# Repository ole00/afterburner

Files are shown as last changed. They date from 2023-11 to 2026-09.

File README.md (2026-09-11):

# afterburner
GAL chip programmer for Arduino
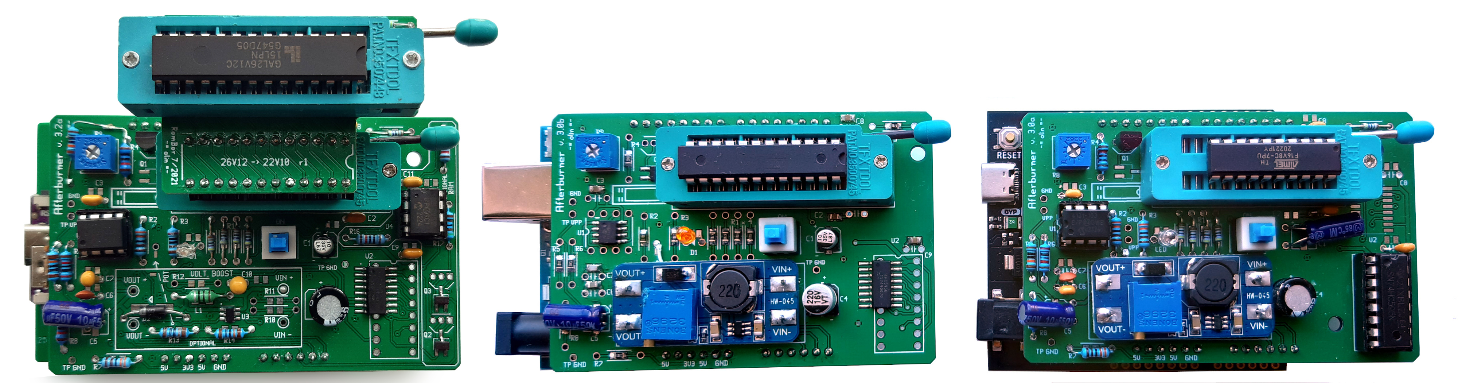
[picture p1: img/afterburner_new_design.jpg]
Board image afterburner


This is a GAL IC programmer software that allows to program GAL IC chips
from various manufcaturers. It is based on work of several other people:

 Bruce Abbott: 
     https://web.archive.org/web/20220121030038/http://www.bhabbott.net.nz/atfblast.html

 Manfred Winterhoff: 
     http://www.armory.com/%7Erstevew/Public/Pgmrs/GAL/_ClikMe1st.htm
 
 Yorck Thiele:
     https://www.ythiee.com/2021/06/06/galmate-hardware/

 Michael Dreher:
     https://github.com/nospam2000/afterburner.git
 
 Marcelo Roberto Jimenez: (JTAG player)
     https://github.com/mrjimenez/JTAG

 whitequark · it: (ATF150X jed to svf tool)
     https://github.com/whitequark/prjbureau

 OpenOCD: (svf to xsvf tool)
     https://github.com/arduino/OpenOCD/blob/master/contrib/xsvf_tools/svf2xsvf.py

who did the most of the hard work of deciphering and publishing the programming
protocol of these chips. Some of their early programs were Windows based and relied on
presence of parallel port (LPT). Afterburner was written for Linux OS 
(also works on Win32/64, Mac OSX64), and requires serial connection to
Arduino UNO, which does the programming of the GAL chip.

**Update: ver.0.6.2 added experimental support for PEEL18CV8. An dapter is required to
program PEEL devices because of their non-trivial programming voltages. The adapter
is located in the gerbers and design directories. Do not attempt to program the
PEEL device on Afterburner without the adapter! PEEL devices do not seem to have
a way to identify them, therefore the 'i' command is not supported.**

**Excerciser adapter was added to the collection of Afterburner adapters. The adapter
helps to develop and debug the PLD desgins on GAL/PEEL ICs. See Discussions for
more information.**

**Update: ver.0.6.0 added experimental support for ATF1502AS and ATF1504AS. Only
identify, erase and write commands are supported. Read function is unsupported.
Verification is usually done automatically - it is a part of the .xsvf JTAG file
which is used when writing the design. See Discussions for more information**

**Update: ver.0.5.8 improved calibration alogrithm and resolution for mcp4151 digi pot.
Please re-calibrate your Afterburner as the previsouly stored calibration data are invalid.**

Supported GAL and PEEL chips:
---------------------

| | Atmel | Lattice | Others ||
| --- | --- | --- | --- | --- |
| 16V8 | ATF16V8B, ATF16V8BQL, ATF16V8C | GAL16V8A, GAL16V8B, GAL16V8D | National GAL16V8, ST&nbsp;GAL16V8 |
| 18CV8 | - | - | ICT PEEL 18CV8P[2][4] |
| 18V10 | - | GAL18V10, GAL18V10B[1] | - |
| 20V8 | ATF20V8B | GAL20V8B | National GAL20V8 |
| 20RA10 | - | GAL20RA10, GAL20RA10B | - |
| 20XV10 | - | GAL20XV10B | - |
| 22V10 | ATF22V10B, ATF22V10C, ATF22V10CQZ | GAL22V10B, GAL22V10D | - |
| 6001 | - | GAL6001B | - |
| 6002 | - | GAL6002B | - |
| 26CV12 | - | GAL26CV12B[2] | - |
| 26V12 | - | GAL26V12C[2] | - |
| 750 | ATF750C, ATF750LVC | - | - |
| 150X | ATF1502AS, ATF1502ASL, ATF1504AS, ATF1504ASL[2][3] | - | - |

[1]: requires PCB v.3.1 or modified PCB v.3.0 - see Troubleshooting and 'afterburner_pcb_upgrades.pdf' document located in 
     design/afterburner directory <br/>
[2]: requires adapter - see gerbers, pcb and img directory. PLCC-28 package is supported by a specific adapter - do not use a common PLCC-28 to
     DIP-24 adapter as it does not work for GAL26CV12B with Afterburner.  
[3]: also supports 3.3V ATF1502ASV and ATF1504ASV when Arduino IOREF is 3.3V (ARM or ESP32 based Arduinos or Arduinos with IOREF 3.3V switch) <br/>
[4]: requires PCB v.3.2 or modified PCB v.3.1 or modified PCB v.3.0. See 'afterburner_pcb_upgrades.pdf' document located in 
     design/afterburner directory <br/>
[-]: - represents either this combination does not exist or hasn't been tested yet. Testers are welcome to report their findings.

**This is a new Afterburner design with variable programming voltage control and with single ZIF socket for 20 and 24 pin GAL chips.**
The PC software is backward compatible with the older Afterburner desgin/boards.
You can still access the older/simpler design here Afterburner legacy

The new design features:

* variable programming voltage control via digital potentiometer
* single 24 pin ZIF socket for 16V8, 20V8 and 22V10 GALs. The adapter for GAL20V8 is no longer needed.
* simpler connection to MT3608 module (no need to modify the module)
* both Through Hole and SMT footprints present on a single PCB. This allows
  to mix & match SMT and TH parts based on your skills and components availability.

Drawbacks compared to the old Afterburner design:

* more parts required, most notably the digital pot MCP4131 and a shift register 74hc595
* a few more steps during initial VPP calibration. But once the calibration is done it does not need to be changed for different GAL chips.
* the PCB design for etched  board is no longer provided because of the higher complexity. Please use a PCB fabrication service or use the older Afterburner design (see above).

Setup:
---------------------

* Upload the afterburner.ino sketch to your Arduino UNO. Use Arduino IDE to upload the sketch, both IDE version 1.8.X and 2.X should work.

* Build the Afterburner hardware. Buy the PCB from the an online PCB production service (use provided gerber archive in 'gerbers' directory). Then solder the components on the PCB - check the schematic.pdf and BOM.txt for parts list.

* Compile the afteburner.c to get afterburner executable. Run
  ./compile.sh to do that. Alternatively use the precompiled binaries in the 'releases' directory.

* Calibrate the variable voltage. This needs to be done only once, before you start using Afterburner for programming GAL chips.
  Calibration procedure differs a little bit when using MT3608 module or when using on board voltage booster.

  **When using MT3608 module**

  * **Calibration step 1)** Turn the small potentiometer (R9) on the Afterburner to the middle position. This pot acts as compensation resistor for the digital pot.

  * **Calibration step 2)** Set the programming voltage (VPP) to 16.5V: Check the programming voltage (VPP) without the GAL chip being inserted / connected to Afterburner. Test the voltage on MT3608 module VOUT- and VOUT+ pins while running the following command:
  <pre>
  ./afterburner s
  </pre>
  While the command is running turn the pot on the MT3608 module (not the Afterburner's pot) counter clockwise (5 to 20 full turns). The VPP voltage should be displayed on the console, but for the very first setup use a multimeter to verify the VPP voltage as well.
  Re-run the command (if needed) to give you more time to set the 16.5V VPP.

  * **Calibration step 3)** This step scans the available voltages and records the pot taps. Run the following command:
  <pre>
  ./afterburner b
  </pre>
  You will see several messages on the console. Check the one with '*Index for VPP 900 is'. This is the lowest supported VPP of 9V and the index should ideally be between 30 and 70, but if it a bit less or a bit higher (let's say from 20 to 90) the calibration should still be valid. 
  If you see a significantly different index value (lower or higher) move the Afterburner's compensation pot (R9) either a bit lower or higher (depending on the VPP 900 index value) and go back to Calibration step 2). Repeat the Calibration steps 2) and 3) until you find the good value on VPP 900 index. If everything goes OK the last VPP index (VPP 1650) should be 255. If it is not exactly 255, but at least above 250 then it is fine. 

  * **Calibration step 4)** Measure the actual VPP to verify the value read by Arduino is correct. Run the following command while measuring the VPP on your multimeter:
  <pre>
  ./afterburner m
  </pre>
  Afterburner will set the VPP to several values (5V, 9V, 12V, 14V, 16V) and print the voltage readings as read by Arduinos's ADC. These values should match with readings from your multimeter (except for the 5V which is OK if it is a value from 4.2V - 5.0 V). Important are the values of the higher voltages. If they are off by more than +/-0.05V then you can set the calibration offset by running Calibration step 3) with an extra parameter '-co X':
  <pre>
  ./afterburner b -co X
  </pre>
  Where X is a number from -32 (representing -0.32V offset) to value 32 (representing +0.32V offset). If your multimeter reads 12.1V and the reading on the text console shows 12.00V you need to set positive offset of +0.1V ('-co 10'). If your multimeter reads 11.85V and the reading on the text console shows 12.05V you need to set negative offset of -0.2V ('-co -20'). After setting the calibration offset, the readings on your multimeter should ideally read the same values as the text on the console (+/- 0.05V). The calibration is then done. If (when specifying negative offset value) the calibration fails, turn the MT3608 Pot about 10-15 degrees counter-clockwise (to rise the VPP a tiny bit) and re-do the Calibration step 3.

  * Note that if you use your calibrated Afterburner board with a different Arduino (made by a different company or slightly different design), you may need to re-do the calibration.

**When using on-board voltage booster:**

Calibration steps are the same as for MT3608 module with these differences

* **Calibration Step 2)** We can't turn the extra pot on the MT3608 module, but we can
adjust the voltage by turning the R9 pot on the Afterburner PCB. It's OK to have
the voltage a bit higher like 16.6V or so in this calibration step.

* **Calibration Step 3)** Because of the feedback resistance difference compared to MT3608
module the calibration index for 9V will be around value 150.

**GAL chip operations:**
* With the GAL chip inserted and power button pressed (or in ON position) check the chip identification by running the following command:
  <pre>
  ./afterburner i -t [GAL_type]
  </pre>

  If you get some meaningful GAL chip identification like:
  <pre>
  PES info: Atmel ATF16V8B  VPP=10.0 Timing: prog=10 erase=25
  </pre>
  then all should be well and you can try to  erase the chip and then program it to contain your .jed file.

  If you get an unknown chip identification like:
  <pre>
  PES info: 3.3V Unknown GAL,  try VPP=10..14 in 1V steps
  </pre>
  then look at the troubleshooting section

* Read the content fo your GAL chip. This only works if the contents
  of the chip is not protected. Use the following command:
  <pre>
  ./afterburner r -t [GAL_type]
  </pre>
  or to save the printed .jed fuse map  to a file use:
  <pre>
  ./afterburner r -t [GAL_type] > my_gal.jed
  </pre>
  
* Erase the GAL chip. Before writing / programming the chip it must
  be erased - even if it is a brand new chip that has not been used 
  before. Use the following command:
  <pre>
  ./afterburner e -t [GAL type]
  </pre>

* Program and verify the GAL chip via the following command:
  <pre>
  ./afterburner wv -t [GAL type] -f my_new_gal.jed
  </pre>

* If you are not sure which GAL type strings are accepted by Afterburner, simply set a wrong type and it will print the list of supported types: 
  <pre>
  ./afterburner wv -t WHICH
  </pre>

How aferburner works:
---------------------
- PC code reads and parses .jed files, then uploads the data to Arduino via serial port. By default /dev/ttyUSB0 is used, but that can be changed to any other serial port device by passing the following option to afterburner:
  <pre>
  -d /my/serial/device
  </pre>

- PC code of afterburner communicates with Arduino UNO's afterburner
  sketch by a trivial text based protocol to run certain commands (like erase, read, write, upload data etc.). If you are curious, you can also connect directly to Arduino UNO via serial terminal and issue some basic commands manually.

- Arduino UNO's afterburner sketch does 2 things: 
  * parses commands and data sent from the PC afterburner app
  * toggles the GPIO pins and drives programming of the GAL contents

- more information about GAL chips and their programming can be found here:

  http://www.bhabbott.net.nz/atfblast.html
  
  http://www.armory.com/%7Erstevew/Public/Pgmrs/GAL/_ClikMe1st.htm 

PCB:
---------------
The new design no longer has an etched PCB design available. The most convenient way to get the PCB is to order it online on jlcpcb.com, pcbway.com, allpcb.com or other online services. Use the zip archive stored in the gerbers directory and upload it to the manufacturer's site of your choice.
  Upload the afterburner_fab_3_0.zip and set the following parameters (if required). 
  
  * Dimensions are 85x54 mm
  * 2 layer board
  * PCB Thickness: 1.6, or 1.2
  * Copper Weight: 1
  * The rest of the options can stay default or choose whatever you fancy (colors, finish etc.)
  
Soldering steps:
----------------
  * check which type of components you have, you can mix and match SMT and through hole components as most of the footprints are doubled to accommodate different parts.
  * **Important:** C5, C6 and C7 are VPP decoupling capacitors and must be rated to **at least 25V!** You can use 50V rated caps, but do not use 16V or lower ratings.
  * Even though C5 (10uF, 25V) offers a SMT footprint, I used a through hole part because it reduces the VPP swings better than my SMT cap.
  * start with the smallest parts, solder the resistors and small capacitors.
  * solder the two ICS: U1 (digital pot) and U2 (shift register)
  * solder the LED, the switch and the big capacitors

  **When using MT3608 module**
  * do **not** solder any components in voltage booster area
  * **special step** solder a thin wire between the MT3608 module and the PCB hole marked as POT. See the image bellow.
  * **Important** after you solder the wire measure the resistance between the wire's connection on Afterburner PCB and ground (use TP GND hole) - see red dots
     on the picture beelow.  It must be around 12.5 kilo Ohm. If it is very low value then you made a short while soldering the wire. Fix/remove the short
     or else the MT3608 will be damaged when it is turned on on.
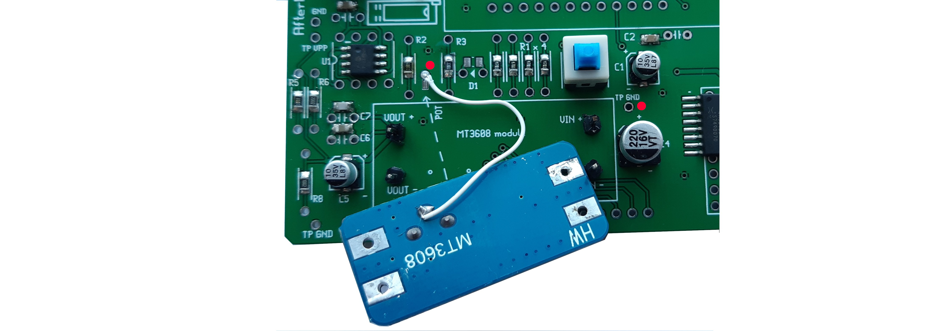
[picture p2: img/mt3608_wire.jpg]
POT wire image. POT wire
       
  * solder the MT3608 module - the POT connection wire must be already soldered!

  **When using on-board voltage booster**
  * solder the parts in the voltage booster area. Start with the U3 IC - the SOT-23-6 package - so that you have plenty
    of room for soldering the small IC. Use a flux to ensure the solder melts nicely on the pads.
  * solder the inductor L1 and diode D2. Ensure D2 polarity is correct - the stripe is on the left side (see photos if unsure).
  * solder the C10 cap and the resistors. There is no need to solder R10, R11, R12 if you are using the alternative booster IC
    with SOT-23-5 package (without OVP)
  * no extra wire is required (the wire is only required when using MT3608 module)

  **After soldering the voltage booster** 
  * calibrate the board. See calibration steps in the Setup section.
  * solder the ZIF socket

MT3608 modules:
---------------
  * On PCB version 3.2 (or higher) the MT3608 can be replaced by discrete parts soldered on the board. Therefore, if you want to avoid possible issues with
    MT3608 modules, solder the discreate parts instead of the module. If you are not comfortable soldering SOT-23-6 SMT IC package, then use the MT3608 module.
  * There is a report some of the MT3608 modules / clones are not compatible with Afterburner. Thanks @meup for the information.
  * The incompatible MT3608 'clone' causes calibration issue and basically breaks the variable voltage functionality. This can be fixed by replacing the 2k2 resistor located on the module by a 15k resistor.
  * Bellow is the image of the old (compatible without a mod) and new (require the resistor mod) MT3608 modules. If you happen to have the incompatible module here are the steps to replace the resistor:
      - heat up a soldering iron to ~350 deg C and put a medium sized solder blob on its tip
      - touch the tip of the iron in the middle of the resistor for a second
      - gently press on the resistor and slide it off the PCB.
      - the resistor footprint allows to solder new SMT or through hole resistor
  
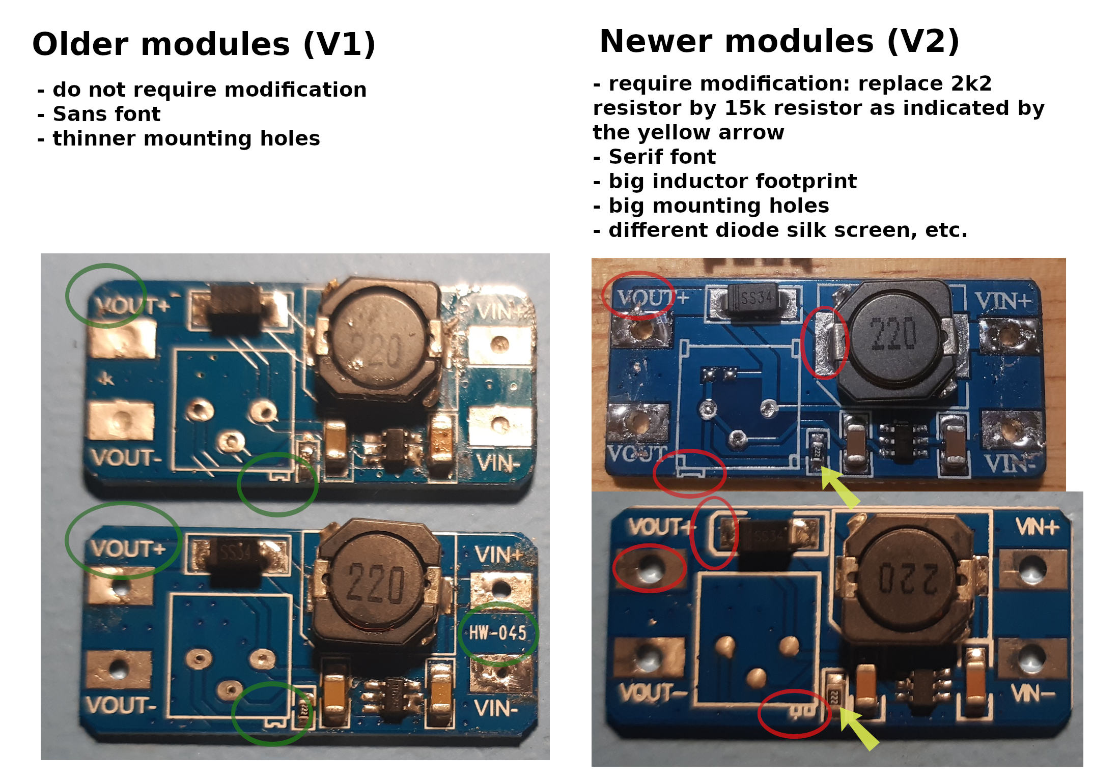
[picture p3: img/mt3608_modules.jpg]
mt3608_modules
  

3D printed case:
----------------
There is a model of a case/enclosure designed for 3D printers in the 'case' directory. The following three printed parts/pieces are required for a complete enclosure: top, bottom and switch button parts. 
There are 2 sets of STL files provided: One for Arduino UNO R3 with USB-B connector, and the other for Arduino UNO R4 with USB-C connector. The STL file names of these sets are clearly distinguished.
The enclosure design has more options available - like an option to have VPP measurement holes, option to disable Afterburner text and others. These can be enabled in design file (atf3x.scad) presets
when it's opened in OpenScad editor. 

To export STL files from OpenScad:

* ensure you have the right part (and only the right part) enabled in the options (top, bottom or button switch).
* press F6 and wait for the model to be calculated.
* press F7 to export the STL file of the part.

When slicing the models, ensure the model supports are enabled, especially for the top part requires that.

The top and bottom parts are joined together with M3 screws and M3 threaded heat inserts.

Bellow are 2 variants of the enclosure, the one on the left has VPP measurement holes. Ususally the VPP calibration/measurement holes
are not required as the VPP calibration can be done before the PCB is put into the case.

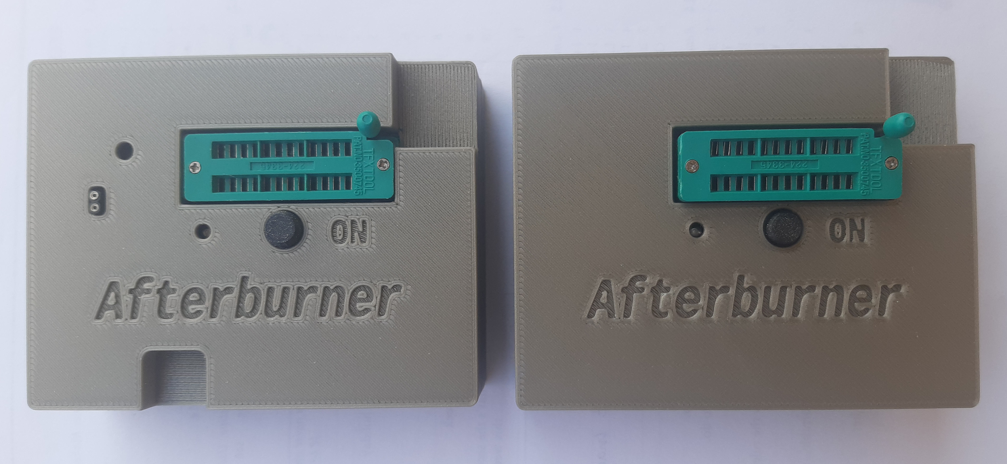
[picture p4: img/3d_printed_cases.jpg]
mt3608_modules 3D printed cases
  

If the top and bottom printed parts can't be easily joined and something seems to be blocking please check:
- the LED is precisely positioned to fit
- the through hole ceramic capacitors around the ZIF socket are not too close to the ZIF socket. Bend them a bit if they are too close.
- the through hole Mosfet is not too close to the ZIF socket
- check that other components, especailly through hole are not sticking high above the Afterburner's PCB. The case was designed
  and tested with through hole components, but if the compoenent leads are too long the component might block the case.
- ensure the button's cut/flat part is facing the ZIF socket, the round bit is facing away from the ZIF socket.

Exerciser adapter:
------------------

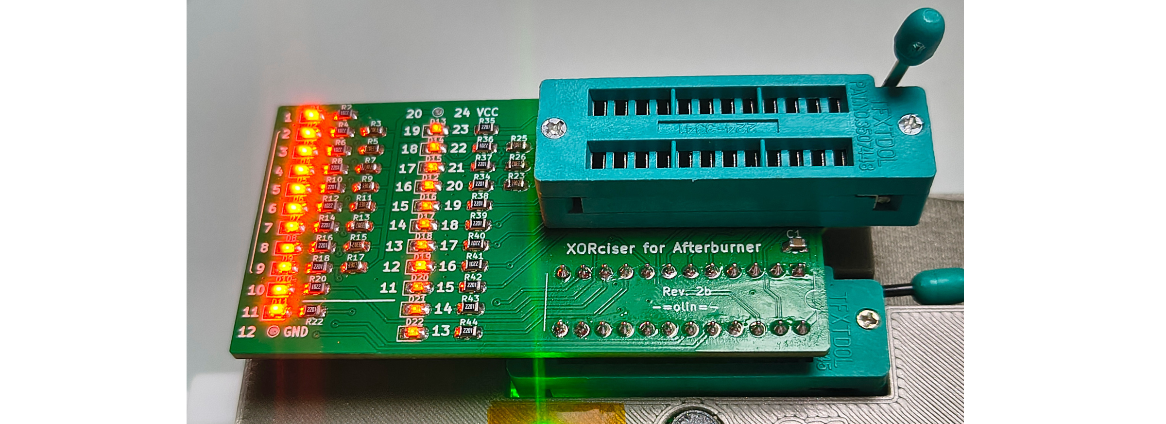
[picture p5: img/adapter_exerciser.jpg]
mt3608_modules exerciser adapter
 

The adapter helps to develop and debug PLD designs on 20 and 24 pin GAL and PEEL devices.
It helps to visualise inputs and outputs from the PLD IC via LEDs. The developer
plgugs the PLD IC into the adapter and runs a text script that describes a series
of test steps. Each test step defines the High/Low state of input pins and defines
the output pins as high impedance (Z  state). During the test, each test step is 
applied on the IC and the IC produces its outputs on the output pins - their state
is displayed on the LEDs, so that the output values can be validated.
The afterburner PC app supports running the exercising scripts by using 'x' command
as follows:
<pre>
./afterburner -f test_script.xor x
</pre>

An example of the test script is in the Discussions.
If you do not have the exerciser adapter, you can use a breadboard with LEDs and use
jumper wires to connect to Afterburner's ZIF socket. Using the adapter is more robust
solution that should last longer than a wired breadboard.

Troubleshooting:
----------------
- it does not work!

  * double check the solder joints on the PCB, ensure they are soldered. Especially SMT soldering when done manually can accidentally miss some of the pads. 
  
  * ensure the GAL chip is inserted to the IC socket the right way (check 
  the pin 1 location). Note that the 16V8 GALs have to be inserted close to the ZIF lever - see the title image above.
  
  * ensure the VPP is set correctly on the MT3608 module. Ensure you've gone through all the calibration steps (commands: 's' then 'b' and 'm') and calibration is correct. See the Setup section.

- what is the Push switch used for? When do I use it?
  * Normally, the button should be in the Off position (LED is not lit). Also when inserting
    the GAL chip or when removing the GAL chip from the ZIF socket the switch should be Off.
  * When using Afterburner's PC app with commands to Identify (i), Read or Verify (r, v) or 
    Write (w) the switch has to be On (LED is lit).
  * So in general: insert the GAL when the switch is Off, then turn the switch On, run the 
    PC app command. When finished turn the switch Off, remove the GAL chip from the socket.

- afterburner reports it can not connect to /dev/ttyUSB0, permission denied

  * ensure your user is member of the of the dialup group or alternatively run
  afterburner  as superuser (use: sudo ./afterburner ...)

  * ensure no other program on your PC uses that serial port. Close putty, minicom or other
  terminals you may be running.

- afterburner fails to connect to /dev/ttyUSB0

  * ensure your PC is actually connected to Arduino UNO, check a serial device
  exists:
  <pre>
  ls -alF /dev/ttyUSB*
  </pre>

- I can't program GAL18V10
  * You'll need PCB version 3.1. If you have PCB version 3.0 you can mod it.
    See the 'afterburner_pcb_upgrades.pdf' document in design/afterburner directory that lists the modding steps.
    Also, see here for more information about the mod.
  * Some GAL18V10B from Aliexpress do not work with Afterburner (fakes? damaged?).
    My GAL18V10B-15LP from Aliexpress do not work. However, GAL18V10B-**20LP** do work OK (also from Aliexpress).

- I can't program PEEL18CV8P
  * You'll need an adapter and Afterburner PCB version 3.2. If you have  PCB version 3.0 or 3.1 you can mod your PCB to
    support the new IC (with the adapter). See the 'afterburner_pcb_upgrades.pdf' document in design/afterburner
    directory that lists the modding steps.

 - I built PEEL18CV8 adapter, how do I check it works OK?
   * First, ensure you have Afterburner PCB version 3.2 or more recent. If you have older versions, then you need to mod
     your Afterburner's PCB. See above.
   * Second, ensure you have the latest Afterburner's sketch uploaded and you are using the latest PC app.
   * Run the following command to verify your build of PEEL18CV8 adapter:
     <pre>
     ./afterburner -t PEEL18CV8 m
     </pre>
     Ensure the commnd runs with no IC plugged in the ZIF socket and with the Power button turned on (LED is lit).
     The commands sets the voltages on the test points TP2 to TP5 which you need to measure with multimeter.
     Repeat the command to measure all test points and check that the voltages on those test points
     match the values displayed on the console. If the voltages are within tolerance of +/- 0.3V then the adapter
     should be OK. If not, ask in the discussion section. Common issues when building the adapter
     are reversed pinouts of MOSFETs or MOSFET damage due to excess temperature during soldering. Also, check
     the resistors on the adapter have the right values as per the schematic located in the adapter's design
     directory.

- I want to program ATF16V8C, but it is not listed as supported by the PC app.
  * use parameter '-t ATF16V8B'. Afterburner finds out it is a C version.

- I forgot to solder the POT wire to the MT3608 module. The MT3608 is already soldered and I can't reach underneath the module to solder the wire.

  * you can either desolder the module by using soldering wick (to remove all solder on the connection pins on the MT3608 module). Then use a low temperature melting solder (like Quick Chip or similar) on the connection joints to loosen up the module. Clean the residues of the low melting solder with soldering wick. Then solder the POT wire and solder the chip back on the PCB. The drawback of this method is that if you use excessive heat during desoldering you can damage the MT3608 module (I've done that). If the module is damaged, it will produce a magic smoke next time the board is turned on. If that happens, desolder the module, use a new module (don't forget to solder the POT wire) and solder it on the board.

  * Another option is to connect the POT wire directly to the MT3608 IC's Feedback (FB) pin 3. This is quite delicate as the IC pins are quite small. Before connecting the power, **ensure the pin 2 and pin 3 are not bridged!**

  <pre>
  |  Blue Potentiometer     |
  |_________________________|
  |   ______________
  |  |              |
  |  | SMT Capacit. |
  |  |______________|
  |
  |   3  2  1
  |-> |  |  |         MT3608 MODULE
  |  +-------+
  |  |       |
  |  |4  5   |
  |  +-------+
  |   |  |  |
  |
  |<-- left long edge of the module
  </pre> 

  * The small arrow (->) in the above diagram marks the pin where the wire has to be soldered.

- my MT3608 module does not seem to work - turning the pot does nothing

  * The pot needs to be turned at least 10 revolutions counter-clockwise
  to do anything useful. Keep turning.

- where to get the MT3608 module ?

  * usual places: ebay, aliexpress
  * **IMPORTANT - check the module compatibility - there are some incompatible modules (see above)**

- how to run afterburner on Win32, Win64 or MacOSX ?
  * the same way as on Linux: compile the source code
  * OR use pre-compiled afterburner binaries located in 'releases' directory
  * then run afterburner in terminal (use 'cmd' on WinXX) as described above
  * ensure your serial device name is passed via '-d' option. For example -d COM5 on WinXX

- I have the older Afterburner PCB design, can I use the new PC software and Arduino sketch?
  * Yes, both programs are compatible with the old Afterburner boards (1.X and 2.X).
 
- Which Arduino is compatible with Afterburner?
  * Arduino UNO and many Arduino UNO clones that operate on 5V are compatible. If you already have have
    a 3.3V based UNO, you can try it but it may not work with certain GAL chips. See discussion for more info.
  * Original Arduino Leonardo is supposed to work without modifications. Tested on DFRobot Leonardo board which works fine.
  * Arduino MEGA2560 and clones should work without modifications.
  * Arduino NANO works, but requires a UNO break-out board adapter. See bruno-nano adapter (https://github.com/ole00/bruno-nano).

- how do I program ATF150X ICs? They do not fit into the ZIF Socket.
  There are 2 options. Either use PLCC44 IC package along with the ZIF socket adapter (see the gerber and
  pcb directory). Or you can program the ATF150X on your target board when using JTAG interface.
  See this schematics for information about JTAPG pins on ATF150X ICs:
  http://matthieu.benoit.free.fr/all03/adp/HiLo_ADP-ATF1504.PDF
  The OGI pin in the schematic is VPP (or EDIT) pin on afterburner. See afterburner schematics
  how to connect JTAG pins from the ZIF socket into the JTAG pins on your board.

- what are the .jed files and how to produce them
  
  * Use WinCUPL software from Atmel. Works under Wine as well.
  
  https://www.microchip.com/design-centers/fpgas-and-plds/splds-cplds/pld-design-resources
  
  * WinCUPL User's manual: http://ww1.microchip.com/downloads/en/DeviceDoc/doc0737.pdf
  
  * Try GAL Asm to produce .jed files - see link bellow.

  * Try Yosys4gal to produce .jed files from Verilog HDL files: https://github.com/annoyatron255/yosys4gal

- can I use .jed files with ATF150X IC?
  * Not directly. You have to convert the .jed file into .xsvf format. Use the python tools located in the utils/jtag
    subdirectory to do that. See readme.txt in that directory for more info. Once you convert the .jed to .xsvf
    you can use it with afterburner like that:
    <pre>
    ./afterburner -t ATF1502AS -f mydesign.xsvf ew
    </pre>
    which will erase the chip and then write your design into the IC.
    See discussion #64 (ATF1502AS(L) and ATF1504AS(L) support) for more inofrmation.

Other GAL related links:
------------------------
- GAL chip info: https://k1.spdns.de/Develop/Projects/GalAsm/info/galer/gal16_20v8.html

- GAL chip programming protocol info: https://k1.spdns.de/Develop/Projects/GalAsm/info/galer/proggal.html

- GALmate: another open source GAL programmer: https://www.ythiee.com/2021/06/06/galmate-hardware/
  
- JDEC file standard 3A: https://k1.spdns.de/Develop/Projects/GalAsm/info/JEDEC%20File%20Standard%203A.txt
  
- GAL Asm : https://github.com/dwery/galasm

- GAL Asm online compiler: https://rhgndf.github.io/galasm-web/

- GAL Verilog compiler: https://github.com/annoyatron255/yosys4gal

- PLD and GAL info: https://github.com/peterzieba/5Vpld

- Fusemap info:
    * https://blog.frankdecaire.com/2017/01/22/generic-array-logic-devices/
    * https://blog.frankdecaire.com/2017/02/25/programming-the-gal22v10/
 
- CUPL Reference: https://web.archive.org/web/20220126145737/https://ee.sharif.edu/~logic_circuits_t/readings/CUPL_Reference.pdf

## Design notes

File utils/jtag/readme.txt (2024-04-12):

JTAG conversion tools
---------------------------------------

fuseconv.py : converts ATF150X .jed file into .svf file

   The origin of the conversion tool is this git repo:
   https://github.com/whitequark/prjbureau

svf2xsvf.py : converts .svf file into .xsvf file 

  The origin of the tool is this git repo:
  https://github.com/arduino/OpenOCD/tree/master/contrib/xsvf_tools

Typically you produce a .jed file for your ATF150X device either by
WinCUPL or by ATF15XX_Yosys (https://github.com/hoglet67/atf15xx_yosys/)
and then run fuseconv.py and svf2xsvf.py to produce .xsvf file that can be
used by Aftereburner's JTAG player.

See example_jed2xsvf.sh for more information how to run these tools.

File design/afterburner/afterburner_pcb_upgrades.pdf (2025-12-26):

Afterburner - PCB upgrades
Document Ver. 1.1
1) Introduction

Afterburner PCBs underwent several changes over time. The very early PCBs (versions 2 and older) did not support variable programming voltage. These are no longer actively supported, however they still work with the current Arduino sketches and PC App version 6.x. This documents focuses on PCB versions 3.0 and 3.1 and provides instructions how to partially upgrade them to allow programming of certain PLD chips.

2) PCB versions

PCB 3.0 Does not support:
- GAL18V10
- PEEL18CV8 (needs an extra adapter)

PCB 3.1 Does not support:
- PEEL18CV8 (needs an extra adapter)

First, check which Afterburner version you have and whether you need to program the above ICs. If you don't need to program the above ICs then there is no point of upgrading your Afterburner PCB, unless you want to have the PCB fully featured.

If you have PCB 3.0 and you want to only add support for GAL18V10 then you need to do PCB 3.0 to PCB 3.1 mod. Otherwise you need the PCB 3.0 to PCB 3.2 mod, or PCB 3.1 to PCB 3.2 mod.

3) PCB 3.0 to PCB 3.1 mod

This mod requires to:
- desolder the right-most resistor of the R1 group (next to the switch)

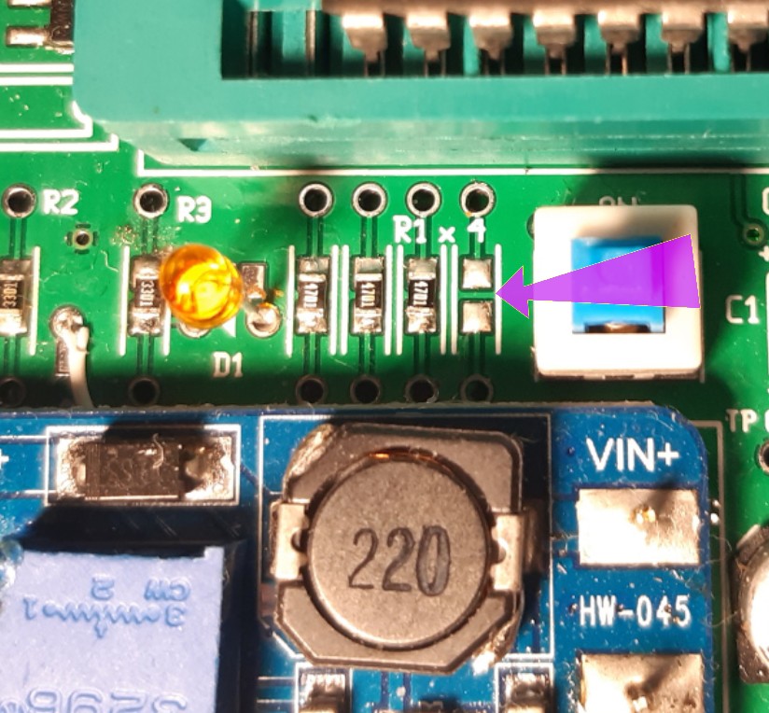
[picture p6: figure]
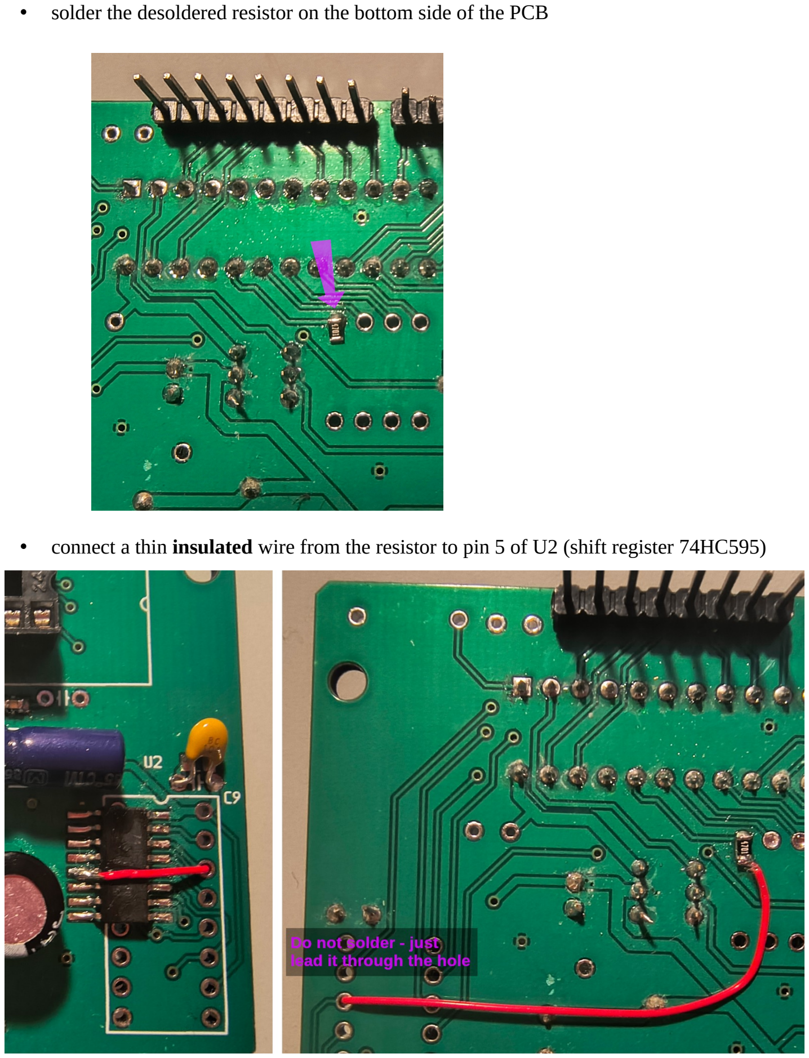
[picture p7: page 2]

- solder the desoldered resistor on the bottom side of the PCB
- connect a thin insulated wire from the resistor to pin 5 of U2 (shift register 74HC595)

4) PCB 3.1 to PCB 3.2 mod

This mod requires to:
- desolder the middle 2 resistors of the R1 group (on PCB 3.1 keep the 1st and the 4th resistor soldered)

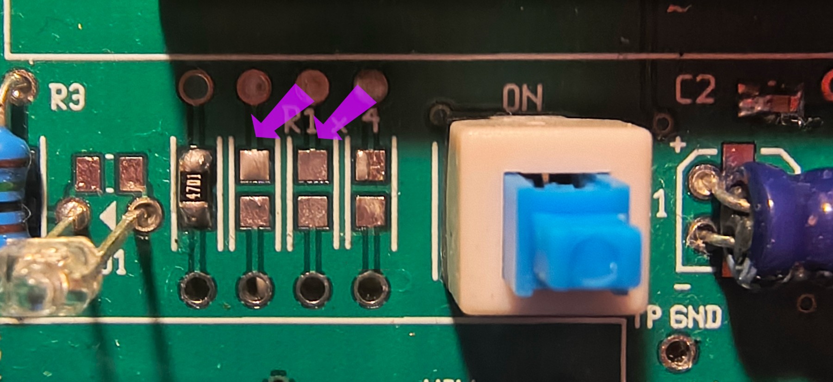
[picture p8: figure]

- solder the desoldered resistors on the bottom side of the PCB
- connect a thin insulated wire from each resistor to its appropriate pin (6 and 7) of U2 (shift register 74HC595).

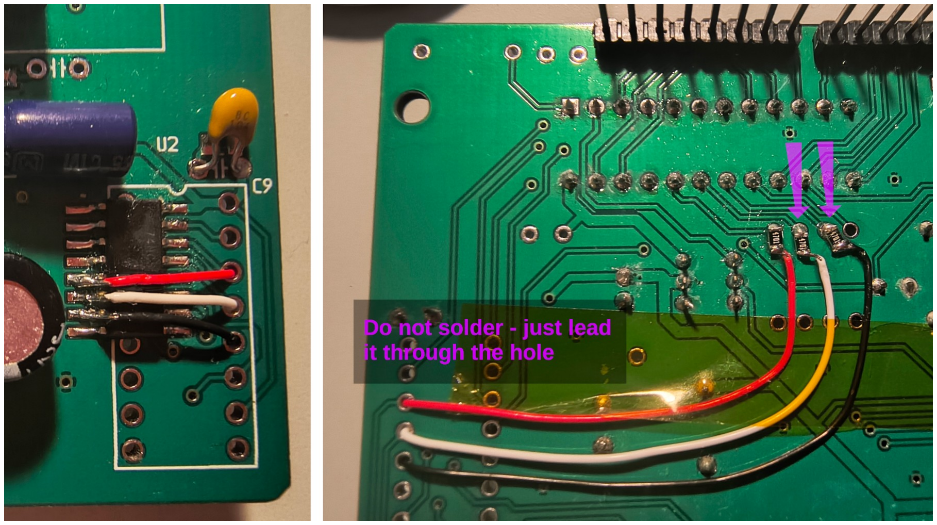
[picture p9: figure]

Before plugging the PCB to Arduino ensure that the soldered wires are not bridged between each other and also they are not shorted to ground. Use multimeter in continuity mode to check that.

Notes:
- on PCB 3.1 there is no need to do the Red wire and its resistor mod - the board already has the mod in the design. Just do the white and black wire mod with its resistors.
- if you want to upgrade from PCB 3.0 to PCB 3.2 then do both of the mods.

- if you use Through Hole resistors then the steps are the same. Ensure the resistor wires do not touch exposed holes or other pads on the bottom of the PCB. Use kapton tape to insulate the holes and resistors.
- If you use Through Hole U2 IC (595 shift register) then solder the new wires to the U2 IC on the bottom of the board. Red wire: U2 pin 5, White wire U2 pin 6, Black wire U2 pin 7. See the picture bellow. Note that there is a kapton tape under the resistors to prevent the resistor leads to touch the exposed GND holes.

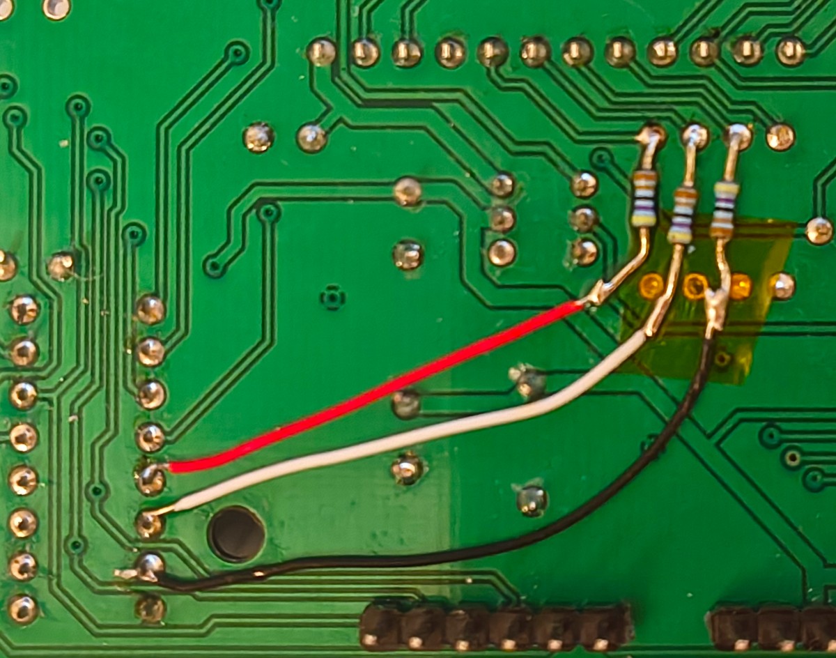
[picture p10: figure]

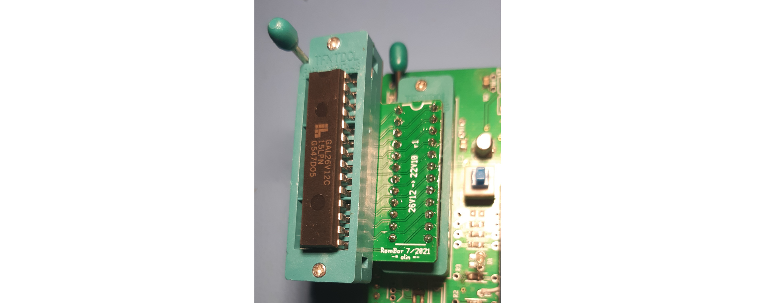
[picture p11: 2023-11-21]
img/adapter_26v12.jpg

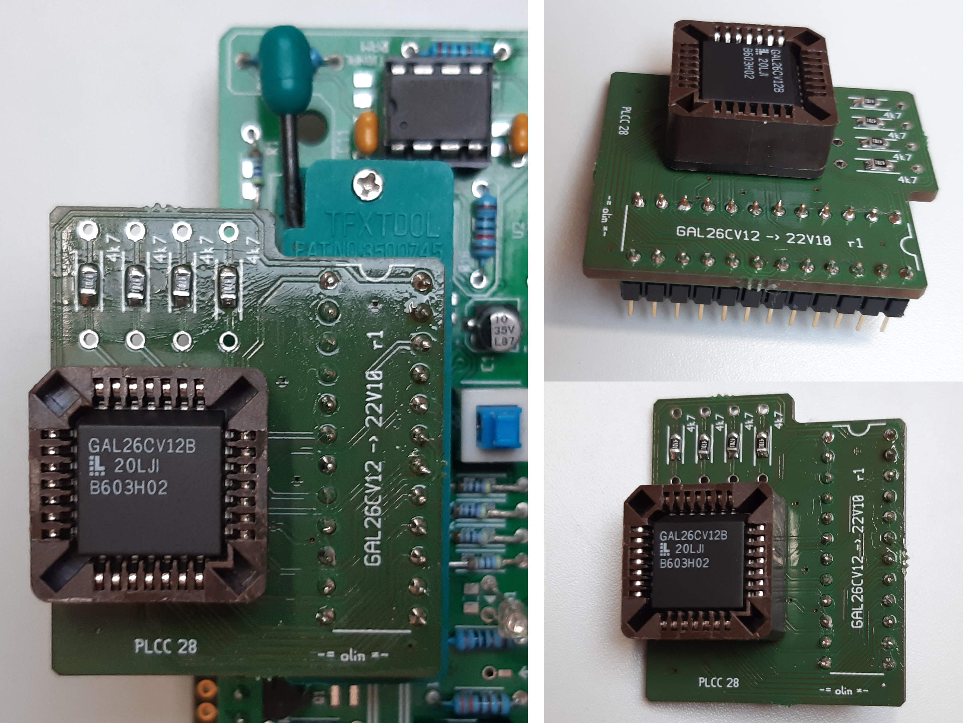
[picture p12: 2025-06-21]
img/adapter_26cv12_plcc28.jpg

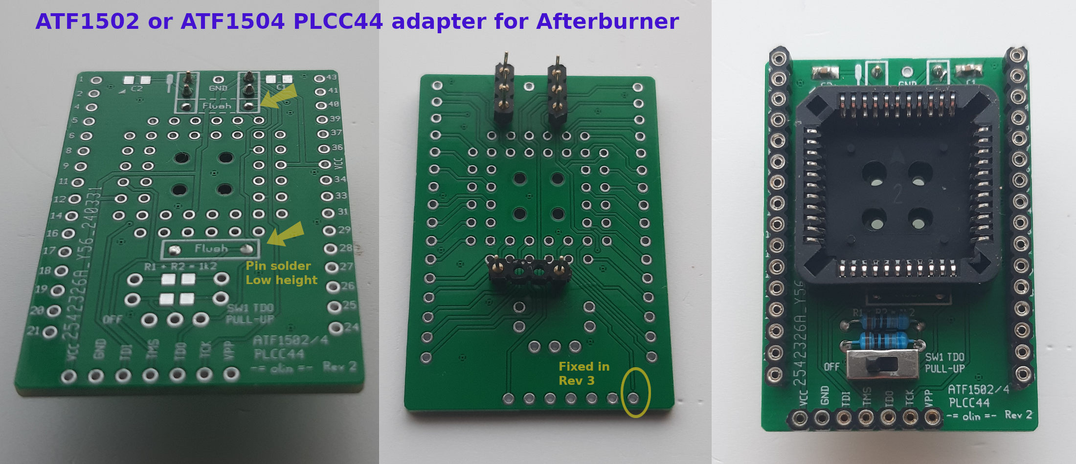
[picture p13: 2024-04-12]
img/atf150x_adapter.jpg

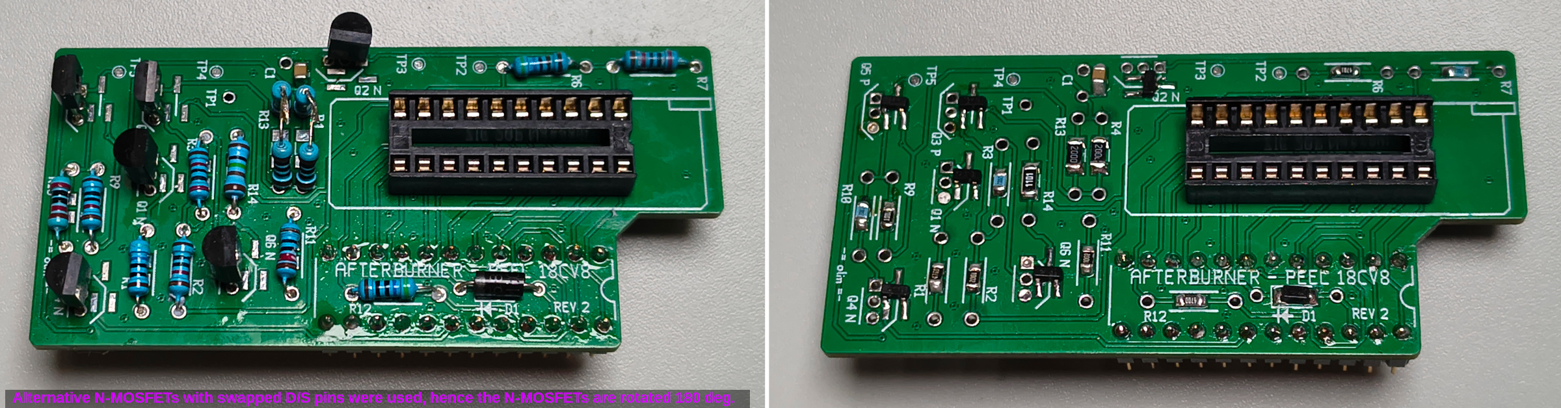
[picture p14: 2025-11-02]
img/adapter_peel18cv8.jpg

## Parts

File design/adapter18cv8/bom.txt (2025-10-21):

BOM for PEEL 18CV8 Afterburner adapter
=======================================
* (C1) Capacitor ceramic 1uF 20V  SMT 0805 or TH, 1x
* (D1) Schottky diode 1N5817 or 1N5818  20V  SMT SOD-123 or TH, 1x
* (Q1, Q2, Q4, Q6) N-MOSFET Enhancement 50V 500mA VGS +/-20V  SMT SOT-23-3 TH TO-92  for example PJA138K-AU or BS170 or VN10LP , 4x
* (Q3,Q5) P-MOSFET Enhancement 50V 500mA  VGS +/-8V  SMT SOT-23-3 TH TO-92 for example NTR4101PT1G or  VP2106, 2x

* (R1, R12) Resistor 470R (TH or SMT 0805) 0.12W  5% or better, 2x
* (R2, R9, R11) Resistor 10k  (TH or SMT 0805) 0.12W  5% or better, 3x
* (R3, R7, R10) Resistor 20k or 22k (TH or SMT 0805) 0.12W 5% or better, 3x
* (R4, R5) Resistor 200R or 220R (TH or SMT 1206 or 0805) 0.5W 1% or better, 2x
* (R8) Resistor 1k (TH or SMT 1206 or 0805) 0.25W 5% or better, 1x
* (R6) Resistor 4k7 (TH or SMT 0805) 0.12W 1% or better, 1x

* (J1) Pin heeader connector 2.54 mm (100mil) pin pitch, round pins
* (J2) 20 pin ZIF Socket narrow

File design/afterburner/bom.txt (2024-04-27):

BOM for Afterburner PCB 3.2b
============================
* (R1 - 5x) Resistor 4k7 (TH or SMT 0805) 0.25W, 5% or better tolerance  - 5x
* (R8, R4) Resistor 10k (TH or SMT 0805) 1% or better tolerance - 2x
* (R5, R18) Resistor 100k (TH or SMT 0805) 1% or better tolerance - 2x
* (R6) Resistor 20k (TH or SMT 0805) 1% or better tolerance - 1x
* (R7, R3, R2) Resistor 3k3 (TH or SMT 0805) 1% or better tolerance - 3x
* (R9) Cermet trimmer (TH Suntan TSR-3362P-202R 2k) - 1x

* (C1, C5) Capacitor electrolytic 10uF, 25V or 50V, 20% tolerance or better (through hole) - 2x
* (C4) Capacitor electrolytic 220uF, 16V or higher, 20% tolerance or better (through hole) - 1x
* (C2, C3, C8, C9) Capacitor ceramic 100nF 10V or higher (TH or SMT 0805) - 4x
* (C6) Capacitor ceramic 100nF 25V or higher (TH or SMT 0805) - 1x
* (C7) Capacitor ceramic 2nF 25V or higher (TH or SMT 0805) - 1x

* (D1) 5mm LED (TH or SMT 0805) - 1x
* (Q1) N-MOSFET (SMT: BSS138P - SOT23 or TH: BS170G - TO92, or similar)  - 1x

* (U1) MCP4131-103 (DIP or SOIC) Digital potentiometer 10k - 1x
       Alternatively MCP4151-103 can be used as well.
* (U2) 74HC595 (DIP or SOIC) Shift register - 1x

* 24 pin narrow ZIF socket OR 24 pin DIP IC socket 0.1" pin spacing - 1x
* MT3608 module - 1x
* Square 7x7x12mm 6 Pin DPDT Mini Push Button Self-locking Multimeter Switch (YTSPS-22E70L, 2mm pin spacing) - 1x
* 40 Pin Male Single Row Strip 2.54mm Pin Header Connector 0.1" Straight - 1x
* Arduino UNO

OPTIONAL features
-----------------
on-board voltage booster (replacement for MT3608 module)

* (R10, R13 ,R14) Resistor 100k (TH or SMT 0805) 1% or better tolerance - 3x
* (R11) Resistor 4k7 (TH or SMT 0805) 0.25W, 1% or better tolerance  - 1x
* (R12) Resistor 3k3 (TH or SMT 0805) 1% or better tolerance - 1x
* (C10) Capacitor ceramic 1uF, 9V or higher (TH or SMT 0805) - 1x
* (D2)  Diode Schottky SK14, 1A 40V (SMT package DO-214AC-2 )
        or alternative TH Schottky diode 1N5818
* (L1)  Inductor 10uH, NLCV32T-100K-PF  (SMT package 1210)
        or alternative TH: AICC-02-100K-T Axial inductor
* (U3)  Voltage booster MIC2619 (SOT-23-6) with over voltage protection (OVP)
        or alternative MIC2250  (SOT-23-5) without OVP, R10, R11 and R12 not required
        or possibly TPS61040DBVR (SOT-23-5) without OVP - not tested yet

SPI-RAM: extra memory for UNO (not used ATM. Can be soldered later if needed)

* (R15, R16)  Resistor 10k (TH or SMT 0805) 5% or better tolerance - 2x
* (R17) Resistor 4k7 (TH or SMT 0805) 0.25W, 5% or better tolerance  - 1x
* (C11) Capacitor ceramic 100nF 10V or higher (TH or SMT 0805) - 1x
* (Q2,Q3) N-MOSFET (SMT: BSS138P - SOT23 or TH: BS170G - TO92, or similar)  - 2x
* (U4)  SPI-RAM 5V, 23LC1024, DIP or SOIC-8, alternative 23LC512 or 23LCV512 or 23LCV1024

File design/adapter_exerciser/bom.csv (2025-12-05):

Reference | Qty | Value | DNP | Footprint | Datasheet
C1 | 1 | 100nF |  | Capacitor_SMD:C_0805_2012Metric_Pad1.18x1.45mm_HandSolder | ~
D1,D2,D3,D4,D5,D6,D7,D8,D9,D10,D11,D12,D13,D14,D15,D16,D17,D18,D19,D20,D21,D22 | 22 | LED |  | LED_SMD:LED_0805_2012Metric_Pad1.15x1.40mm_HandSolder | ~
J3 | 1 | ZIF Socket Excerciser |  | User_lib_kk08:ZIF_PinSocket_2x12_P2.54mm | ~
R2,R4,R6,R8,R10,R12,R14,R16,R18,R20,R22,R34,R35,R36,R37,R38,R39,R40,R41,R42,R43,R44 | 22 | 2k2 |  | Resistor_SMD:R_0805_2012Metric_Pad1.20x1.40mm_HandSolder | ~
R3,R5,R7,R9,R11,R13,R15,R17,R23,R25,R26 | 11 | 33k |  | Resistor_SMD:R_0805_2012Metric_Pad1.20x1.40mm_HandSolder | ~

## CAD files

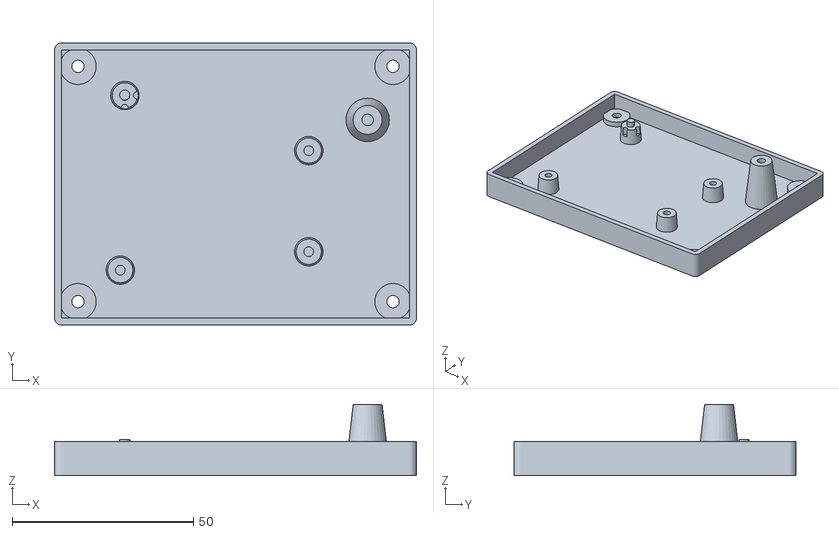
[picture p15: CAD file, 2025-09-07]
case/aft3x_bottom_usbb.stl
100.0 x 78.0 x 19.7

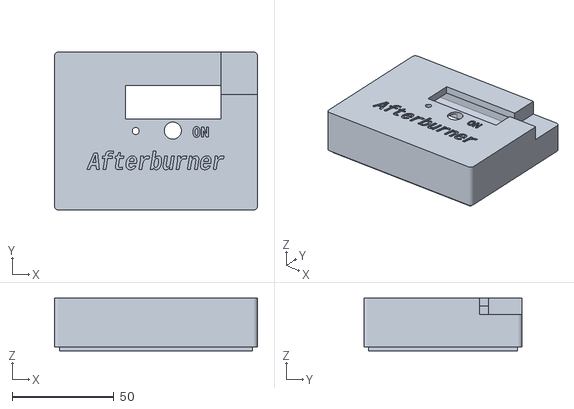
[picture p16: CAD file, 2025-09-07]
case/aft3x_top_usbc.stl
100.0 x 78.0 x 26.0

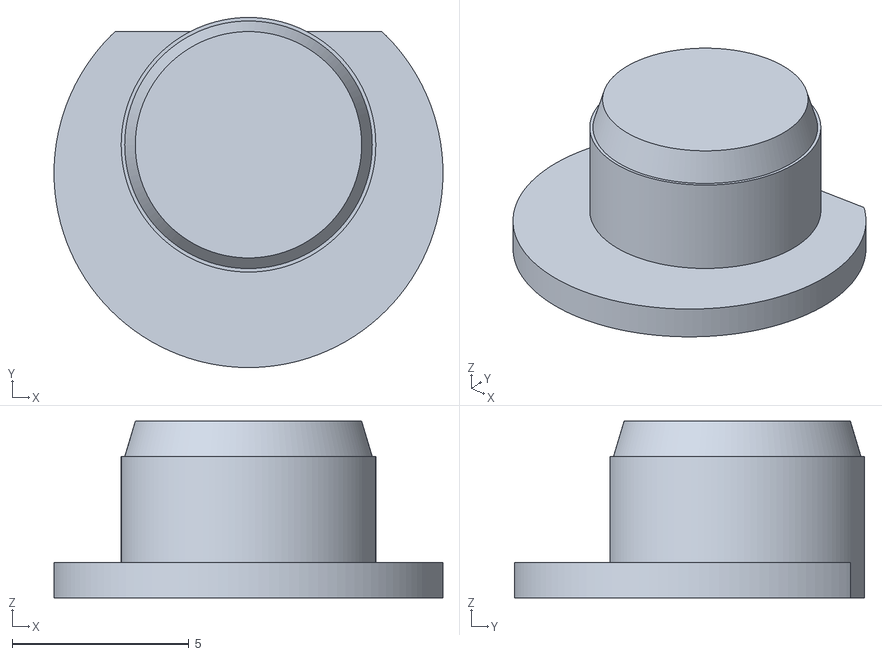
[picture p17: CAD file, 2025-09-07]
case/aft3x_button.stl
11.0 x 9.90 x 5.00

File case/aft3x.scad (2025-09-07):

//############################################################
//         Afterburner 3.X case (ver. 2c)
//############################################################

//Export Top case
enableTop = true;

//Export Bottom case
enableBottom = true;

//Export power switch
enablePowerSwitch = true;

//Disaply Arduino
enableArduino = true;

//VPP via MT3608 module (On) or via discrete componets (Off)
vppModule = true;

//Hole for VPP measurement header
vppMeasurementHole = true;

//Hole for VPP trimmer
vppTrimmerHole = true;

//Depressions for anti-slippery pads on the bottom of the case
enableAntislipperyRings = true;

//Size of the USB hole
powerType = 0; // [0: USB-B for Uno R3, 10: USB-C for Uno-R4] 

//Screw inserts hole shape
screwInsertsType = 0; // [0: FDM - heat inserts, 10: SLA - hot glue inserts]

//Draw text logo
enableTexts = true;

//Distance between the top and the bottom case
caseDistance = 200; //[32:200]

//Overall Case scale - options for print services
caseScale = 1000; // [1000: 100% Exact printer, 996: 99.6% JLCPCB]

//################################################################

module __Customizer_Limit__ () {} 
//Rendering details
details = 120; // [60:Preview-Quick, 360:Export-Slow]

$fn = details;

//Arduino model
include <arduino.scad>


// Case edge radius
edgeR = 2;

// Case Wall thickness
wallT = 2;

// space for the case mounting holes
spaceD = 8;

caseW = 96;
caseD = 58 + (2 * spaceD); //58
caseH = 2;

useUsbC = powerType > 1;
useFdmInserts = screwInsertsType < 1;

module outline(wall = 1) {
  difference() {
    offset( 0) children();
    offset(-wall) children();
  }
}

// Afterburner shield
module afterburner() {
    pcbHeight = 1.6;
    difference() {
        union() {
            translate([0,-9,0]) linear_extrude(pcbHeight) square([54, 85]);
            //place components
            translate([0,0, pcbHeight]) {
                // Ziff socket
                translate([5.3, 15.6, 0]) linear_extrude(12) square([15, 46]);

                // On/Off switch
                translate([23, 34, 0]) {
                    translate([0, 0.7, 0]) linear_extrude(7) square([7, 7]);
                    // On/Off switch lever
                    translate([2, 2.8, 5]) linear_extrude(6) square([3, 3]);
                    // On/Off switch lever - measure pivot
                    //#translate([2, 2.8, 5]) linear_extrude(116) square([3, 3]);
                }

                //LED
                #translate([27, 20.5, 0]) linear_extrude(14) circle(1.5);


                //vpp module
                if (vppModule)
                translate([30.5, 5.5, 3.3]) {
                    // VPP supply - pcb
                    translate([0, 0, 0]) linear_extrude(1.2) square([17.4, 37.2]);
                    // VPP supply - trimmer
                    translate([5, 7.5, 1.2]) linear_extrude(5) square([10, 9.5]);
                    // VPP supply - trimmer knob
                    translate([15, 8.7, 1.2 + 3.3]) rotate([0,90,0]) linear_extrude(2) circle(1.2);

                    // screwdriver shaft
                    translate([18, 8.7, 1.2 + 3.3]) rotate([0,90,0]) linear_extrude(35 + spaceD) circle(1.2);
                }

                //VPP measurement header
                if (vppMeasurementHole) {
                    translate([17, -5, 0]) linear_extrude(12.2) square([5.4, 2.7]);
                }
                
                //VPP trimmer
                translate([6, -0.5, 0]) {
                    linear_extrude(6) square([6.2, 6.2]);
                    if (vppTrimmerHole) {
                        translate([3.1, 3.1, 3.3]) rotate([0,0,0]) linear_extrude(35 + spaceD) circle(1.2);
                    }
                }
            }
        }
        union() {
            translate([9.6, 66.8, -2.1])  linear_extrude(height = 5) circle(1.6);
        }
    }
}

module nutHolder(wallH) {
    boxH = 7.5;
    size = spaceD + 1;
    center = size / 2;
    difference() {
        union() {
            // main box
            linear_extrude(height = boxH) square([size, size]);
            if (useFdmInserts) {
                //support bellow holder
                translate([0, 0, boxH - 0.05]) {
                    linear_extrude(height = wallH - boxH + 0.2) square([size, size]);
                }
            }
        }
        // holes
        {
            if (useFdmInserts) {
                translate([center, center, -0.01]) {
                    //central hole
                    linear_extrude(height = 10.5) circle(2);
                    //hole chamfer
                    cylinder(r1 = 2.6, r2 = 2, h = 1, center = true, $fn=32);
                }
            } else {
                //central hole
                translate([center, center, -0.01])  linear_extrude(height = 10.5) circle(2.5);                
                //retention dip 1
                translate([center - 1, center - (center/2) - 1.2, 1.5])  linear_extrude(height = 3.5) square([2.4, 6.5]);
                //retention dip 2
                translate([center - (center/2) - 1, center - 1.2, 2.0])  linear_extrude(height = 3.4) square([6.5, 2.4]);
            }
        }
    }
    // M3 screw mockup
    %translate([center, center, -12])  linear_extrude(height = 16) circle(1.3);                
    
}

module caseTop() {
    ziffW = 47; //42
    wall2H = 0;
    wallH = 22.0;
    skirtT = 1.8; //skirt thickness
    skirt1 = [0.3, 0.3, 0.9]; //blue
    skirt2 = [0.3, 0.8, 0.9]; //cyan
    
    
    difference() {
        union() {
            // base shape
            translate([0,0,0]) linear_extrude(height = caseH) offset(edgeR) square([caseW, caseD]);
            
            //base wall
            translate([0,0,-wallH]) {
                linear_extrude(wallH) {
                    outline(wallT) offset(edgeR) square([caseW, caseD]);
                }
                
                //wall skirt small and closer to wall
                color (skirt1) translate([0,0, -wall2H - 0.005]) {
                    linear_extrude(2) {
                        outline(wallT) offset(edgeR-0.5) square([caseW-0.5, caseD-0.5]);
                    }
                }
                color (skirt2) translate([0.25, 0.25, -wall2H -2]) {
                    linear_extrude(3.5) {
                        outline(skirtT) offset(edgeR - wallT - 0.1) square([caseW-0.5, caseD-0.5]);
                    }
                }
                
                //wall skirt print supports
                translate([9, 0.5,0.4]) rotate([0,90, 0]) rotate([0,0,120]) linear_extrude(caseW - 17) square([1.9, 5]);
                translate([9, caseD - 2.15,1.4]) rotate([0,90, 0]) rotate([0,0,60]) linear_extrude(caseW - 17) square([1.9, 5]);
                translate([2.15, 9,1.4]) rotate([0,90, 90]) rotate([0,0,60]) linear_extrude(caseD - 17) square([1.9, 5]);
                translate([caseW - 0.5, 9,0.4]) rotate([0,90, 90]) rotate([0,0,120]) linear_extrude(caseD - 17) square([1.9, 5]);
            }
            // case mounting holes with nuts
            translate([0,0, -wallH]) {
                holderSize = spaceD + 1;
                nutHolder(wallH);
                translate([caseW - holderSize, 0, 0]) nutHolder(wallH);
                translate([0, caseD - holderSize, 0]) nutHolder(wallH);
                translate([caseW - holderSize, caseD - holderSize, 0]) nutHolder(wallH);
            }
            
            translate([0, spaceD ,0]) {
                //ziff lever box (+)
                translate([78, 46, -7.3]) linear_extrude(height = 8) square([19, 21]);
                
                //ziff skirt - v2b
                translate([32, 33,-2]) linear_extrude(height = 3.5) square([ziffW + 18, 20.5]);
                
                // VPP trimmer access box (+)
                if (vppModule) {
                    translate([22.5, -1 - spaceD, -7]) linear_extrude(height = 9) square([18, 6 + spaceD]);
                }
                
                // LED hole retention (bottom side)
                //    translate([37.25, 25.8, -2])  linear_extrude(height = 2.3) square([6,6]);
                
            }            
        }
        // case cut-throughs
        {
            translate([0, spaceD ,0]) {
                // USB socket hole
                if (useUsbC) {
                    translate([-3, 35,-wallH + 3.5]) rotate([0,90,0]) linear_extrude(height = 9) offset(2) square([5.5, 11]);
                } else {
                    translate([-3, 34,-wallH - 3.7]) linear_extrude(height = 15.5) square([6, 14]);
                }

                // Power jack hole
                translate([-3, 5.6,-wallH - 3.7]) linear_extrude(height = 15.5) square([6.01, 10]);
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

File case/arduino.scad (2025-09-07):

// Arduino connectors library
//
// Copyright (c) 2013 Kelly Egan
//
// The MIT License (MIT)
//
// Permission is hereby granted, free of charge, to any person obtaining a copy of this software 
// and associated documentation files (the "Software"), to deal in the Software without restriction, 
// including without limitation the rights to use, copy, modify, merge, publish, distribute, sublicense,
// and/or sell copies of the Software, and to permit persons to whom the Software is furnished to do 
// so, subject to the following conditions:
//
// The above copyright notice and this permission notice shall be included in all copies or substantial
// portions of the Software.
//
// THE SOFTWARE IS PROVIDED "AS IS", WITHOUT WARRANTY OF ANY KIND, EXPRESS OR IMPLIED, INCLUDING BUT 
// NOT LIMITED TO THE WARRANTIES OF MERCHANTABILITY, FITNESS FOR A PARTICULAR PURPOSE AND NONINFRINGEMENT. 
// IN NO EVENT SHALL THE AUTHORS OR COPYRIGHT HOLDERS BE LIABLE FOR ANY CLAIM, DAMAGES OR OTHER LIABILITY,
// WHETHER IN AN ACTION OF CONTRACT, TORT OR OTHERWISE, ARISING FROM, OUT OF OR IN CONNECTION WITH THE 
// SOFTWARE OR THE USE OR OTHER DEALINGS IN THE SOFTWARE.
//
// https://github.com/kellyegan/OpenSCAD-Arduino-Mounting-Library

//use <pin_connectors/pins.scad>

//Constructs a roughed out arduino board
//Current only USB, power and headers
module arduino(boardType = UNO, useColors = true, useUsbC = false) {
  //The PCB with holes
  if (useColors) difference() {
        color("SteelBlue") boardShape( boardType, useUsbC = useUsbC );
        translate([0,0,-pcbHeight * 0.5]) holePlacement(boardType = boardType)
          color("SteelBlue") cylinder(r = mountingHoleRadius, h = pcbHeight * 2, $fn=32);
    } else difference() {
        boardShape( boardType, useUsbC = true );
        translate([0,0,-pcbHeight * 0.5]) holePlacement(boardType = boardType)
          cylinder(r = mountingHoleRadius, h = pcbHeight * 2, $fn=32);
    }

  //Add all components to board
  components( boardType = boardType, component = ALL, useColors = useColors, useUsbC = useUsbC );
}


//Setting for enclosure mounting holes (Not Arduino mounting)
NOMOUNTINGHOLES = 0;
INTERIORMOUNTINGHOLES = 1;
EXTERIORMOUNTINGHOLES = 2;


//Offset from board. Negative values are insets
module boardShape( boardType = UNO, offset = 0, height = pcbHeight, useUsbC = true ) {
  dimensions = boardDimensions(boardType);

  xScale = (dimensions[0] + offset * 2) / dimensions[0];
  yScale = (dimensions[1] + offset * 2) / dimensions[1];

  translate([-offset, -offset, 0])
    scale([xScale, yScale, 1.0])
      linear_extrude(height = height) 
        polygon(points = boardShapes[boardType]);
}

//Create a bounding box around the board
//Offset - will increase the size of the box on each side,
//Height - overides the boardHeight and offset in the z direction

BOARD = 0;        //Includes all components and PCB
PCB = 1;          //Just the PCB
COMPONENTS = 2;   //Just the components

module boundingBox(boardType = UNO, offset = 0, height = 0, cornerRadius = 0, include = BOARD) {
  //What parts are included? Entire board, pcb or just components.
  pos = ([boardPosition(boardType), pcbPosition(boardType), componentsPosition(boardType)])[include];
  dim = ([boardDimensions(boardType), pcbDimensions(boardType), componentsDimensions(boardType)])[include];

  //Depending on if height is set position and dimensions will change
  position = [
        pos[0] - offset, 
        pos[1] - offset, 
        (height == 0 ? pos[2] - offset : pos[2] )
        ];

  dimensions = [
        dim[0] + offset * 2, 
        dim[1] + offset * 2, 
        (height == 0 ? dim[2] + offset * 2 : height)
        ];

  translate( position ) {
    if( cornerRadius == 0 ) {
      cube( dimensions );
    } else {
      roundedCube( dimensions, cornerRadius=cornerRadius );
    }
  }
}

//Creates standoffs for different boards
TAPHOLE = 0;
PIN = 1;

module standoffs( 
  boardType = UNO, 
  height = 10, 
  topRadius = mountingHoleRadius + 1, 
  bottomRadius =  mountingHoleRadius + 2, 
  holeRadius = mountingHoleRadius,
  mountType = TAPHOLE
  ) {

  holePlacement(boardType = boardType)
    union() {
      difference() {
        cylinder(r1 = bottomRadius, r2 = topRadius, h = height, $fn=32);
        if( mountType == TAPHOLE ) {
          cylinder(r =  holeRadius, h = height * 4, center = true, $fn=32);
        }
      }
      if( mountType == PIN ) {
        translate([0, 0, height - 1])
        pintack( h=pcbHeight + 3, r = holeRadius, lh=3, lt=1, bh=1, br=topRadius );
      }
    }  
}

//This is used for placing the mounting holes and for making standoffs
//child elements will be centered on that chosen boards mounting hole centers
module holePlacement(boardType = UNO ) {
  for(i = boardHoles[boardType] ) {
    translate(i)
      children(0);
  }
}

//Places components on board
//  compenent - the data set with a particular component (like boardHeaders)
//  extend - the amount to extend the component in the direction of its socket
//  offset - the amount to increase the components other two boundaries

//Component IDs
ALL = -1;
HEADER_F = 0;
HEADER_M = 1;
USB = 2;
POWER = 3;
RJ45 = 4;

module components( boardType = UNO, component = ALL, extension = 0, offset = 0, useColors = false, useUsbC = false ) {
  bt = ( boardType == UNO && useUsbC)  ?  UNO_R4 : boardType;
  //echo (BoardType=bt);
  //echo (useSusbC=useUsbC);
  translate([0, 0, pcbHeight]) {
    for( i = [0:len(components[bt]) - 1] ){
      if( components[bt][i][3] == component || component == ALL) {
          //Calculates position + adjustment for offset and extention  
          position = components[bt][i][0] 
            - (([1,1,1] - components[bt][i][2]) * offset)
            + [  min(components[bt][i][2][0],0), min(components[bt][i][2][1],0), min(components[bt][i][2][2],0) ] 
            * extension;
          //Calculates the full box size including offset and extention
          dimensions = components[bt][i][1] 
            + ((components[bt][i][2] * [1,1,1]) 
              * components[bt][i][2]) * extension
            + ([1,1,1] - components[bt][i][2]) * offset * 2;        
          translate( position ) {
             if (useColors) color( components[bt][i][4] ) cube( dimensions );
             if (!useColors) cube( dimensions );
         }
      }
    }  
  }
}

module roundedCube( dimensions = [10,10,10], cornerRadius = 1, faces=32 ) {
  hull() cornerCylinders( dimensions = dimensions, cornerRadius = cornerRadius, faces=faces ); 
}

module cornerCylinders( dimensions = [10,10,10], cornerRadius = 1, faces=32 ) {
  translate([ cornerRadius, cornerRadius, 0]) {
    cylinder( r = cornerRadius, $fn = faces, h = dimensions[2] );
    translate([dimensions[0] - cornerRadius * 2, 0, 0]) cylinder( r = cornerRadius, $fn = faces, h = dimensions[2] );
    translate([0, dimensions[1] - cornerRadius * 2, 0]) {
      cylinder( r = cornerRadius, $fn = faces, h = dimensions[2] );
      translate([dimensions[0] - cornerRadius * 2, 0, 0]) cylinder( r = cornerRadius, $fn = faces, h = dimensions[2] );
    }
  }
}

//Create a clip that snapps into a clipHole
module clip(clipWidth = 5, clipDepth = 5, clipHeight = 5, lipDepth = 1.5, lipHeight = 3) {
  translate([-clipWidth/2,-(clipDepth-lipDepth),0]) rotate([90, 0, 90])
  linear_extrude(height = clipWidth, convexity = 10)
    polygon(  points=[  [0, 0], 
            [clipDepth - lipDepth, 0],
            [clipDepth - lipDepth, clipHeight - lipHeight],
            [clipDepth - 0.25, clipHeight - lipHeight],
            [clipDepth, clipHeight - lipHeight + 0.25],
            [clipDepth - lipDepth * 0.8, clipHeight],
            [(clipDepth - lipDepth) * 0.3, clipHeight] 
            ], 
        paths=[[0,1,2,3,4,5,6,7]]
      );
}

//Hole for clip
module clipHole(clipWidth = 5, clipDepth = 5, clipHeight = 5, lipDepth = 1.5, lipHeight = 3, holeDepth = 5) {
  offset = 0.1;
  translate([-clipWidth/2,-(clipDepth-lipDepth),0])
  translate([-offset, clipDepth - lipDepth-offset, clipHeight - lipHeight - offset])
    cube( [clipWidth + offset * 2, holeDepth, lipHeight + offset * 2] );
}

module mountingHole(screwHeadRad = woodscrewHeadRad, screwThreadRad = woodscrewThreadRad, screwHeadHeight = woodscrewHeadHeight, holeDepth = 10) {
  union() {
    translate([0, 0, -0.01])
      cylinder( r = screwThreadRad, h = 1.02, $fn = 32 );
    translate([0, 0, 1])
      cylinder( r1 = screwThreadRad, r2 = screwHeadRad, h = screwHeadHeight, $fn = 32 );
    translate([0, 0, screwHeadHeight - 0.01 + 1])
      cylinder( r = screwHeadRad, h = holeDepth - screwHeadHeight + 0.02, $fn = 32 );
  }
}

/******************************** UTILITY FUNCTIONS *******************************/

//Return the length side of a square given its diagonal
function sides( diagonal ) = sqrt(diagonal * diagonal  / 2);
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

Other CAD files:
case/aft3x_bottom_usbc.stl
case/aft3x_top_usbb.stl

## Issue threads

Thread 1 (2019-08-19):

missing BOM material

Garabito, 2019-08-19:
Hi, your proyect is excelente, but is missing the bom Material to replay it, because i dont know the value for resistors, capacitors. Can you tell me this? or can you up the schematic to check it?

Thank you very much

ole00, 2019-08-19:
Hi, thanks. I've added the BOM. See bom.txt file. I hope no component is missing. You can cross check the schematics for the resistor and capacitor values.

Garabito, 2019-08-20:
Thanks a lot

Garabito, 2019-09-15:
It works excellently well, it is a great contribution
Thanks

ole00, 2019-09-17:
I'm glad you found the project useful. Thanks for the report.

Closed 2019-09-17.

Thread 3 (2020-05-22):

ATF16V8B strange behavior

PerroLoco64, 2020-05-22:
Don't know why but the chip just doesnt work as supposed, only simple equations works (for example when only one gate type is used for each output), 3.6V outputs instead of 5V, only the low signals are really 0V, also I have to config WinCupl in g16v8ma mode if not the chip almost does nothing, even if everything in the process of programing this ICs seems to be ok, reading the fuse map seems to be the same that is in the jed file only the last 6 lines of every single one is kinda diferent, example:

JEDEC file:
*L02048 01000000001100000011000000100000
*L02112 00000000111111111111111111111111
*L02144 11111111111111111111111111111111
*L02176 111111111111111111
*C14B5
* 9091

Read from the chip:
L2048 01000000*
N UES 0C 0C 04 00 00 00 00 00*
L2056 0011000000110000001000000000000000000000000000000000000000000000*
L2120 11111111111111111111111111111111111111111111111111111111111111111111111111*
N PES 31 42 38 56 36 31 46 31*
C14B5
*

I follow the instructions to program these, 10V, erase first, also tried the conditioning jed file from ATFblast for the ATF16V8B but in this case afterburner returns an error saying that the fuse map wasn't uploaded. Must say that in the moment I ran out of 4.7K resistor, so I used 10k and also tried 1K to see if there was any diference but it was the same, tried the x64 exe in windows 10, the linux executable in debian running under virtual box, even compiling with WinCupl in a windows 98 VM, all were the same results.

Also after some research I found that it was something kinda common for the Atmel PLDs, only GALs from lattice were working (with universal programmers as the TL866).

Did you have the same issue?

Sorry if my english is bad.
Thanks in advance

ole00, 2020-05-23:
Hi,

> reading the fuse map seems to be the same that is in the jed file only the last 6 lines of every single one is kinda diferent,

That should be OK. The last number in the original JED file is an 'end of transmission' character (0x03) followed by transmission checksum, which afterburner does not calculate. But that should not affect functionality. Some software require transmission checksum to be present in the JDEC file, in such case using value 0000 will do the job (it means ignore transmission checksum).

As far as I can tell, if you are able to read back all fuses from the IC and the contents match then the device is correctly programmed. My understanding is that pull down resistors ensure that the pins don't toggle during programming (either randomly or as a consequence of the previous logic programmed in the device) for devices that are sensitive to such changes. It looks like Atmel devices do not require pull downs (see Bruce Abbott's notes linked on the front page), so using 10k or 1k pull-downs should probably be OK in your case (using Atmel IC).

> also I have to config WinCupl in g16v8ma mode if not the chip almost does nothing

In Wincupl sepcify:
`Device    G16V8;`
in your PLD design file.
And in Menu->Option->Devices specify DIP | Atmel | ATF16V8B. That's how it works for me OK.

I'm not quite sure what you mean by 'the chip almost does nothing'. Can you exercise AND | OR | XOR | NOT combinations on several inputs and feed the output to several output pins? Does that work fo you? I think that's pretty much you can do with these 16V8 devices. You can also synchronise the output via register based on input clock pin 1 (only on that one) like this:
```
Device    G16V8;
/**  Inputs  **/
PIN 1  = clock;                /* Register Clock    */
PIN [2,3,4]  = [D0..2];        /* Data Input        */
/**  Outputs  **/
PIN [14, 15, 16] = [Q0..2];    /* Register Output   */
/** Logic Equations **/
[Q0..2].d   =  [D0..2];        /* note .d is used */
```

> Also after some research I found that it was something kinda common for the Atmel PLDs, only GALs from lattice were working (with universal programmers as the TL866).

I don't know about that (might be true though for certain batches or revisions of the chip). Could you link some sources that suggest that?

Just a silly question: do you test your programmed Atmel chip outside of the afterburner programmer, right? So, do you take it out of afterburner and place it in a bread board, or place it to your testing protoboard? Do you have decoupling capacitors installed on VCC when testing on your test board/pcb? I'm sure you do that, I'm just ensuring there is no misunderstanding what afterburner can do and can not do.

If you have a .PLD script you would like me to try, feel free to post it here and I can test it with ATF and Lattice chip. Just make sure the script is compatible with G16V8 devices.

> Sorry if my english is bad.

Your English is very good !

PerroLoco64, 2020-05-24:
Wow, thanks for the fast answer

> I'm not quite sure what you mean by 'the chip almost does nothing'

When I only write g16v8 in device is when almost all the combinations are wrong, almost all the combinations remains HIGH, when I specify g16v8ma in WinCupl it works a bit better but around the half of the output from the true table stills wrong

> Can you exercise AND | OR | XOR | NOT combinations on several inputs and feed the output to several output pins? Does that work for you?

Yes it can... well actually noticed that not always, my first test was AND OR gates and they worked but now I tested using a not gate and didn't work, the signal wasn't inverted, I mean, a LOW input was a LOW output and a HIGH input was a HIGH output. Until now I haven't tried clock signals or equations with XOR operators

> I don't know about that (might be true though for certain batches or revisions of the chip). Could you link some sources that suggest that?

Here: https://atariage.com/forums/topic/246552-question-about-programming-galplds/
Extrated from there: `These chips were new, however, were purchased from the asian market. Not to mention that this type of PLD is quite old. This leads me to suspect that these are refurbished, or counterfeit. I suppose a small chance there may be of the algorithm not being solid enough to program EVERY IC. But I find that extremely hard to believe.`
I purchased mine where I live, México, through a Latinoamerican page (Mercadolibre with a trusted seller), wouldn't be weird that his products were dispached from china

> Just a silly question: do you test your programmed Atmel chip outside of the afterburner programmer, right? So, do you take it out of afterburner and place it in a bread board, or place it to your testing protoboard? Do you have decoupling capacitors installed on VCC when testing on your test board/pcb? I'm sure you do that, I'm just ensuring there is no misunderstanding what afterburner can do and can not do.

Yes to all of that,

Maybe is a bad compilation from WinCupl, but the 3.6V read is normal? also in the inputs and outputs that are not used the multimeter reads 3.6V too

> If you have a .PLD script you would like me to try, feel free to post it here and I can test it with ATF and Lattice chip. Just make sure the script is compatible with G16V8 devices.
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
PerroLoco64, 2020-05-24:
> Apology for any inconvenience. I'll take a look and hopefully find the solution.

Yeah, don't worry, taking long time is something to expect when things have to be reverse enginered, even more if they are discontinued, there is a lack of info

These PLDs were referenced in a homework documend, the teacher said that wasn't important but I looked into these things because they looked really interesting and are even breadboard friendly, not as CPLDs or FPGAs,

Was wondering if you tested the Atmel ICs before? I mean, the bug its not caused by a update of something like the version of arduino IDE? I will also to try a look but I'm not too good a programing yet

Thanks for taking the time to answer anyway

PerroLoco64, 2020-05-25:
Hey, just for testing I created a JEDEC file using instead ispLEVER from lattice, the program should do the same that the one from WinCupl: aplying NOT to a input from pin 3, and the output are the pins from 12 to 18, no idea why they are different

JEDEC from WinCupl:
```
CUPL(WM)        5.0a  Serial# 60008009
Device          g16v8s  Library DLIB-h-40-9
Created         Sun May 24 00:28:27 2020
Name            TestNOT
Partno          00
Revision        01
Date            23/05/2020
Designer        ADMO
Company         BUAP
Assembly        None
Location
*QP20
*QF2194
*G0
*F0
*L00256 11111011111111111111111111111111
*L00512 11111011111111111111111111111111
*L00768 11111011111111111111111111111111
*L01024 11111011111111111111111111111111
*L01280 11111011111111111111111111111111
*L01536 11111011111111111111111111111111
*L01792 11111011111111111111111111111111
*L02048 01111111001100000011000000100000
*L02112 00000000100000001111111111111111
*L02144 11111111111111111111111111111111
*L02176 111111111111111110
*C2418
* A056
```

JEDEC from ispLEVER
```
 ispLEVER Classic 2.0.00.17.20.15 Lattice Semiconductor Corp.
JEDEC file for: P16V8AS V9.0
Created on: Sun May 24 19:30:55 2020

*
QP20* QF2194* QV0* F0*
 X0*
NOTE DEVICE NAME: GAL16V8Z-12QP*
NOTE Table of pin names and numbers*
NOTE PINS x:6 y:5 z:4 w:3 a:18 b:16 c:17 d:15 e:12 f:14 g:13*
L0256 11110111111111111111111111111111*
L0512 11110111111111111111111111111111*
L0768 11110111111111111111111111111111*
L1024 11110111111111111111111111111111*
L1280 11110111111111111111111111111111*
L1536 11110111111111111111111111111111*
L1792 11110111111111111111111111111111*
L2128 1111111111111111111111111111111111111111111111111111111111111111*
L2192 1*
C236D*
 9467

```

On ispLEVER I selected GAL16V8D as device, once compilated burned it into the ATF16V8B trough afterburner and it kinda worked, 4 were correct and 3 weren't, the output pins that worked were 18, 17, 12, 13.

Here is the project from ispLEVER with .jed file:
[test.zip](https://github.com/ole00/afterburner/files/4674788/test.zip)

Hope this helps you someway

mecparts, 2020-05-25:
I think I'm seeing the same (or a very, very similar) issue. I just built up the programmer today and tried it out with an old Atmel AT16V8BQL I had on hand. At first everything looked like it was working. The programmer ID'd the chip, could read from it, erased it, and could write to it. Great! Great that is until I actually tried to use the chip. There doesn't appear to be any output happening. Every I/O pin reads about 3.8V volts. I tried with a known working Jedec file from an old project, and with a simple 7 segment decoder I threw together tonight. Neither does a thing when programmed into the chip.

mecparts, 2020-05-25:
From the "may or may not be useful, but here's a data point" department: I programmed a trivial file consisting of equations like "outX = inA;" and "outY = !inA;". That worked - but in inverse. In other words, "outX = inA;" behaved like "outX = !inA;" and "outY = !inA;" behaved like "outY = inA;".

mecparts, 2020-05-25:
Aha! I think I found it. In afterburner.ino, the galinfo struct used cfgV8AB for the ATF16V8B. In the code, in readOrVerifyGal and writeGal, the code used cfgV8 when it was handling the ATF16V8B. I changed all 3 occurrences to cfgV8AB, uploaded the sketch and programmed a chip. Which worked like a charm. Whew! I've sent a pull request with the changes (it's all of 3 lines) for your perusal.

ole00, 2020-05-25:
> Aha! I think I found it. .. I changed all 3 occurrences to cfgV8AB, ...

Excellent and well spotted! I've applied your fix locally and it indeed fixes the issue. Verified on the ATF16V8B device using PerroLoco64's test PLD script.

>  I've sent a pull request with the changes (it's all of 3 lines) for your perusal.

That's great, many thanks for that.

ole00, 2020-05-25:
I've merged the fix. Thank you mecparts for the fix and PerroLoco64 for reporting the issue.
I' closing this issue, hopefully as resolved.

Closed 2020-05-25.

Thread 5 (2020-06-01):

GAL16V8D Reset Afterburner

MD95, 2020-06-01:
After i've programmed my GAL with program which i send below.I cant reprogram, erase, identify ic anymore.Just keep resetting arduino.I've programmed same ic before with simle and, or gates and it worked well without any problem.So i change the arduino, programming voltage but can not solve the problem.Is problem just ic or programmer?

Device g16v8;
PIN 2 = R;
PIN 3 = S;
PIN 19 = Q;
PIN 18 = QN;
Q = !(R # QN);
QN = !(S # Q);

ole00, 2020-06-01:
Hi,
1) which brand and GAL IC do you use?
2) what VPP (programming voltage) do you use?
Also, your script is interesting: Q is a product of QN and QN is a product of Q. I'm not an expert in PLDs and gate design, to me it looks like a chicken-and-egg conundrum.  But maybe it is not and it is fairly normal expression.

mecparts, 2020-06-01:
After adding in the remaining header elements that CUPL complained about, I still couldn't get it to compile. "pin/node 19 invalid input:  Q" was the error I got.

ole00, 2020-06-01:
@mecparts : thank you for checking, the script looked suspicious to me.

@MD95 : could you also list/attach the full PLD script, the JED file and send the name of the CUPL tool/compiler you are using?

MD95, 2020-06-01:
1. I use Lattice GAL16V8D
2. I tried to implement simple SR latch.Also i'm not sure about my equation because i am beginner and just experimenting.I've tried to program 10v, 11v and 12v not go beyond that.
3.Atmel WinCUPL Version 5.30.4 on Windows 10 64bit

I forget to say i could compile it as g16v8ms.May be is it problem and i fried the IC.

*******PLD File******

Name SRLATCH;
partNo 00;
Date 01/06/2020;
Revision 01;
Designer MD;
Company MD;
Assembly None;
Location None;
Device g16v8ms;

PIN 2 = R;
PIN 3 = S;
PIN 19 = Q;
PIN 18 = QN;
Q = !(R # QN);
QN = !(S # Q);

******JED File*******

CUPL(WM)        5.0a  Serial# 60008009
Device          g16v8ms  Library DLIB-h-40-11
Created         Mon Jun 01 19:17:49 2020
Name            SRLATCH
Partno          00
Revision        01
Date            16/06/2016
Designer        Esteban
Company         estebon
Assembly        None
Location        None
*QP20
*QF2194
*G0
*F0
*L00000 11111111111111111111111111111111
*L00032 01111111111111111111111111111111
*L00064 11111101111111111111111111111111
*L00256 11111111111111111111111111111111
*L00288 11110111111111111111111111111111
*L00320 11011111111111111111111111111111
*L02048 00000000001100000011000000000000
*L02112 00000000111111111111111111111111
*L02144 11111111111111111111111111111111
*L02176 111111111111111101
*C20A4
* 9CB0

mecparts, 2020-06-01:
I thought it was a NOR gate RS flip flop. I'd have never thought of doing it that way (though most of my PLD experience was long ago, far away, and pretty limited).

After changing the device to g16v8ms I was able to get CUPL to compile the file.

The oldest GAL in my parts box is a ATF16V8B from 2003 (I sort of skipped right from PALs to the ATF parts) so the best I could do to check was to write the .JED file out to one of those.

No problem writing, or reading back.

Was able to erase the chip, and read back that it was erased.

Then programmed another .JED file, verified it, and erased the chip again.

I notice that you're using the Atmel WinCUPL. If I recall correctly, that's limited to working on Atmel parts. Does a Lattice GAL16V8 have the same fuse map as an Atmel ATF16V8? If not, that could be your problem (though that's purely a guess on my part). Look in Options -> Devices to see if your version of WinCUPL lists any manufacturers other than Atmel.

ole00, 2020-06-02:
>  Does a Lattice GAL16V8 have the same fuse map as an Atmel ATF16V8?

Yes it does. There might be a confusion that the ATF16V8 can act as 3 different devices, depending on which pins and functions are used. See the datasheet, chapter 10.: 3 modes of operation - Registerd, Complex and Simple. For example in Registered mode pin 11 acts as output enable (OE#), therefore if it is not tied to GND you'll get no output on other output pins. So, this might confuse/trip some people thinking their script/device does not work properly. It's worth reading the ATF16V8B datasheet.

@MD95 thanks for the script, I'll try it soon - I have Lattice GAL16V8 IC available, from the top of my head they require 12V VPP.

MD95, 2020-06-05:
Hello again

I changed my part supplier for my GAL's and there is no problem anymore.I think old ic may be refurbished.So i can easily write and read back again.Thank all of you for support.

ole00, 2020-06-06:
OK, no worries. Thanks for the info. I'm glad it works for you now.

Closed 2020-06-05.

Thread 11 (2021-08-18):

ATF22LV10C works, kinda

NollKollTroll, 2021-08-18:
I built the programmer and managed to program the ATF22LV10C by selecting ATF22V10C and using -v to override detection.
12V programming voltage needed, 10V did not verify correctly.

ole00, 2021-08-18:
Thanks for the info. How do you power your arduino? Via USB cable only, or did you use external power supply? BTW. -v should just enable the verbose mode. Perhaps you meant -t parameter ?

NollKollTroll, 2021-08-18:
USB-power only I'm afraid. And yes, -t is the correct parameter. I'll try external power and let you know.

ole00, 2021-08-18:
OK. interesting. USB power usually drops the voltage from 5V to ~4.7 depending on the cable quality and its length - in such case I would have expected it to work by using 10V VPP . OTOH if the external power delivers 5V I would have expected the VPP to be set a bit higher (like your - to 12V) in order to make it work.

So, does you chip identify if you use
./afterburner i -t ATF22V10C
?

NollKollTroll, 2021-08-20:
Running VPP at 12V and USB power:
afterburner -t ATF22V10C -d /dev/ttyACM0 i
PES info: Atmel  try VPP=10..14 in 1V steps

Dale-Lien, 2022-01-22:
I have tested my ATF22V10C and it can write data using 10V, and erase it.

But there was one chip that couldn't be wiped clean on 10V, so I set it to 11V to erase, no problem. But more than 12V will burn the ATF22V10C.

But using the i parameter to read the information, all ATF22V10C return unknown chip.

My ATF22V10C are all from China.

rreilink, 2022-03-26:
I can confirm this. The issue is that the signature is different. See PR https://github.com/ole00/afterburner/pull/15 for a fix.

ole00, 2022-03-26:
Thanks for the fix **rreilink**. It is now merged.

rreilink, 2022-03-27:
Reading the info bytes still failed (issue https://github.com/ole00/afterburner/issues/16), fixed by PR https://github.com/ole00/afterburner/pull/17

rreilink, 2022-03-27:
> Thanks for the fix **rreilink**. It is now merged.

Thanks for the great application, I was contemplating porting ATFblast myself so you saved me tons of effort :-)

Dale-Lien, 2022-03-28:
I read my ATF22V10C and it shows Unknown GAL,
But I can use "-t ATF22V10C" to read/write it,
So I use the r command to read the PES,
It says "N PES 33 43 30 31 56 32 32 46 31 FF*"
I looked at the code, PES[3] is 1, so it should show ATF22V10,
But it's not.

ole00, 2022-03-28:
> I read my ATF22V10C and it shows Unknown GAL,

Could you please write the exact command and parameters you use?
For example this is what I get if I use:

<pre>
./afterburner -d /dev/ttyUSB1 i -t ATF22V10C

testing gal 6
PES raw bytes:
33 43 30 31 56 32 32 46 31 FF
PES info: Atmel ATF22V10C  VPP=10.0 Timing: prog=10 erase=25

</pre>

If I use read command I get this:

<pre>
 ./afterburner -d /dev/ttyUSB1 r -t ATF22V10C
testing gal 6
PES raw bytes:
33 43 30 31 56 32 32 46 31 FF
JEDEC file for ATF22V10C
*QP24*QF5892*QV0*F0*G0*X0*
L0000 11111111111111111111111111111111111111111111*
L0044 11111111111111111111111111111111111111111111*
L0088 11111111111111111111111111111111111111111111*
...
...
L5764 11111111111111111111111111111111111111111111*
L5808 11111111111111111111*
N UES FF FF FF FF FF FF FF FF*
L5828 1111111111111111111111111111111111111111111111111111111111111111*
N PES 33 43 30 31 56 32 32 46 31 FF*
CDD2F
*
</pre>

ole00, 2022-03-28:
> But using the i parameter to read the information, all ATF22V10C return unknown chip.

Please not the 'i' command does not do autodetection. Afterburner can not detect the GAL chip that you connected to Arduino. So, you have to always set GAL type by passing the '-t' parameter. The 'i' command is a check (for you) that afterburner is able to communicate with the chip and that the GAL type you selected is correct.

rreilink, 2022-03-28:
@Dale-Lien check issue https://github.com/ole00/afterburner/issues/16 , I am experiencing the same. `i` does not work even with `-t ATF22V10C`. It seems you have the same issue. Shall we continue the discussion at https://github.com/ole00/afterburner/issues/16? I have implemented a fix for it but after some comments of @ole00 I noticed my approach is not the best way to fix it.

```
% ./afterburner -t ATF22V10C i -d /dev/tty.usbserial-14P52674 -v
Afterburner v.0.3
opening serial: /dev/tty.usbserial-14P52674
read: 5 ''
opening serial: /dev/tty.usbserial-14P52674
read: 5 ''
opening serial: /dev/tty.usbserial-14P52674
sending 'g' command...
read: 5 ''
sending 'p' command...
read: 67 'PES info: Atmel ATF22V10C  VPP=10.0 Timing: prog=10 erase=25'
PES info: Atmel ATF22V10C  VPP=10.0 Timing: prog=10 erase=25
result=0

```

Dale-Lien, 2022-03-28:
> > I read my ATF22V10C and it shows Unknown GAL,
>
> Could you please write the exact command and parameters you use? Then also write the log printed on the console. For example this is what I get if I use:

On  an hour ago, I use "afterburner_w64 -d COM4 i -t ATF22V10C" to read information,
and it show(not add `#define DEBUG_PES`)

`PES info: Unknown GAL, try VPP=10..14 in 1V steps`

but on now, I add DEBUG_PES & test again, it show:

```
 testing gal 6
 PES raw bytes:
 33 43 30 31 56 32 32 46 31 FF
 PES info: Atmel ATF22V10C  VPP=10.0 Timing: prog=10 erase=25

```
Now regardless of whether `DEBUG_PES` is added or not, it always show Right type.
I don't know why, maybe I can try again tomorrow

Dale-Lien, 2022-03-28:
> Please not the 'i' command does not do autodetection. Afterburner can not detect the GAL chip that you connected to Arduino. So, you have to always set GAL type by passing the '-t' parameter. The 'i' command is a check (for you) that afterburner is able to communicate with the GAL chip and that the GAL type you selected is correct and the programming voltage is OK.

Yes, I always use i with "-t ATF22V10C" to read my GAL

ole00, 2022-03-28:
Ok. I can see 2 issues here.
**Dale-Lien**: I think your programming voltage is somehow unstable. That would explain why it sometimes work and sometimes it does not work. Try to increase or decrease the programming voltage  a tiny bit (let say 0.1V or 0.2V).

**rreilink** : I think what you wrote is critical: " the Arduino resets when the serial port is closed and re-opened". In that case the gal type is lost. My Arduino does not reset when the serial port is closed.It looks like you use Mac OS, maybe it is something OS related or the way how the serial port is opened (maybe some extra flag is needed for BSD compared to Linux when setting the serial port configuration).

ole00, 2022-03-28:
**rrelink**: I think here is the clue: https://arduino.stackexchange.com/questions/439/why-does-starting-the-serial-monitor-restart-the-sketch
.. from the answer...: "Setting the flow control to none will allow you to connect/disconnect from the serial without resetting your board."

Dale-Lien, 2022-03-29:
> **Dale-Lien**: I think your programming voltage is somehow unstable. That would explain why it sometimes works and sometimes it does not work. Try to increase or decrease the programming voltage a tiny bit (let say 0.1V or 0.2V).

I tried changing the VPP from 10.0V to 11.0V by 0.2V each step and it still shows as Unknown GAL.

I found that when I plug the Afterburner into the USB for the first time,
It always read Unknown GAL.
```
testing gal 4
PES raw bytes:
FF FF 0F 00 00 00 00 00 00 00
PES info: 3.3V Unknown GAL,  try VPP=10..14 in 1V steps

```
But when I re-upload the Arduino code, it can show the correct GAL type whether I have pressed reset or not.
```
testing gal 6
PES raw bytes:
33 43 30 31 56 32 32 46 31 FF
PES info: Atmel ATF22V10C  VPP=10.0 Timing: prog=10 erase=25
```

In the last post, I wanted to show PES raw bytes, so I have modified the sketch,
then it show correct type.

ole00, 2022-03-29:
The first output shows "testing gal 4" the second one shows "testing gal 6". So it looks like it might be the same error **rrelink** identified - the Arduino resets in between reads. Yesterday I tried my 2 Arduinos, none of them resets in between reads. Both are clones, not a genuine one. I ordered a genuine Arduino Uno Rev 3 yesterday, I'm curious to see whether the I could replicate the issue on the genuine one and whether it is caused by the hardware, or software.

Here are my clones - very cheap from ebay. Served me well several years.
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

Dale-Lien, 2022-03-30:
My Arduino is clone too, Same as the picture on the right.
Please see issue #18, I continuously test reading data,
if it is a reset problem, why is the GAL type wrong the first time,
right the second time, and wrong the third time?
So I think it may be caused by other problems.

ole00, 2022-03-30:
> why is the GAL type wrong the first time,
> right the second time, and wrong the third time?

I can only speculate, possible reasons or combinations. The issue seems to be intermittent (sometimes it works, sometimes not) in your case, therefore:
*  power might not be sufficient, the board browns-out and resets. Try to use shorter and thicker usb cable, or power Arduino via dedicate 9-12V power supply.
* soldering issue - sometimes unburned flux can create capacitance on the joint and causing problems. Fix: touch the solder joints with hot iron to re-melt them. If you hear sizzling noise - that might be it.
* some software issue
* the GAL IC might be malfunctioning or is damaged and possibly draws to much current causing the board to reset.

Anyway, I've made a modification into the .ino sketch that should remember the gal type between resets. I tested that feature by resetting the board during data commands (to simulate your conditions) and it seems to work better now. Please pull the git repository, upload the sketch and retry.  Let us know whether it helped or not.

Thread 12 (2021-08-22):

Programming voltage generator problem

PhilByte, 2021-08-22:
Built a PCB to the schematic but couldn't get the programming voltage to work.
Thought it may be the MT3608 module (modified as instructed) having some issues as other users on the web have claimed. Modified the module to only output 9 to 16V when enabled which worked very occasionally.
Thought some more and realised that the Arduino was often resetting when the 5V supply was switched on and the USB link to PC was interrupted (Beep off/Beep on sounds)
(Arduino is an old type with plug-in mega328)
I think firstly that the USB feed cannot cope with the MT3608 switch-on surge so I added an external 9V PSU. This only helped a little.
I suspect also that the Arduinos's 5V regulator cannot handle the switch-on surge current to the MT3608 module.
I have now added a 7805 regulator from Vin arduino pin to feed the 5V input to this board. (Arduino 5V connection removed) so now the MT3608 supply and the Vcc to the PLDs is independent (except for a diode on the aduino) of the aduino pwer supply using the 9V PSU. The arduino may also use this PSU but can use the USB if necessary. It does mean that the external 9V PSU must be present to use the system. Seems to work OK!
Next version of my PCB will incorporate a 78l05*  to power the PLDs Vcc  and a 7805 with Schottkey diode to give 5.3V to the MT3608 (Should give 5V out when not enabled - compensates for the series diode drop.)
* May need to be a bit beefier, these PLDs can take nearly 100mA when active.
I can now try to program a PLD.

PhilByte, 2021-09-02:
I was trying an ATF16V8B (of dubious origin) but the power problem arose before it was plugged in - just trying to set the voltage initially.
I have not yet tried using a different Arduino.
I have a TL866ii programmer which normally programs these devices but this one was not co-operating so I wanted to try other set-ups and Vpp settings.
Sorry for the delay - I've been getting my 6502 system up and running. (Hard to find assembler issue)
Phil

ole00, 2021-09-02:
>  the power problem arose before it was plugged in - just trying to set the voltage initially

That's weird. I would not have expect that. I've experienced the buzzing noise when ATF device was plugged in. I made a note in the README troubleshooting section.
<pre>
.. Arduino made a tiny short buzzing noise and then reset itself. What went wrong ?
... most likely the VPP is set too high and the IC does not like that, it pulls the VPP pin down several times
causing the Arduino to reset on brown out. Solution: reduce the VPP voltage by turning the pot clockwise
 on the MT3608 module.
This happens for example on ATF devices when VPP is set to 12V. ATF should use VPP set to 10V when
programmed by Afterburner.
</pre>
This does not seem to be your case (your ATF is not plugged in), but It looks similar, so maybe it is some sort of short - a flux residue left on the PCB perhaps.

> .. TL866ii programmer which normally programs these devices ..

I did not know the programmer supports ATF gals. Good to know. Thanks for pointing that out.

PhilByte, 2021-09-02:
TL866ii claims to support ATF16V8 to ATF22V10.  It certainly did at least 1 22V10 for me.
Still short on the ATV750 though.
Phil

MarkusPlehn, 2022-07-01:
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

how about a small coil between +5Vin MT3608 and Arduino +5V? to limit the initial current?

artgodwin, 2023-01-21:
I also found the problem with turning on the 5V supply to the MT3608. I tested before the board was fully built up and found switching on the 5V switch crashed the arduino program so it stopped responding (I was testing using the arduino monitor screen rather than the afterburner executable). I added 200uF capacitance to the supply BEFORE the switch (so it could more easily withstand the switchon surge) and it mostly worked. Adding the pulldown on the enable pin also seemed to improve things. I don't think its perfect yet but it does mostly work.

Switching off the 5V supply doesn't completely power down the device as some lines are set to a +5 rest state by Vccoff(). So I have mostly inserted the GAL with the 5V supply on, thinking it wouldn't be much worse. I have damaged some GALS but not as a result of this procedure - see my other notes in the bug re GAL20V8A.

I am using a genuine Arduino Uno powered only by USB, though the USB hub is not the greatest quality and may sometimes provide inadequate current.

ole00, 2023-01-22:
Thanks for the reports. I've isolated the MT3608 and connected is solely (without afterburner) to the Arduino's 5V rail via switch. When I turn on the switch the voltage on the 5V rail dips the same way you reported in your other thread. So the main (or only) contributor to the drip is the MT3608 module. I'll take a look whether it could find an alternative solution.

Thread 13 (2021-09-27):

Problem with ATF16V8CZ-15PU and a story

lucadelpollo, 2021-09-27:
Hi guys,

so I just built the Afterburner ( let' see if I can add a pic here ) , this is my version using Arduino Pro Micro and SW I lightly modified to make it work with Platform Io

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

As you can see I went for the route of "an external power supply", no rocket science, plain simple 78S05 with some caps.

I had a bit of a nightmare story with the MT3608 module, I found out for me the simplest way was to lift up pin 4 and solder a small wire , but I also found the set ( 5 ) I bough on Amazon was defective, it was missing a connection between a resistor and the feedback loop making the regulation non-existent ( luckily it was stuck at 4.84V ), you can see a second wire in my pic ( that's the missing connection ).

Anyway so far been trying with 2 chips with the VPP set at precisely 10.0V , an ATF22V10C and an ATF16V8CZ

With the 16V8C I get the following thing ..

afterburner -v -t ATF16V8B i -d COM11

Afterburner v.0.3
opening serial: \\.\COM11
read: 5 ''
opening serial: \\.\COM11
read: 5 ''
opening serial: \\.\COM11
sending 'p' command...
read: 62 'PES info: 3.3V Unknown GAL,  try VPP=10..14 in 1V steps'
PES info: 3.3V Unknown GAL,  try VPP=10..14 in 1V steps
result=0

( what is that read '62' is the ID code ?? )

If I try with the 22V10 instead things seems to go OK ( I yet have to try the chip itself ) however just to let you know this is what I see ..

afterburner -t ATF22V10C i -d COM11
PES info: Atmel ATF22V10C  VPP=10.0 Timing: prog=10 erase=25

JEDEC file for ATF22V10C
*QP24*QF5892*QV0*F0*G0*X0*
L2156 11111111111111111111111111111111111111111111*
L2200 11110111111111111101111111111111111111111111*
L2904 11111111111111111111111111111111111111111111*
L2948 11110111111111111110111011111111111111111111*
L2992 11110111111111111101110111111111111111111111*
L3652 11111111111111111111111111111111111111111111*
L3696 11110111111111111101110111011111111111111111*
L3740 11110111111111111111111011101111111111111111*
L3784 11110111111111111110111111101111111111111111*
L4312 11111111111111111111111111111111111111111111*
L4356 11110111111111111101110111011101111111111111*
L4400 11110111111111111110111111111110111111111111*
L4444 11110111111111111111111111101110111111111111*
L4488 11110111111111111111111011111110111111111111*
L4884 11111111111111111111111111111111111111111111*
L4928 11111111101111111111111111111111111111111111*
L4972 11111111111111111111111111111101111111111111*
L5016 11111111111111111111111111101111111111111111*
L5808 00000000000000001100*
N UES 30 30 20 00 00 00 00 00*
L5828 0011000000110000001000000000000000000000000000000000000000000000*
N PES 33 43 30 31 56 32 32 46 31 FF*
C5EC5
*

And this is the original .JED file I used as output by WinCPUL .. as you can see despite "verify" and all is O.K. the file looks a bit different ( look at those lines of '000000' ) is that normal ?

CUPL(WM)        5.0a  Serial# 60008009
Device          g22v10  Library DLIB-h-40-1
Created         Sun Sep 26 15:57:05 2021
Name            VT100
Partno          00
Revision        01
Date            31/07/2021
Designer        Engineer
Company        XXXXXXXXXXXXXXX
Assembly        None
Location        Wales
*QP24
*QF5892
*G0
*F0
*L02144 00000000000011111111111111111111
*L02176 11111111111111111111111111110111
*L02208 11111111110111111111111111111111
*L02240 11110000000000000000000000000000
*L02880 00000000000000000000000011111111
*L02912 11111111111111111111111111111111
*L02944 11111111011111111111111011101111
*L02976 11111111111111111111011111111111
*L03008 11011101111111111111111111110000
*L03648 00001111111111111111111111111111
*L03680 11111111111111111111011111111111
*L03712 11011101110111111111111111111111
*L03744 01111111111111111110111011111111
*L03776 11111111111101111111111111101111
*L03808 11101111111111111111000000000000
*L04288 00000000000000000000000011111111
*L04320 11111111111111111111111111111111
*L04352 11111111011111111111110111011101
*L04384 11011111111111111111011111111111
*L04416 11101111111111101111111111111111
*L04448 01111111111111111111111011101111
*L04480 11111111111101111111111111111110
*L04512 11111110111111111111000000000000
*L04864 00000000000000000000111111111111
*L04896 11111111111111111111111111111111
*L04928 11111111101111111111111111111111
*L04960 11111111111111111111111111111111
*L04992 11111111110111111111111111111111
*L05024 11111111111111111110111111111111
*L05056 11110000000000000000000000000000
*L05824 11000011000000110000001000000000
*C5EC5
* 46E7

Thanks a lot for any help, btw I know very little about how to use GitHub ( I am used to SVN ).

Any help appreciated, cheers.

ole00, 2021-09-28:
Hi, thanks for the report. It looks like a neat build. To answer your questions:

* the number after the "read:" is the total characters read from the serial line. For example "read: 5" means it read 5 bytes from the arduino device. It's really just a debugging info in case the serial connection is not working properly.

* The JDEC format in both files seems to be correct even though it is not "styled" identically. Important part is the checksum C5EC5 at the end of the file, which matches on both of the bitstreams - that means the contents is most likely the same (16bit CRC is not a 100% guarantee the contents is the same though). You can also check bit by bit (see those 0 and 1's in the jdec files) and verify them manually if you want to be sure.

* Related to why ATF22V10C works and ATF16V8CZ does not - I don't know. AFAIK nobody reported / investigated  the C version of ATF16V8. If you look into the afterburner's arduino code the C version of **ATF22V10** reverses the order of bits of the address (see sendAddress() function) compared to B version. It may be something similar for the C version of ATF16V8. Try ATF16V8 B version of the IC to verify your Afterburner device/build is correct (for functionality of 16V8 devices), then try to reverse the bit order of the address sent to the the C version of ATF16V8 (if you have time and would like to experiment).

lond131421, 2024-06-03:
ATF16V8CZ still cannot support it, I found that the program written in does not match the source program.

lond131421, 2024-06-03:
When ATF16V8CZ uses afterburner to read the generated Jed file and then brushes it back, there will be a problem of different programs before and after. If only the ATF16V8CZ program is flashed, it is normal; I used a professional programmer to read the source program Jed file of ATF16V8CZ, and it is normal to write it in afterburner.

lond131421, 2024-06-03:
I am Chinese, please understand if my English is not good.

ole00, 2024-06-03:
@lond131421 : can you give an example of the JED file, that does not work for you?

lond131421, 2024-06-03:
hello：
&nbsp;I used afterburner to perform read, erase, and write functions on ATF16V8CZ;&nbsp;The file named test.jed is read and retrieved. Please refer to the data read before erasing and the data written to test.jed after erasing, which is completely incorrect.&nbsp;When checking the chip information, the Atmel ATF16V8CZ model did not appear.&nbsp;Finally, I erased the chip and rewrote it to ATFB11. jed (the original file of the chip), and after reading it, it returned to normal.&nbsp; &nbsp; &nbsp;&nbsp;
您好：
我通过afterburner进行了对ATF16V8CZ的读取、擦除、写入功能；读取出文件命名为test.jed，请看在擦除前读取的数据和擦除后写入test.jed的数据，完全不正确。&nbsp; 还有在查询芯片信息的时候，并没有出现 Atmel ATF16V8CZ这个型号。最后我擦除芯片重新写入ATFB11.jed（该芯片的原始文件），读取后正常。

------------------&nbsp;原始邮件&nbsp;------------------

发件人:                                                                                                                        "ole00/afterburner"                                                                                    ***@***.***&gt;;
发送时间:&nbsp;2024年6月4日(星期二) 凌晨1:46
***@***.***&gt;;
***@***.******@***.***&gt;;
主题:&nbsp;Re: [ole00/afterburner] Problem with ATF16V8CZ-15PU and a story (#13)

@lond131421 : can you give an example of the JED file, that does not work for you?

—
Reply to this email directly, view it on GitHub, or unsubscribe.
You are receiving this because you were mentioned.Message ID: ***@***.***&gt;

lond131421, 2024-06-04:
我发现一个问题
读取ATF16V8CZ&nbsp; 程序应该是&nbsp; &nbsp;./afterburner r -t ATF16V8B &gt; my_gal.jed  !!!

发件人:                                                                                                                        "ole00/afterburner"                                                                                    ***@***.***&gt;;
发送时间:&nbsp;2024年6月4日(星期二) 凌晨1:46
***@***.***&gt;;
***@***.******@***.***&gt;;
主题:&nbsp;Re: [ole00/afterburner] Problem with ATF16V8CZ-15PU and a story (#13)

@lond131421 : can you give an example of the JED file, that does not work for you?

—
Reply to this email directly, view it on GitHub, or unsubscribe.
You are receiving this because you were mentioned.Message ID: ***@***.***&gt;

ole00, 2024-06-04:
> Please refer to the data read before erasing and the data written to test.jed after erasing, which is completely incorrect.&nbsp

1) Please list the contents of the test.jed here, so I can check it with my Afterburner.

>  the Atmel ATF16V8CZ model did not appear.

2) Which parameters did you use when running afterburner to show the model?

> Finally, I erased the chip and rewrote it to ATFB11. jed (the original file of the chip), and after reading it, it returned to normal

3) How did you do erasing writing and reading ? Did you use Afterburner to do that?

4) Do you have the latest version of afterburner installed (both on Arduino and on PC)? If not, which version do you use?

5) Which board/PCB version of Afterburner do you have?

Please answer all questions 1 to 5, so that I can help you to resolve the issue.

lond131421, 2024-06-04:
我发现一个问题
读取ATF16V8CZ&nbsp; 程序应该是&nbsp; &nbsp;./afterburner r -t ATF16V8B &gt; my_gal.jed  !!!
错误写成&nbsp;&nbsp;&nbsp;./afterburner i -t ATF16V8B &gt; my_gal.jed
这是我的错误，抱歉，再次测试，读取是正确的！

I found a problem

Reading the ATF16V8CZ program should be/&nbsp;afterburner r -t ATF16V8B &gt; my_gal.jed !!!

Wrote incorrectly as/&nbsp;afterburner i -t ATF16V8B &gt; my_gal.jed

This is my mistake, sorry, test again, the reading is correct!

发件人:                                                                                                                        "ole00/afterburner"                                                                                    ***@***.***&gt;;
发送时间:&nbsp;2024年6月4日(星期二) 凌晨1:46
***@***.***&gt;;
***@***.******@***.***&gt;;
主题:&nbsp;Re: [ole00/afterburner] Problem with ATF16V8CZ-15PU and a story (#13)

@lond131421 : can you give an example of the JED file, that does not work for you?

—
Reply to this email directly, view it on GitHub, or unsubscribe.
You are receiving this because you were mentioned.Message ID: ***@***.***&gt;

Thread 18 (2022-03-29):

Read ATF22V10C PES info, show "Unknown GAL"

Dale-Lien, 2022-03-29:
Hi ole00,

I am testing an unknown GAL problem, this is my read information, After inserting the afterburner into the USB, read ATF22V10C directly and continuously, All are the same chip.
Maybe the i command reset the Type parameter?
ps. The chip can read/write correctly on "-t ATF22V10C"

```
c:\>afterburner_w64 -d COM4 i -t ATF22V10C
testing gal 4
PES raw bytes:
FF FF 0F 00 00 00 00 00 00 00
PES info: 3.3V Unknown GAL,  try VPP=10..14 in 1V steps

c:\>afterburner_w64 -d COM4 r -t ATF22V10C
testing gal 6
PES raw bytes:
33 43 30 31 56 32 32 46 31 FF
JEDEC file for ATF22V10C
*QP24*QF5892*QV0*F0*G0*X0*
L0000 11111111111111111111111111111111111111111111*
L0044 11111111111111111111111111111111111111111111*
L0088 11111111111111111111111111111111111111111111*
...
...
L5764 11111111111111111111111111111111111111111111*
L5808 11111111111111111111*
N UES FF FF FF FF FF FF FF FF*
L5828 1111111111111111111111111111111111111111111111111111111111111111*
N PES 33 43 30 31 56 32 32 46 31 FF*
CDD2F
*

c:\>afterburner_w64 -d COM4 i -t ATF22V10C
testing gal 4
PES raw bytes:
FF FF 0F 00 00 00 00 00 00 00
PES info: 3.3V Unknown GAL,  try VPP=10..14 in 1V steps
```

ole00, 2022-03-30:
I've made a modification into the .ino sketch that should remember the gal type between resets. I tested that feature by resetting the board during data commands (to simulate your conditions) and it seems to work better now. Please pull the git repository, upload the sketch and retry your tests.  Let us know whether it helped or not.

rreilink, 2022-03-30:
Is there a reason why the individual functions of the pc application open and close the serial port? If the serial port is opened only once and closed at the very end of the program, that would fix it in a nice way I suppose. I can give it a try tomorrow.

Dale-Lien, 2022-03-31:
> I've made a modification into the .ino sketch that should remember the gal type between resets. I tested that feature by resetting the board during data commands (to simulate your conditions) and it seems to work better now. Please pull the git repository, upload the sketch and retry your tests. Let us know whether it helped or not.

I tested the external power supply, changed the USB port & cable, different GAL, all the same error message.
Then I tested version 0.4 of sketch, it worked, it read the correct PES.
```
c:\>afterburner_w64 -d COM4 i -t ATF22V10C
testing gal 6
PES raw bytes:
33 43 30 31 56 32 32 46 31 FF
PES info: Atmel ATF22V10C  VPP=10.0 Timing: prog=10 erase=25
```
Now no matter how I replace ATF22V10C or ATF16V8B, PES can be read correctly.

Thanks you, this tool helped me a lot.

Dale-Lien, 2022-03-31:
Hi ole00,
I took out my logic probe to test the RESET pin and found four RESET signals while reading Info and Reading fuse map.
So the problem should be RESET, but that doesn't explain why using the r command can display the correct type?

> Is there a reason why the individual functions of the pc application open and close the serial port? If the serial port is opened only once and closed at the very end of the program, that would fix it in a nice way I suppose. I can give it a try tomorrow.

Hi rreilink,
Looking forward to your test.

ole00, 2022-03-31:
> Is there a reason why the individual functions of the pc application open and close the serial port? If the serial port is opened only once and closed at the very end of the program, that would fix it in a nice way I suppose. I can give it a try tomorrow.

I think it allowed me to 'pause' between commands, open up a serial terminal an query commands. Anyway, I don't like my solution in version 0.4 simply because it hides the issue - why some boards are resetting - they should not be doing that.

ole00, 2022-04-01:
I've received genuine arduino uno and tested it on Linux and Windows 7.  There were 2 issues I found and fixed.
1) serial data transferred from arduino were often split (compared what was sent from Serial.print()) to smaller chunks which tripped the detection of a serial prompt.
2) Windows 7 could not cope with the baud rate 38400. When some serial data were sent from Window 7 PC the buffer (as read on Arduino) was prepended  by always 2 bytes 0xFE or 0xFF. That also caused issues when checking what command was issued from the PC app. The fix was simply to change the baud rate either to 9600 or to 57600. I chose the faster as it seemed reliable.
Both changes also work on my arduino clones and are now pushed to github master.

Dale-Lien, 2022-04-04:
Hi ole00,
My work computer is win7 x64 system.
I use mingw64 in msys2 to compile afterburner.c, and it prompts that `termios.h` is required.
Then use gcc in cygwin to compile afterburner.c, the compilation is successful,
but `failed to open serial device: COM4` is displayed during execution.
I tested it with arduino serial monitor and COM4 works fine at 57600.

So there should be something wrong with my compilation,

Can you tell me how to compile it?
Or can provide V. 0.4 PC-side program?

best regard.

ole00, 2022-04-04:
> I use mingw64 in msys2 to compile afterburner.c, and it prompts that `termios.h` is required.

That's because you did not specify -D_USE_WIN_API_. Take a look at the 'compile_win64.sh' script how I cross-compiled the windows version - it will be very similar on native windows gcc environment (msys2).  I'll release the binaries soon, just need to test the mac version.

Dale-Lien, 2022-04-05:
Thanks, I didn't notice the three .sh files.

Closed 2022-04-07.

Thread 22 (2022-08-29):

Support for GAL20V8A

Fisiekk, 2022-08-29:
So i have few GAL20V8A and wanted to ask if they are supported or is it possible to add support for them

artgodwin, 2023-01-21:
I also have some Lattice 20V8A-15LP I'd like to use. Datecode is L241D12
I have built the programmer with the pin mapping as shown for the adapter and can read the ID OK. It reports

PES info: 5V Lattice GAL20V8  VPP=14.50 Timing: prog=10 erase=25

However, if I set Vpp above about 13V the GAL is apparently destroyed and the PES can no longer be read.

If I attempt to program at 13V the programming works partially : on my first attempt it reported 2000 or so fuse errors. Erasing apparently works ok. However, repeating the programming operation without erasing programmed a lot more fuses. Repeating several times (about 10) got down to a few tens of errors. The last couple of errors took many attempts, perhaps 20 or 30 but eventually worked. Shortly thereafter a repeated verify failed one fuse again but with a few more repetitions it programmed completely and has so far rretained the programming (next day). I haven't tried to verify the functionality yet.

Is this characteristic of any known problems ? Perhaps faulty GALs, or unstable Vpp ? I will try to examine the programming cycle to see if I can find anything going wrong, and perhaps experiment with longer programming pulses. I've had these devices in stock for a long time and have enough to experiment with; it's unlikely they are counterfeit as they date from before that was common but they could be a poor batch, discarded because of low yield.

artgodwin, 2023-01-21:
[Screenshot_2023-01-21_22-39-00](https://user-images.githubusercontent.com/677657/213889877-921f5595-f494-4fe0-b696-37189cdcf331.png)

Fisiekk, 2023-01-21:
Its always decoupling xD

artgodwin, 2023-01-21:
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

ole00, 2023-01-22:
Thanks for the report.

It's interesting what you wrote about re-writing the fuses, but it makes perfect sense that re-writing (with the same bit design) without erase will fix these errors eventually. Flipping the fuse bit (internally inside GAL) requires certain amount of current/voltage and if there is instability then the next bit to flip (especially if there are 2 bits to flip consequently) might not get enough current/voltage to flip the bit properly. Next attempt to write (again speaking of internal logic of the GAL) possibly recognises the bit 1 is already flipped so no current/voltage is applied (and it stays in favourable state to program the next bit, which previously failed flipping), therefore the bit 2 has good conditions to be flipped successfully.

PES info and reported 14.5V:  The VPP value, timing value and erase values are decoded from the PES (chip electronic signature) bytes retrieved from the GAL chip  in the Arduino sketch (with the exception of Atmel GALs). The decoding might be wrong.  It might be worth trying the programming with VPP set to 12V as that's the VPP I normally use with Lattice GALS without issues. If there are still the same writing issues with VPP 12V  as with VPP 13V, the afterburner could be modified to do auto-rewrite (multiple times) if it detects writing errors.

Regarding the scope trace 1 (power dip) - I did not know about that, good that you pointed it out. I scoped 5V rail on my board (scoped on Arduino 5V pin header, powered only via USB) in the same situation and indeed my 5V rail dropped the same way. I tried it with and without GAL chip, both produced the same dip.  Because your main decoupling capacitor is before the switch (and fully charged when the switch-on happens, therefore not contributing to the 5V rail dip) I guess the culprit might be the MT3608 module. Arduino does not seem to be reset when that 5V dip happens. I don't think this should contribute to the writing failures you mentioned though (you might try scoping the 5V rail during writing the GAL fuses, whether there are similar dips on 5V rail). Still worth investigating whether this could be fixed.

Useful design: the main credit goes to Bruce Abbott and Manfred Winterhoff for doing the GAL research and publishing their result and their code.

ole00, 2023-01-22:
Just tested and scoped the MT368 module on its own ad it is the reason why the 5V rail drops when the switch is turned on. No wonder, it has a big inductor.

artgodwin, 2023-01-22:
> Useful design: the main credit goes to Bruce Abbott and Manfred Winterhoff for doing the GAL research and publishing their result and their code.

Yes, I don't underestimate the amount of work there. But those designs have quite a few components and the parallel port dependency makes them awkward. Building onto an arduino and keeping it as simple as possible makes it far more attractive as a quick hack - if it gets much more complex you might as well buy a TL866 and use some of the open source replacement firmware.

For that reason I'd discourage the programmable Vpp. Yes, it would be great .. But unless it's implemented with PWM or some other such cheap solution its going to add a bunch of less common parts and lose the biggest advantage. Even the multiple pinning I suggest elsewhere would be a bad idea if it added more than a few resistors and transistors.

I was also surprised that the 5V switch created such a large drop whilst enabling Vpp didn't. Note that the boost converter isn't enabled at that point - so I guess it has to be the capacitors. That's why I put the 200uF upwind of the switch - I didn't want them having to be charged too.

Interesting that you have found 12V enough. I note that the voltage requested is already 2V less than apparently wanted by the chip's algorithm. I'd speculate that the older chips need higher voltage and are also perhaps more sensitive to overvoltage.

ole00, 2023-01-22:
Complexity of Afterburner and additional features: I completely agree.

The idea of programmable VPP though would still use MT3608 module, but this time it would be used to supply like 18V which would feed LM317T  variable voltage regulator. The output voltage of that regulator (VPP for GAL) would be controlled by digital POT , something like MCP40D18T. It sound simple, but still requires to source less common parts (at least the programmable POT may not be in everyone's drawer). Anyway, I'm not going to add that feature in the near future.

200uF CAP before the switch - thanks for that. I'll test that and modify the design if it reduces the dip at least above 4V.

12V as VPP:  this article (https://k1.spdns.de/Develop/Projects/GalAsm/info/galer/proggal.html) distinguishes 2 different voltage values of  VPP for reading and writing. According to that article GAL reading (like PES reading) requires always 12V, but writing requires higher VPP ranging from 14V to 15.75V.  Afterburner can do only one VPP during the single read/program session, so it is actually quite fortunate that many of the supported GAL types can be programmed by Afterburner using only single VPP for both reading and writing. Of course you encountered writing issue on your  20V8A, so this might be the odd case.

artgodwin, 2023-01-23:
The 2nd trace above is WITH 200uf - it's far from enough to stop the 5V rail froim being sucked down. Admittedly this is the Uno with an inline FET in 5V - you did sday the cheap clones had a betyter 5V rail. But I've now added 1000uF along with some fast ceramics and it still drops by 1V. I'll add a capture tomorrow. I should probably move this to the discussion section, it's well off topic for 20V8s now. I couldn't believe the 10uF ceramic caps on the 3608 board were pulling such a spike so I looked a bit further .. it turns out that even though the device should be disabled by the Vpp enable control, it actually spikes to 10V or so when the power comes on, settling back to the expected 5V in 100ms or so. So the 5V switch, presumably there to protect the GAL from connection  mishaps, is actually quite unhelpful.

artgodwin, 2023-01-23:
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

Blue is unswitched 5V, green is switched 5V (and trigger), yelow is 3608 output. The traces are the same thing, just zoomed to show both the length of the high voltage pulse and the detail of the 5V disturbance. I did also check that the enable pin stayed low during the switch-on

ole00, 2023-01-23:
Sadly, mt3608 datasheet states: " The MT3608 has internal soft start to limit the amount of input current at startup and to also limit the amount of overshoot on the output.". I guess that does not work out very well for both of the parameters (current limit and overshoot).

artgodwin, 2023-01-23:
It does seem less than perfect :)

ole00, 2023-03-28:
@artgodwin I re-read your report about your Lattice  20V8A. I checked GALep's definition for that specific GAL. The VPP they use is 12V. So either the PES data as read from the GAL are incorrect (you reported Afterburner prints 14.5V, so in PES it was 16.5V) or they have to be interpreted differently for each vendor perhaps.  It may also be, that the voltage really needs to be above 13V as you tried, but it needs to be ramped up slowly not to destroy the chip (GALmate uses that techinque for ST chips). Also, on your scope trace you can see that the VPP  during ramp-up has high spikes reaching possibly 14V which may be the cause of the damage. Unfortunately that's a downside of using a switching boost convertor. On the new Afterburner design (programmble VPP) I resolved it by progressively ramping up, slowing the steps as the VPP reaches the desired voltage. Also, the new design adds 3 decoupling CAP on the VPP: 10uF, 100nf and 2nF which help to reduce the VPP spikes during VPP ramp-up. The 5V rail dip, although not nice, should not damage the GAL, most likely it causes Arduino to reset.

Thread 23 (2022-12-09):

Forum wanted

mr-who2012, 2022-12-09:
Is there a forum connected to this project, to discuss troubles when building the device? My afterburner doesn't identify the GALs anymore. At the beginning afterburner did (but reported the GALs wrong).

Now I don't know where to locate the problem: arduino, afterburner, GAL-device or PC. I recognized the caps on the board are all parallel so they sum-up in value. Since the big cap has a tolerance of 20% (see bom.txt), the two small caps may not have an effect, since they are both very small. So I just tried a very large capacitor but without success. Also, measuring the total capacitance in-circuit, gave me a ten-times bigger value than the capacitors have alltogether. I think it's because the power-line is always surrounded by large ground-areas on the board.

All this is very interesting, but maybe completely unrelated to my problem. I tried additional power to the arduino, I tried all voltages from 10V to 14V for the GAL, and I tried three GAL-chips in total. I only have five of the same type and just wait for new chips to arrive. Next step is a logic-analyzer, to see if the chip is sending different signals than arduino/afterburner.

Erasing a chip is possible, but not reading and writing.

ole00, 2022-12-10:
Hi,
I've enabled "Discussions" tab - feel free to share your thoughts.

The issue you described - it might be caused by the change introduced in version 0.4 : baud rate changed to 57600. If that is the case, Please re-upload the .ino sketch to Arduino and recompile the pc software. Hopefully that's the fix.

Related to the caps values. I doubt that is an issue, they are decoupling caps with relatively low values, so should not cause a trouble unless they are faulty or damaged.

Diagnosing the issue: you correctly listed possible faults ( arduino, afterburner, GAL-device or PC) , so  start checking one by one and eliminate them. Start from the PC connection to Arduino via regular serial terminal (teraterm, minicom, putty etc.) and try to issue some basic Afterburner's commands from there. Arduino test: try a basic blinky sketch, and exercise all digital GPIOs. GAL device - try Atmel's ATF16V8B, these are still produced (eliminates a possibility of a GAL fault from an old and used batch) so IMO best to start with.

Also, I found the official Arduino UNO (which I got and tested way later) is not the best option for Afterburner. It has very large voltage drop on the 5V rail when powered via USB cable. Also, I had to replace the voltage regulator on it because the voltage regulator failed early on. So far my best results are using cheap asian Arduino UNO clones.

mr-who2012, 2022-12-13:
Thank you for answer. I am using one of the cheap arduino-clones. Once, I attached 12V-Power-Supply to give the arduino more juice. It _should_ convert it to 5V. However I still had a bad feeling and soon switched to a 5V-Power-Supply and hope my arduino-clone is not damaged now.

I attached a Logic-Analyzer while issuing this command in afterburner:

`afterburner r -t GAL16V8 -d /dev/ttyUSB0 -nc `

I get interesting readings: Arduino is sending address-numbers in 4-bit-steps and correctly switches the GAL to edit-mode (pin2 for edit-mode is not visible in the screenshot). The signals on the /STR-pin also seem to be correct. The clock pulses are always following a falling /STR-pulse to transmit the address to internal register. So that's correct as well. So it seems my arduino is executing the code fine. Not sure if it is important: The whole transmission of adress-numbers is done twice.

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

The following screenshot shows the [different assignment](https://k1.spdns.de/Develop/Projects/GalAsm/info/galer/proggal.html). of pins in edit-mode (fore reference). Pin15 (for data-output) is constantly showing HIGH in my test. So that's wrong!

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

Also, All the VIL-Pins should be tied to ground in edit-mode. But except for pin1 they are all HIGH. It seems on the board they are not connected to the arduino at all. So maybe it's either a faulty chip or wrong pull-down-resistors? Pin1 is correctly LOW-state and has no pull-down at all on the board.

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

I also attached a PDF with the text from the GALer-website. In this version I colored the text and made it more readable. Hopefully it will be of use for somebody else.

[Programming GALs.pdf](https://github.com/ole00/afterburner/files/10216995/Programming.GALs.pdf)

Thank you for the possibility to open discussions. I will switch to it immediately.

ole00, 2022-12-13:
I think you made good progress.

> The whole transmission of adress-numbers is always done twice.

It is not done twice. GAL16V8 has 32 so called 'rows' (or addresses)  which are passed via RA0 - RA5 : that is 6bits - values 0 - 63. Because we have only 32 addresses on GAL16V8 the RA5 should always be 0 (Low) when reading GAL16V8. On your picture you can see ~29 addresses being clocked - the total is probably 32 and that is OK. What seems wrong is
your RAG2 and RAG3 signals - they seem to be duplicates of RAG0 and RAG1. The read command reads fuse bits from each address, and the address is incremented sequentially (see readGalFuseMap() function in afterburner.ino). So RAG2 should look like RAG4 and RAG3 should look like RAG5. Either your probes were incorrectly placed or were touching during measurement (shorted pins).

> Pin12 should produce output as reaction to the clk-pulses.

That is correct if the GAL knows it is in the programming mode - otherwise it processes all inputs as regular inputs and applies previously programmed logic/algorithm to outputs. So you need to check whether the VPP_EN (Arduino IO 11) is enabled during programming and if so, whether the Edit pin (GAL pin 2) has 12V. Ensure the power switch on Afterburner is ON (LED is lit)

> Also, All the VIL-Pins should be tied to ground in edit-mode.

Correct, unless the GAL forces them high via internal algorithm.

> It seems on the board they are not connected to the Arduino at all

Disconnect Arduino (USB and voltage source), unplug the Afterburner board from Arduino, unplug the GAL from the socket. Verify the resistance between each of the pins (13 -17) on the Afterburner connector and ground pin (so check 13-GND, 14-GND etc.). Each of these pins should read around 4700 Ohm on the multimeter.

mr-who2012, 2022-12-15:
Thank you. I will try all that and report back. I opened a diskussion [here](https://github.com/ole00/afterburner/discussions/24) and posted a quick answer.

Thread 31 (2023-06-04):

Not all MT3608 modules are wired the same

meup, 2023-06-04:
I just put together an Afterburner, and I had a heck of time trying to get it calibrated.

I eventually figured out that the MT3608 module that I was using had the wiper and low-side terminals of the pot shorted together.
At first, I tried to work around this by lowering R2's value, but I wasn't able to achieve the 5V-16.5V range.
I eventually chose to desolder the module, desolder the pot, cut the shorting trace, and put it all back together again.
Eventually, I could get it calibrated.

Btw, if you change line 196 of aftb_vpp.h to have less-than-or-equal instead of just less-than, it will avoid an odd corner case for when the voltage reading fails to increase initially and it sets all the indexes to 1.  Of course, you normally shouldn't run into this unless you've got an odd MT3608 module.

Finally, I also faced the issue of my Arduino's A/D measurement of VPP being off (low) by 0.8V (for 16.5V).  I had to increase the value of R7 by 2.4K to get the readings to within 0.1V.  I'm not quite sure why that was the case.

Anyway, I got my chip programmed, and I'd like to thank you for putting this project together.

meup, 2023-06-04:
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

ole00, 2023-06-04:
Thanks for the report and congrats to making it to work! Also, thanks for the image, that's very helpful for others not to fall into the same trap as you. I was not aware such incompatible MT3608 modules exist. I desoldered some of my broken modules (which I damaged during my trials and errors) for comparison. It looks like there is an indication how to spot the incompatible module - I'll put the image with a warning on the main page.

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

ole00, 2023-06-04:
@meup : could you share where you bought your mt3608 module and possibly the seller's name? Thank you.

meup, 2023-06-04:
I got it on Ebay from seller [koo97ie09].  However, their pictures showed several different versions, so which are shipped is probably just the luck of the draw.  Testing for the trace is easy: measure the resistance between the wiper terminal and the lower side of the 2.2K resistor - it will be continuous if the trace is there.  Removing the pot wasn't difficult either: my soldering iron could heat the two wide terminals at the same time, so I just had to alternate heat between the two and the one terminal while using a pointy tweezer stuck under it to provide pressure to lift it away from the board.  I used the same tweezer to clean out the holes, since I didn't have a solder sucker or braid handy.  I used a sharp knife to cut where your purple arrow points (and measured to verify).

The component footprint under the POT is for attaching a fixed resistor instead of the POT for fixed voltage output.

Thinking about this a bit, I suppose an alternate approach to desoldering the POT and cutting the trace is to replace the 2.2K resistor with a ~27K one.  But SMD rework might not be so easy either.

hubertushirsch, 2024-01-27:
I purchased MT3608 modules for Afterburner.
These modules have all the characteristics of the "good modules":
- Wiper screw on the right side
- VIN/VOUT text in sans font
- no component under the pot
Nevertheless, the afterburner could not be calibrated.
After removing the pot, I saw that the wiper was connected to the terminal leading to the 2k2 resistor.
After disconnecting the two connections, the MT3608 module worked perfectly.
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
Greetings
Hubert

ole00, 2024-01-28:
@hubertushirsch thanks for the report. I have one of those and I considered it a good module - clearly I was wrong. I rechecked my module (that looks the same as on your photo) and indeed it has the same connection traces you marked for cut. Perhaps there is a way how to make those modules to work without desoldering the pot (replacing the 2k2 resistor with a higher value?).

ole00, 2024-01-28:
I did a test with the "bad" type of the mt3608 module. They can be used without desoldering the potentiometer by replacing the 2k2 resistor by 15k (possibly 18k) resistor. Using 12k or 20k gives sub-optimal results. Using 10k gives a wrong calibration result.  See the the #47 thread.

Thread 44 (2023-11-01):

Handling >= 10 GAL types

rhgndf, 2023-11-01:
In afterburner.ino line 2252 the type is decoded as `char type = line[1] - '0';`, but in the pc program it is sent as `sprintf(buf, "#t %i\r", (int) gal);`. Above 10, the value will be two chars, which makes the decode wrong.

This can be solved with one of these two solutions:

1. Make the arduino side parse an integer
2. Send `sprintf(buf, "#t %c\r", gal + '0');` instead

ole00, 2023-11-01:
Thanks for the reminder. I've noticed that as well and fixed it locally when I tested/merged your new branch (when the total number of gals increased past 9). I used method 2 in function operationSetGalType() and operationReadFuses(). I'm still waiting for my new GAL18V10, once I verify the code works I'll merge it. Sorry for the delay.

rhgndf, 2023-11-02:
I didn't notice this until I tried to read the PES from a ATF750 that I received recently. Wanted some input on which one is a better solution to fix this issue in the code.

Unfortunately it seems like the ATF750 is broken. It gets really hot after a while in the socket and I can't read the PES.

ole00, 2023-11-04:
I've pushed the fix for the gal type > 9 (I used method 2).

ATF750 - yes, it might be quite complex to make it work.  GALS get hot if they are exposed to high VPP for long amount of time (even more than 3 seconds might be too much). Normally the VPP is On only for less than a second. VPP higher than expected might also fry the GAL chip inside. ATFs usually work with VPP ~ 10V - 10.5V. VPP 12V might be too much for ATF750.

rhgndf, 2023-11-04:
There's quite a few more lines, like in line 1109.

ole00, 2023-11-04:
Ah.. , you are right. Thanks for that - I'll fix it.

rhgndf, 2023-11-05:
Also is there a reason you removed strncmp_P? It was using PROGMEM, so it doesn't consume RAM and it makes the code is a bit more readable?

rhgndf, 2023-11-05:
Sorry to tag on this on the issue but I have a GAL18V10B-15LP and a GAL18V10-15LP and both read and write fine, so I think you might have gotten a bad batch or something. Both have printed markings instead of laser etched.

ole00, 2023-11-05:
I replaced strcmp_P beacuse  to me it is less readable, it introduces dependency to another function/library and the code is ~40 bytes bigger. It's fine to use stncmp on PC app though as the size of the PC app does not matter. I prefer MCU code to be as small as possible.

GAL18V10B-15LP : it's good to know it works for you. I did not write none of them work - I wrote in Troubleshooting section that **some** may not work because of being fake - I think that corresponds to what you described: " I think you might have gotten a bad batch or something. Both have printed markings instead of laser etched.".

> I doubt you need to remove the resistor for version 3.0 mod, since it just acts as a pull-down and a 5V will do just fine since the resistance is big enough.

You might be right, though it looks like the modified board works OK without the resistor. Would there be benefit having the resistor (genuine question)?

rhgndf, 2023-11-05:
For the GAL18V10s, I just wanted to share how my GALs looked, wasn't intending to point to the troubleshooting section.

Fair point on the code size though.

I think there might be a case for pull-downs on all the pins since it avoids floating inputs. Or a resistor between the GAL and the rest of the circuit when it is operating in non-programming mode and the outputs are being driven. On the same note, there could also be a current limiting resistor on the connection between the output of MT3608 and the GAL.

ole00, 2023-11-05:
> I think there might be a case for pull-downs on all the pins since it avoids floating inputs.
I agree, but specifically on ZIF20 the pin is either HIGH or LOW (but not Z state) because it is connected to the shift register's output pin. If the pin is floating then it is meant to be floating (after read/write operation finished).

> On the same note, there could also be a current limiting resistor on the connection between the output of MT3608 and the GAL.
I'm not sure how this VPP is utilised on different GALs. Adding a limiting resistor in series to VPP might break the fuse writing functionality. I guess the different VPP options (10-16.5V) are not there just as some sort of signalling or protection from accidental erase. I think (not confirmed) that the VPP is used physically to support flash writing, therefore limiting the current might cause fuse writing issues. Also, it probably depends on the size of the resistor - I you meant a small resistor (10-50 Ohms) then it would probably work OK. OTOH it would be good to know how much current the VPP draws.

rhgndf, 2023-11-05:
The VPP is definitely used for erasing. Modern devices feature a charge pump that generates the appropriate high voltage in the chip itself to do the erase, see the section on EEPROMs in https://en.wikipedia.org/wiki/Charge_pump.

Closed 2023-11-07.

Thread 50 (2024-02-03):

Multiple bugs in Afterburner software (Calibration Offset)

hubertushirsch, 2024-02-03:
There are bugs in the Arduino sketch and in the PC software for this function. Both must be fixed together.
I made a fork on February 2nd, 2024 to test the fix.
https://github.com/hubertushirsch/afterburner  // the unchanged fork of the master branch
https://github.com/hubertushirsch/afterburner/tree/hubertushirsch-afterburner-B9-fix

**afterburner.ino**
The offset range -20 to 25 (**-co X**) is transposed by the PC software into the range 0..9 and transmitted to the Arduino as command B0..B9. In the Arduino, however, the value **9** is not in the evaluated range, so the calibration around **0.25V** can never take place.

You can see it when you send **B9** to Afterburner on the serial terminal.
```
AFTerburner v.0.5.5
 varVpp
type 'h' for help
I: VPP calib. OK
>
B9
ER: cal offset failed
>
```
In addition, there is a typo in the explanation of the values 1:-1.5V ==> -0.15V
```
--- afterburner.ino     2024-01-28 22:29:17.000000000 +0100
+++ afterburner_fixed.ino       2024-01-29 21:12:33.365225100 +0100
@@ -2700,8 +2700,8 @@
       // small differences in analog ref which is ~3.3 V derived from LDO.
       case COMMAND_CALIBRATION_OFFSET: {
         int8_t offset = line[1] - '0';
-        if (offset >=0 && offset < 9) {
-          //0:-0.2V 1:-1.5V  2: -0.1V 3: -0.05V 4: 0V  5: 0.05V  6: 0.1V 7: 0.15V 8: 0.20V 9:0.25V
+        if (offset >=0 && offset <= 9) {
+          //0:-0.2V 1:-0.15V  2: -0.1V 3: -0.05V 4: 0V  5: 0.05V  6: 0.1V 7: 0.15V 8: 0.20V 9:0.25V
           calOffset = (offset - 4) * 5;
           Serial.print(F("Using cal offset: "));
           Serial.println(calOffset);
```
**afterburner.c**
If this bug is fixed, a bug in the PC program **afterburner.c** still needs to be fixed.
When the PC software is started, the global variable **calOffset** is initialized.
```
125: int calOffset = 0xFFFF; //calibration offset is not applied
```
What does 0xFFFF mean? This is compiler dependent. In an architecture where **int** is set to 16-bit, this would be **-1**, which is a valid calibration offset value in the range **-20..25**. Probably nobody has this architecture anymore today.
In a 32- and 64-bit PC architecture compiler, **int** is set to be at least 32 bits, so **0xFFFF** is a large positive number (**65535**). This is (for now) outside the valid offset range **-20..25**.

But what does the parsing of the command line do in **afterburner.c**?
If there is a -co option on the command line, the value is read. If it is outside **-20...25**, a warning message appears.
```
afterburner.c lines 270..276
    } else if (strcmp("-co", param) == 0) {
         i++;
         calOffset = atoi(argv[i]);
         if (calOffset < -20 || calOffset > 25) {
             printf("Calibration offset out of range (-20..25 inclusive).\n");
         }
     }
```
Some lines later the values are corrected if they were outside the range.
```
afterburner.c lines 281..285
     if (calOffset < -20) {
         calOffset = -20;
     } else if (calOffset > 25) {
         calOffset = 25;
     }
```
However, this occurs outside the **-co** condition, so that **calOffset** then has a valid value in any case. If the **-co** option is missing, this corrects 0xFFFF (which is greater than 25) to 25.

What is the consequence:
With every **b** command from the PC software to the Arduino, a calibration offset is transmitted, regardless of whether a **-co** option is specified or not. Without **-co** option 0xFFFF => 25 => B9 is transmitted. A Verbose output confirms this.
```
$ ./afterburner.exe -d COM15 -v b <=== Executing without -co xx
Afterburner v.0.5.5
opening serial: \\.\COM15
variable VPP board detected
read: 5 ''
opening serial: \\.\COM15
variable VPP board detected
sending 'B9' command...     <= B9 is sending
read: 28 'ER: cal offset failed'   <== This failed in unfixed Arduino software
ER: cal offset failed
sending 'b' command...
VPP voltages are scanned - this might take a while...
....
```
Just because the unfixed Arduino program ignores the value at **B9**, the error in the PC program has no effect. If **afterburner.ino** is already fixed, the calibration offset is set to 0.25V instead. See my fixed branch for changes in **arduino.c**.

As last:
What should actually happen if the **b** command is called without **-co**?

- Should the last value stored in the Arduino's EEPROM be retained?
- Should **b** without **-co** implicitly set the offset to zero, i.e. work like **b -co 0**? Then in **b** without **-co**, **B4** would always have to be sent to the Arduino. That would be my preferred option.

Let's say I'm repairing the Afterburner hardware (pot or something) and need to recalibrate according to the instructions.
Step 1: R9 in middle position
Step 2: **./afterburner s**
Step 3: **./afterburner b** What happens, there is an old offset in the Arduino EEPROM? I get incorrect values.
Step 4: **./afterburner m**
         **./afterburner b -co X**

ole00, 2024-02-04:
Hi Hubert, thank you for the fixes. Well spotted. I noticed the 'ER: cal offset failed' error before and was going to look at it eventually. You fixed it already, so that's great.

> What should actually happen if the b command is called without -co?

I agree, when the calibration offset is not set (-co is not passed as an argument) the calibration offset should be set to 0. That way it is more  clear what is going on..

Thank you for your commits in your merge request, I'll merge it manually by using git (not by using the github's interface).

ole00, 2024-02-04:
Your code fixes have been merged to master. See the master branch. Thanks.

hubertushirsch, 2024-02-04:
Thanks to you too.
What I didn't consider:
When I use an Arduino that has calibration data from a previous use in the EEPROM, the stored calibration offset is always used.
If I do a calibration from the scratch,
```
./afterburner s
```
from the PC or the **t** command on the serial console,
different values shown depending on whether the Arduino has already been used for Afterburner or is fresh out of the box.

hubertushirsch, 2024-02-05:
I tested version 0.5.6. It works as expected.

Regarding the problem of complete recalibration when using the same Arduino. This may be necessary if changes or repairs have been made to the Afterburner circuit board.

I would then do the following (possibly include it in the setup instructions):

Pot R9 in the middle position
**./afterburner b ; Clears the calibration offset (0.00V), ignore all command outputs.**
./afterburner s  ; Continue as in the original setup instructions

Note: Use **b -co 0** on program version 0.5.5 or earlier to clear the calibration offset.

Closed 2024-02-05.

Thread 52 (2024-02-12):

Alternative do MCP413X .,

fredcwbr, 2024-02-12:
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
Howdy,
First of all, thanks for your great work.

I'm trying to build the afterburner, but sourcing those MCP413X pots is really a problem. The pot alternatives are not suited at all.

Was thinking in revamping the V3.0 board, using LM317 controlled by a PWM instead of the MT3608/MCP413X combo. It can withstand a 1.5Amp, and with a rebuild of the input to acomodate a much higher input voltage (say 30V), how much current would programming request? .. Do this 1A fit the bill ?

Another question is about the various voltages. In the code you use indexes to address wiper positions, considering a predefined adjustment, thats really neat. In this new proposed approach, a function handling this indexes would convert to the needed PWM , that way it would give out the correct ratio to LM317.
And the final question. Found voltages ranging from 5V ~ 19V ., .. would there be more? .. .and what would be the minimum step requirement (in volts/step ) ... and the slew rate of the ramp-up  ?

Best Regards..

ole00, 2024-02-12:
Hi Frederico,
thank you for your interest.

I'm sorry to read the MCP hardware is not available where you live.

Unless you want to go for a long journey or redesigning Afterburner's software and hardware I would discourage you from using alternative VPP (voltage programming) solution. Some users can't make the Afterburner to work with the original hardware, but I don't blame them - even a small oversight or imperfection during Afterburner's production can make it unusable. So even though Afterburner is a simple project there are certain complexities.

You have several options and it depends what your goals with Afterburner are:
1) Do you just want to program few GAL16V8 or GAL22V10 (or their Atmel equivalent) IC for another hobby project ?
  If so, then use the legacy hardware design (see version_4_legacy git branch) and set the VPP manually by turning the pot. The current software is compatible with the old design.

2) Do you need to program some other GALs (other than GAL16V8 or GAL22V10) for another hobby project?
  If so, use the legacy hardware design (see point 1) and design an adapter - it is very simple to design an adapter  and it is usually quite cheap. The adapter usually requires signal re-routing to different pins and possibly  few pull down resistors.

3) If you want it for an educational purpose, in a electronic club or hacker space?
  If so, use the legacy hardware design (see point 1) and chose one specific GAL chip you want to use. Then manually adjust VPP for that specific GAL chip and hot-glue the pot so that the students can't accidentally tamper with it.

4) If you really need programmable VPP, then buy MCP4151 which also works with Afterburner. The chip is available on   ebay and Aliexpress (and also on Digikey, Mouser, RS components etc.). It is not cheap, but will worth the money as it will save you a lot of effort redesigning the software and hardware.

5) If you really-really need programmable VPP and even MCP4151 is not a solution for you, then find another variable pot IC  that is available to where you live. A brief look at AD8400ARZ10 shows it might be simple to design an intermediate board that would fit into the MCP4131 footprint and it should behave similarly. A small software modifications would be required though.

6) If you really would like to use the solution you suggested, here are the issues I can see:

  * the PWM pin on Arduino already used for other GPIO purposes. You'd have to swap / remap it with POT_CS (pin A4) - and that requires software changes.
  * new code to control the PWM/VPP would have to be written
  * you'd need external power, presumably 19-20V DC. That seems to me more expensive than a digi pot IC. If it is a very cheap PSU, it might not have a transformer, and that might fry your PC USB port when you connect both the external power and USB serial from Arduino to your PC (grounds from PC and PSU on different level).

To address your questions:

> how much current would programming request? .. Do this 1A fit the bill ?

I did not measure it, but 1A seems more than enough. My guess is that VPP draws less than 250mA.

> In the code you use indexes to address wiper positions ...

Correct. In your case each index would correspond to a different duty cycle of PWM (0 to 255 in 8bit PWM)

>  Found voltages ranging from 5V ~ 19V ., .. would there be more?

Actually there is less than that. You'd need:
* 4.75V to 5V VCC (any value would do)
* 10V to 16.5V in 0.5V steps. Ideally the GAL IC's specify the VPP voltage in 0.25V steps, but so far it seems that
  0.5V steps are sufficient.

If you are looking for an existing solution that drives the VPP via PWM, check GALMate hardware here:
https://www.ythiee.com/2021/06/06/galmate-hardware/

> ..and the slew rate of the ramp-up?

Afterburner's VPP ramps up from 5V to 12V in ~ 1mS. This is mainly to prevent the voltage booster to overhoot the target voltage.

Hope it helps.

fredcwbr, 2024-02-13:
Hi, and thanks for the reply.

> I'm sorry to read the MCP hardware is not available where you live.
If it would be sourced, there is a minimum order of 100 parts... and shipping would be around the same amount. I tried on Mouser, Fornell, Alibaba, AliExpress  and others.  The overall cost would be almost equivalant to a Xgecu;;

> Unless you want to go for a long journey or redesigning Afterburner's software and hardware ......
> want to program few GAL16V8 or GAL22V10 (or their Atmel equivalent)
I'm considering. Although you pointer out two major goals, 16V8s and 22V10s

>  use the legacy hardware design
Was already looking into it

>  want it for an educational purpose, in a electronic club or hacker space?
Yes, on the long run, after getting myself working with it. Not new to electronics., but GALs, CPLDs and FPGA banged on my door.

> really need programmable VPP, then buy MCP4151-104e
I found other pots available that i could bodge a connection, ike the MCP4151, but reading your code, noticed that you read the pots value. Is this for the autodetection? ..

>  AD8400ARZ10 --
Same issue as others, can only order a reel

> If you really would like to use the solution you suggested, here are the issues I can see:
No I don't. Actually I stole  the idea from another project, - GALMate - it uses that solution (in a way)
with a DC-DC converter , and the PWM (not  that creative here)  8-) .

> mapping/remapping, recoding
Well no problem there. Thats my bread and butter., got into this mess for the need do  make an overhaul of a pice of 1970s equipment, with NO docs (great black box), NO schematic, No standards, ..
so its already been over the bench about 3 months now. Got a solution, and will go FPGA so deliveries can be done, but it was annoying havig to get a 240LU FPGA just to do what 8 TTL logics are doing. It hurts.

> To address your questions:
Thank I'll listen carefully

>> 4.75V to 5V VCC (any value would do)
OK gotcha...
>> 10V to 16.5V in 0.5V steps. Ideally the GAL IC's specify the VPP voltage in 0.25V steps, but so far it seems that 0.5V steps are sufficient.
Done!!!

>  VPP via PWM, check GALMate hardware here: https://www.ythiee.com/2021/06/06/galmate-hardware/
Yeah ... stole the hole idea from him...

> Afterburner's VPP ramps up from 5V to 12V in ~ 1mS.
It's in my ballpark.

> Hope it helps.

More than you can imagine.

Best Regards from Sen. Canedo - Goias - Brasil

ole00, 2024-02-14:
Hi Frederico, I have a spare MCP4131 IC. I'm happy to send you one if you want to. If so, contact me via email, issue 'git log' command in the Afterburner's directory to find it.

fredcwbr, 2024-02-15:
Howdy,

Dropped the note there.
Thanks in advance.

and
Best Regards.

fredcwbr, 2024-02-15:
Howdy,

I'ved followed your advice on the legacy version,. and it worked for my immediate need.
As  i'm also closely following the VPP issue with HuberH, decided to dig into legacy and adapt a power source according to that.
Just cloned the legacy branch and will work towards that .,.  will request a pull in due time.

fredcwbr, 2024-02-16:
Howdy,
After careful reading on the NewVPP proposed by HuberH , and looking into the original  V3, it occured to me that your using 4131 as a reostat to GND.
Did a try with a  PCF and a R2R 8 bit resistor DAC , and it worked the same.
Can still read the PCF , and using OC, it does not interfere with the boost.

So i can make a piggyback on the  DIP8 3141 socket and put whats needed there to emulate. Just to stay true to V3 for now.

ole00, 2024-02-16:
Yes, MCP4131 works as a rheostat. The resistor 'DAC' could possibly be used along with another 595 shift register (untested). The idea is that the resistors could be connected to the outputs of the 595 shift register. If the shift register value would be 0, then all resistors would conduct to GND (low pot value). If value 255 would be set to the shift register, then the resistors would not conduct (maximum resistance - actually this situation would have to be handled by another resistor in parallel, so that the total Feedback resistance would be ~25k Ohm). Any other value would pass some current through resistors (where the bits on 595 outputs are set to 0).  A clever selection of 8 (or 9) resistors would have to be calculated so that their parallel combinations would give a value between 10k to 25k.

ole00, 2024-02-16:
The downside of the above solution is that the 595 has a bigger footprint and also it would require more resistors to fit on the PCB. Therefore the Afterburner's PCB area would have to be bigger (if through hole components are required). The R9 pot could possibly be removed as the new rheostat could possibly be more precise (no need for the POT compensation ins such case).
Actually, MCP4131 has only 128 taps, therefore only 7 outputs from the 595 would be needed.

fredcwbr, 2024-02-16:
Keeping the footprint inside arduinos shield factory format is a need... did i understand this correctly?   Any other concerns?

Closed 2024-02-13.

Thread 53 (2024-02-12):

Some code questions

hubertushirsch, 2024-02-12:
I'm trying to understand your code better. I noticed sequences that were not clear to me.

**afterburner.ino**
```
0120: #define READPES 2

1033: // GAL init sequence
      static void turnOn(char mode) {
          setupGpios(OUTPUT);

          if (mode == READPES) {
              mode = 2;               // mode = 2 = READPES -> there is no change
1039:     } else
..........
1065:     setVPP(mode);
          delay(20);
1068: }
```
You test **mode** for the value **READPES**, which is defined with the value **2**. **if mode == 2 then mode = 2** ???

**afterburner.ino**
There is a global variable **vpp**, which is set to a type-specific value depending on the GAL type.
In **setVpp()** you calculate a value **v** (line 852), which is used in **varVppSet(v)** (line 860) as an index in **vppWiper[v]** .
**vppWiper[]** contains the wiper values for the calibrated voltages from the EEPROM.

In lines 849/850 you set **vpp = 40** for a limitation to 12V. But your formula leads to 10V (**v = 2** (index VPP_10V0)).
See my included comments. 12V would be the result at **vpp = 48** ==> **v = 6** (index VPP_12V0).
Which is correct here, 10V or 12V?
```
0379: static uint8_t vpp = 0;

0832: static void setVPP(char on) {
          // new board desgin
          if (varVppExists) {
0835:         // uint8_t v = VPP_11V0;
              uint8_t v;     // v is recalculated in each case; initialization of the variable is unnecessary
..........
0844:         } else {
                  //safety check
                  if (vpp < 36) {      // set vpp < minimum to 9V0
                      vpp = 36; //9V   // ==> v = (36 / 2) - 18 = 0 ==> VPP_9V0
                  } else
0849:             if (vpp > 66) {      // set vpp > maximum to 10V0
0850:                 vpp = 40; //12V  // ==> v = (40 / 2) - 18 = 2 ==> VPP_10V0 !!!!!!
0851:             }
                  // 36 <= vpp <= 66      ==> v = 0 ... 15 ==> VPP_9V0 ... VPP_16V5
0852:             v = (vpp >> 1) - 18; // 18: 2 * 9V, resolution 0.5V (not 0.25V) hence 'vpp >> 1'
      #if 0          
                  ......
      #endif          
              }
0860:         varVppSet(on ? v : VPP_5V0);
              delay(50); //settle the voltage
0862:     }
```

ole00, 2024-02-16:
The first snippet (mode = 2): it is there for posterity, just to remind me when the VPP is turned on during PES reading, the mode is set to 2. It could be optimised a little bit, but the code works fine as it is.

The second question (Which is correct here, 10V or 12V?).  I see what you mean, the comment is not correct. Yes, it would be worth setting the vpp to 12V. I'll do it eventually.

Thanks for the report.

hubertushirsch, 2024-02-16:
Thanks for the explanation.

I was wondering because you are calling **setVpp(mode)** with **mode** (with the numeric values 0, 1 or 2) as an argument (line 1065).
In **setVpp()** the argument is evaluated with **if (on == READPES)** (line 838).
So in **turnOn()** **READPES** becomes the numeric **2** in order to be compared again with **READPES** in **setVpp()**.
Very confusing.

Why are the arguments **mode** in **turnOn()** and **on** in **setVpp()** declared as **char** even though they are used with numeric values?
```
Code line numbers based on v0.5.6

0832: static void setVPP(char on) {
          // new board desgin
          if (varVppExists) {
              uint8_t v = VPP_11V0;

              // when PES is read the VPP is not determined via PES
0838:         if (on == READPES) {
0839:             if (gal == ATF16V8B || gal == ATF20V8B || gal == ATF22V10B || gal == ATF22V10B) {
      .....
0874: }

1034: static void turnOn(char mode) {
          setupGpios(OUTPUT);

          if (mode == READPES) {
              mode = 2;
1039:     } else
      .....
1065:     setVPP(mode);
          delay(20);
1068: }
```
For example, using an enumeration for the three different values of **mode** could improve clarity.
```
typedef enum {
  VppOff,
  VppOn,
  VppReadPES
} VppMode;
```
Greetings

hubertushirsch, 2024-02-28:
ok, I see it is corrected to 12V (vpp = 48).

Closed 2024-02-28.

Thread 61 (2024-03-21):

ZIF Socket is not powerless when removing a GAL

hubertushirsch, 2024-03-21:
I have observed that when removing a GAL (currently only have ATF16V8B) the LED sometimes flashes.
This depends on how I move the chip when removing it and in which order the pins lose contact on the ZIF socket.
Since the Powerswitch SW1 is switched off, the current through the LED must come from another connection on the ZIF socket that has a HIGH level and flow through the inactive GAL chip.
In fact, ZIF16 (Arduino D9, DOUT for this GAL type) is set to HIGH due to the pin mode on D9
```pinMode(PIN_ZIF16, INPUT_PULLUP); //DOUT```
after the first command.
A test shows: When connecting a wire from ZIF16 to ZIF15, the LED lights up.

I don't know whether this could destroy the GAL when plugging or removing it in the worst case scenario.
Is it possible to change the sketch so that there is no HIGH level at the DOUT of the last selected GAL type if the GAL is not addressed by a command?
The best would be a pulldown resistor, but this cannot be programmed on the Arduino input.
The alternative would be INPUT without pullup, but that would be a floating input.

ole00, 2024-03-22:
Well spotted. Yes, it is a bug - the DOUT pin (output from GAL, input to arduino)  should be set to input , not input pull-up when inactive.  Ideally all pins leading to the ZIF socket should be completely isolated (because even a pin set to input can damage Arduino's gpio circuitry), but that would require more ICs on the board leading to higher board complexity and higher cost.
It is now fixed in commit 1589119e7c4f144fd4dca17e199bb6b854f70574
Thanks for the report.

hubertushirsch, 2024-03-22:
Thanks for the fix, seems to be working.

Hubert

Closed 2024-03-22.

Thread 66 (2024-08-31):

Afterburner seems to destroy GAL

Paul-AGI, 2024-08-31:
I built the latest version of the afterburner and I'm trying to use it to program some Lattice GAL16V8B chips.  I'm using one of the newer MT3608 modules where I had to replace the 2.2K resistor with a 15K resistor.  After that, callibration went fine.

Everything seems fine, putting the chip in with the i command gets me

$afterburner i -t GAL16V8
PES info: 5V Lattice GAL16V8  VPP=12.0 Timing: prog=40 erase=25

I can erase it without an error, but after writing a JED file produced by CUPL with a g16v8 device definition, I get this:
$ afterburner wv -t GAL16V8 -f STATEMAC.JED
Uploading fuse map...
2194/2194 |########################################|
ER unknown or wrong GAL type (check Power ON)

then when trying an i command again, I get this:
$ afterburner i -t GAL16V8
PES info: 5V Unknown GAL,  try VPP=10..14 in 1V steps

This does the same behavior with a Lattice GAL16V8D as well

Any clues on where to look on this?  I didn't use a PCB but it follows v3.1 of the schematic.

ole00, 2024-09-02:
Hi Paul,

sorry to hear your Afterburner does not work as intended. You mentioned you did not use Afterburner PCB, did you use breadboard? Or did you use veroboard? Could you send a picture of your Afterburner (ideally both sides - if you use some board to solder parts)? Also, you mentioned the calibration was OK. Could you run the afterburner's 'm' command again to measure voltages (while no GAL chip is inserted) to verify the MT3608 module is still working OK?
With the new Afterburner design (with the VPP voltage booster) the errors you described in general are:
- the VPP does not work correctly (hence the new VPP measurement with the 'm' command),
- or the is a soldering mistake (a bridge, or wrong resistor value or bad solder joint)
- ZIF socket contacts are worn out, therefore a pin can have a bad/unstable connection (reseating the IC or pushing down on it while reading the GAL might help)

Paul-AGI, 2024-09-03:
I'm sure I have a mistake somewhere.

The m command returns:
afterburner m

VPP calib. offset: 5
VPP: 4.2 - 5.0V : 4.69
VPP: 9.0V : 8.99
VPP: 12.0V : 11.97
VPP: 14.0V : 13.99
VPP: 16.0V : 15.99

Those values are within +/- .02V of actual.

Doing a read with -nc after writing  shows no change to the fuse map but a zeroed PES.  Attempting to write the PES results in no change.  The programming voltage during writing was 11.95.  I used a new zif socket (although it's probably a counterfeit).

The first write on a new 16V8 works, but overwrites the pes so the verify fails.  The erase and read work before writing.

This was breadboarded using a Nano and everything has been triple checked, but clearly I'm missing something.  I'll put a LA on the chip and see if the programming looks reasonable; maybe I can catch what's going on.  I did find the GALblast description of the programming algorithm so that might help me see what's going on.

Paul-AGI, 2024-09-04:
I pulled the gal and hooked up a LA.  This is the capture I get with this command

afterburner p -t GAL16V8 -pes 00:05:1A:A1:CD:A4:03:06  -nc

Although it takes up the complete screen, that is the complete capture, there is no activity after that.

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

In particular, the SDIN and SCLK do not look right to me.  This should be clocking in 64 bits, right?

ole00, 2024-09-09:
Perhaps I don't read your capture screen shot correctly, but it seems to me the sample rate is one sample every 4 ms, which is 250Hz. That is not fast enough to read the Afterburner data properly. Try to increase sample rate to at least 1MHz to check whether you can get better clock and data values in your logic analyser.

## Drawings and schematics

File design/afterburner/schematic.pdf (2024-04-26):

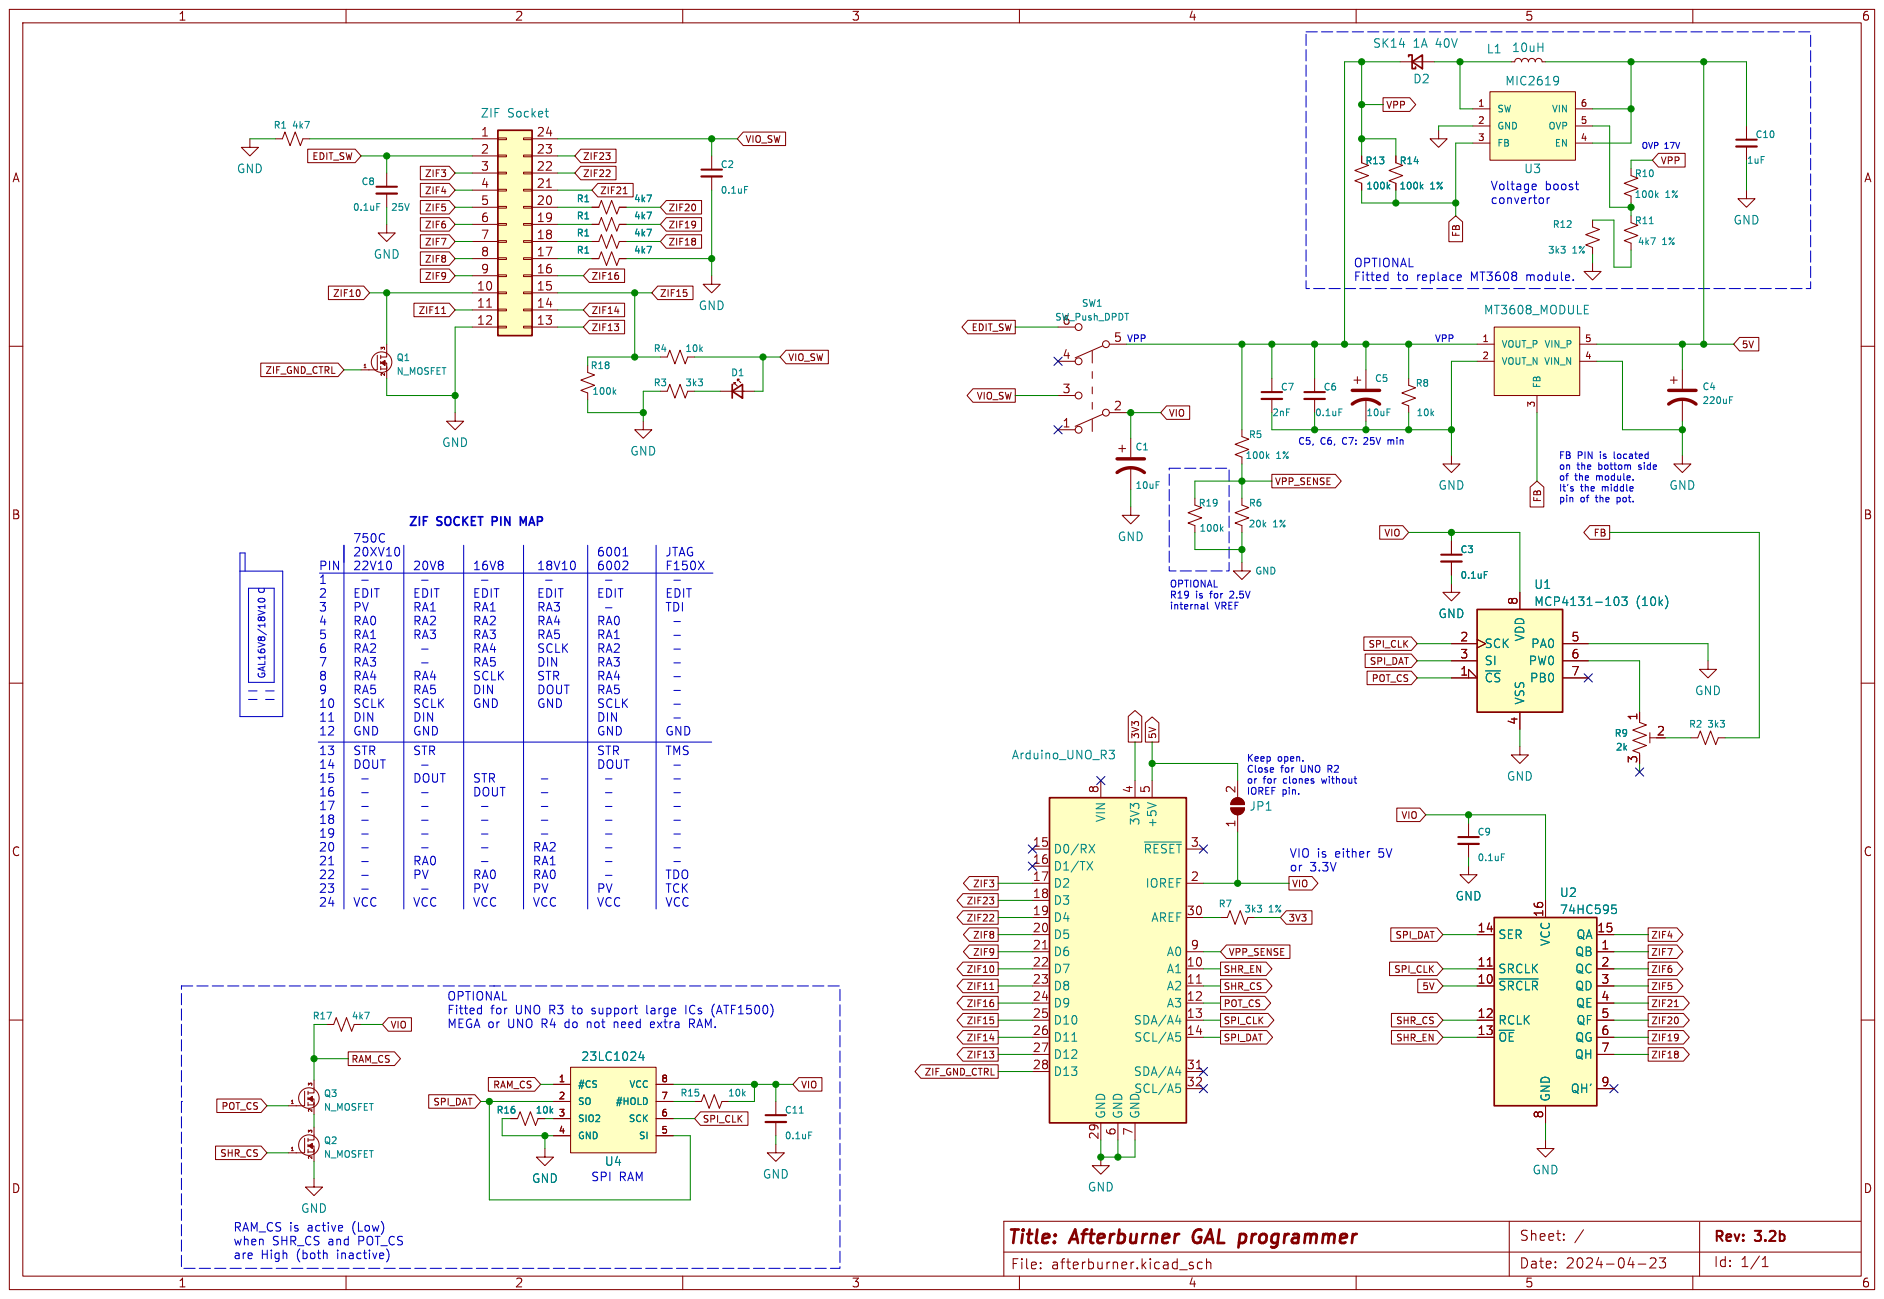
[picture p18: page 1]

9ZIF Socket
pin of the pot. Voltage boost convertor OPTIONAL Fitted for UNO R3 to support large ICs (ATF1500) MEGA or UNO R4 do not need extra RAM. SPI RAM
ZIF6 ZIF5

FB PIN is located
on the bottom side
of the module.
It's the middle

ZIF SOCKET PIN MAP
- EDIT RA1 RA2 RA3 RA4 RA5 SCLK DIN GND

- EDIT PVRA0 RA1 RA2 RA3 RA4 RA5 SCLK DIN GND

Keep open. Close for UNO R2

IOREF pin. RAM_CS is active (Low) when SHR_CS and POT_CS

or for clones without

are High (both inactive)

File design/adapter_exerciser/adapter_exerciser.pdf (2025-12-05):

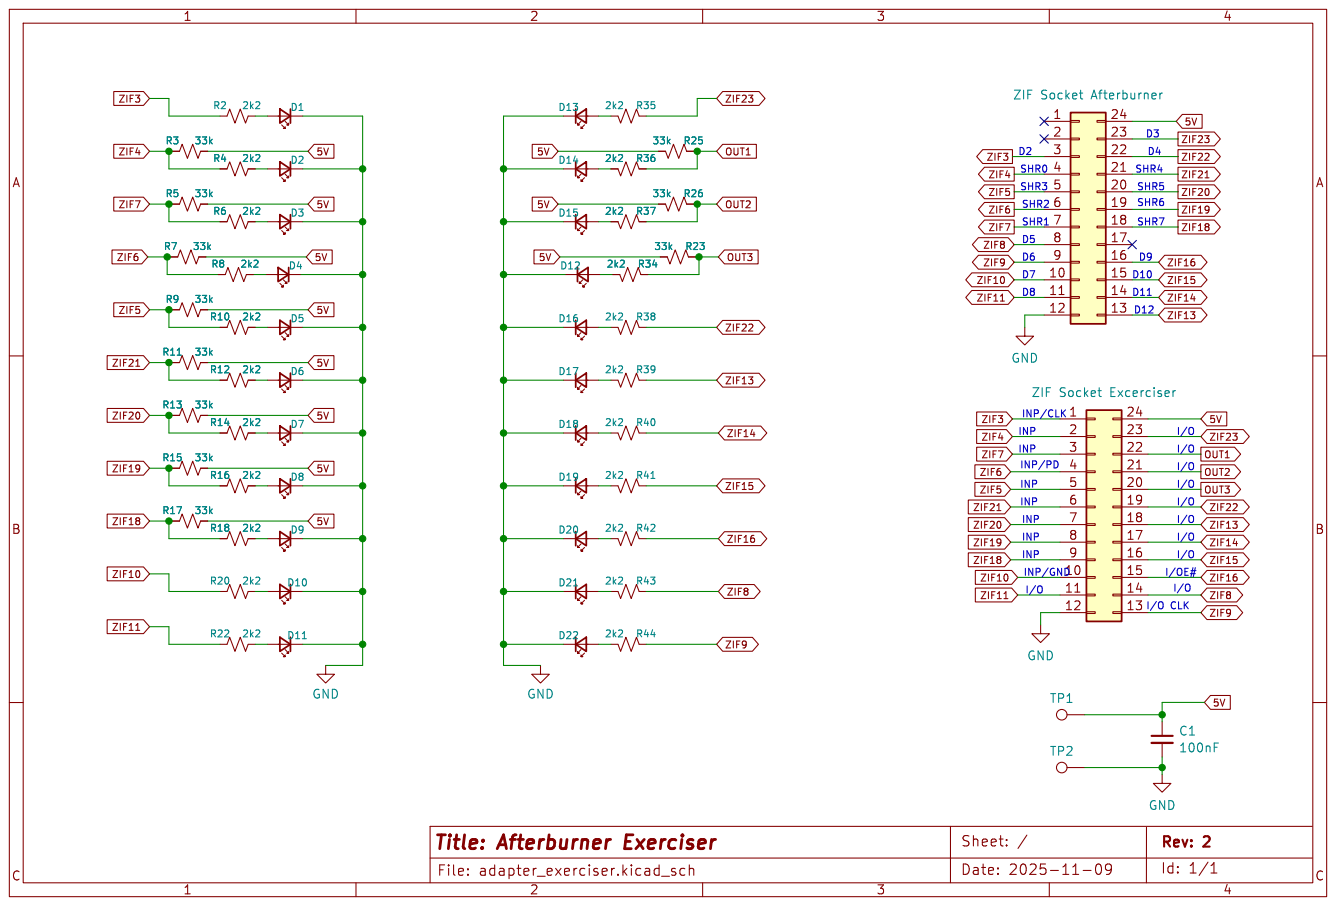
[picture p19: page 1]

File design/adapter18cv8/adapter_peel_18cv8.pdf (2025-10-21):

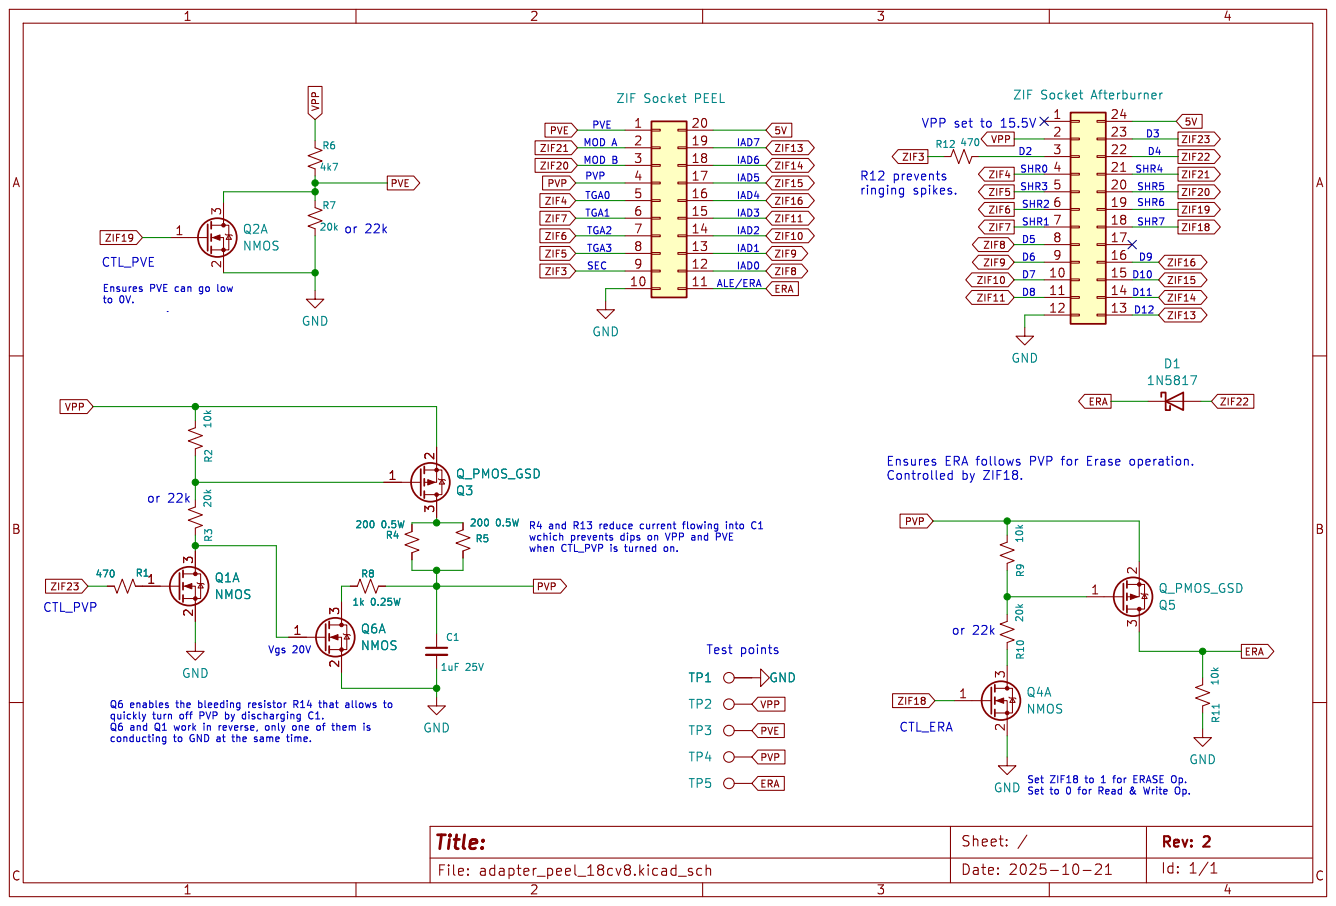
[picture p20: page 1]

Ensures PVE can go low

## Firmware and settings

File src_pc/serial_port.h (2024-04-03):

#ifndef _SERIAL_PORT_H_
#define _SERIAL_PORT_H_


char guessedSerialDevice[512] = {0};

#ifdef _USE_WIN_API_

#include <windows.h>

#define SerialDeviceHandle HANDLE
#define DEFAULT_SERIAL_DEVICE_NAME "COM1"
#define INVALID_HANDLE  INVALID_HANDLE_VALUE

#ifdef NO_CLOSE
static SerialDeviceHandle serH = INVALID_HANDLE;
#endif

// ideas: https://stackoverflow.com/questions/1388871/how-do-i-get-a-list-of-available-serial-ports-in-win32
static void serialDeviceGuessName(char** deviceName) {
    char buf[64 * 1024] = {0};
    int size = QueryDosDevice(NULL, buf, 64 * 1024);
    int topComNum = 0;

    // buffer was filled in
    if (size > 0) {
        char* text = buf;
        int pos = 0;
        int start = 0;

        // search the received buffer for COM string
        while (pos < size) {
            int nameLen;
            start = pos;
            // find the string terminator
            while(pos < size && buf[pos] != 0) {
                pos++;
            }
            nameLen = pos - start;
            // COM port found
            if (nameLen >= 4 && nameLen <=6 && 0 == strncmp(text, "COM", 3) && text[3] >= '0' && text[3] <= '9') {
                int comNum = atoi(text + 3);
                if (comNum > topComNum) {
                    topComNum = comNum;
                    strcpy(guessedSerialDevice, text);
                }
            }
            pos++;
            text = &buf[pos];
        }
        
        // if we have found a COM port then pass it back as the result
        if (topComNum > 0) {
            *deviceName = guessedSerialDevice;
        }
    }
}

// https://www.xanthium.in/Serial-Port-Programming-using-Win32-API

static inline SerialDeviceHandle serialDeviceOpen(char* deviceName) {
    SerialDeviceHandle h;

#ifdef NO_CLOSE
    if (serH != INVALID_HANDLE) {
        return serH;
    }
#endif

    h = CreateFile(
        deviceName,                  //port name
        GENERIC_READ | GENERIC_WRITE, //Read/Write
        0,                            // No Sharing
        NULL,                         // No Security
        OPEN_EXISTING,// Open existing port only
        0,            // Non Overlapped I/O
        NULL);        // Null for Comm Devices

    if (h != INVALID_HANDLE) {
        BOOL result;
        COMMTIMEOUTS timeouts = { 0 };

        DCB dcbSerialParams = { 0 }; // Initializing DCB structure
        dcbSerialParams.DCBlength = sizeof(dcbSerialParams);
    
        result = GetCommState(h, &dcbSerialParams);

        if (!result) {
            return INVALID_HANDLE;
        }

        dcbSerialParams.BaudRate = CBR_57600; // Setting BaudRate
        dcbSerialParams.ByteSize = 8;         // Setting ByteSize = 8
        dcbSerialParams.StopBits = ONESTOPBIT;// Setting StopBits = 1
        dcbSerialParams.Parity   = NOPARITY;  // Setting Parity = None
        dcbSerialParams.fOutxCtsFlow = FALSE;
        dcbSerialParams.fOutxDsrFlow = FALSE;
        dcbSerialParams.fDtrControl = DTR_CONTROL_DISABLE;
        dcbSerialParams.fOutX = FALSE;
        dcbSerialParams.fInX = FALSE;
        dcbSerialParams.fRtsControl = RTS_CONTROL_DISABLE;
        dcbSerialParams.fBinary = TRUE;
        

        result = SetCommState(h, &dcbSerialParams);
        if (!result) {
            return INVALID_HANDLE;
        }

        timeouts.ReadIntervalTimeout         = 30; // in milliseconds
        timeouts.ReadTotalTimeoutConstant    = 30; // in milliseconds
        timeouts.ReadTotalTimeoutMultiplier  = 10; // in milliseconds
        timeouts.WriteTotalTimeoutConstant   = 50; // in milliseconds
        timeouts.WriteTotalTimeoutMultiplier = 10; // in milliseconds

        result = SetCommTimeouts(h, &timeouts);
        if (!result) {
            return INVALID_HANDLE;
        }
        //ensure no leftover bytes exist on the serial line
        result = PurgeComm(h, PURGE_RXCLEAR | PURGE_TXCLEAR | PURGE_RXABORT | PURGE_TXABORT);
#ifdef NO_CLOSE
        serH = h;
#endif
        return h;
    } else {
        return INVALID_HANDLE;
    }
  
}

void serialDeviceCheckName(char* name, int maxSize) {
    int nameLen = strlen(name);
    //convert comxx to COMxx
    if (strncmp(name, "com", 3) == 0 && (nameLen > 3 && name[3] >= '0' && name[3] <= '9')) {
        name[0] = 'C';
        name[1] = 'O';
        name[2] = 'M';
    }

    // convert COMxx and higher to \\\\.\\COMxx
    if (strncmp(name, "COM", 3) == 0 && (nameLen > 4 && name[3] >= '0' && name[3] <= '9')) {
        if (nameLen + 4 < maxSize) {
            int i;
            for (i = nameLen - 1; i >= 0; i--) {
                name[ i + 4] = name[i]; 
            }
            name[0] = '\\';
            name[1] = '\\';
            name[2] = '.';
            name[3] = '\\';
        }
    }
}

static inline void serialDeviceClose(SerialDeviceHandle deviceHandle) {
#ifndef NO_CLOSE
    CloseHandle(deviceHandle);
#endif
}

static inline int serialDeviceWrite(SerialDeviceHandle deviceHandle, char* buffer, int bytesToWrite) {
    DWORD written = 0;
    WriteFile(deviceHandle, buffer, bytesToWrite, &written, NULL);
    return (int) written;
}

static inline int serialDeviceRead(SerialDeviceHandle deviceHandle, char* buffer, int bytesToRead) {
    DWORD read = 0;
    ReadFile(deviceHandle, buffer, bytesToRead, &read, NULL);
    return (int) read;
}

#else

#include <ctype.h>
#include <fcntl.h>
#include <errno.h>

#include <termios.h>


#define SerialDeviceHandle int
#define DEFAULT_SERIAL_DEVICE_NAME "/dev/ttyUSB0"

#define INVALID_HANDLE -1
#ifdef NO_CLOSE
static SerialDeviceHandle serH = INVALID_HANDLE;
#endif


#ifdef _OSX_
    #define CHECK_SERIAL() (text != NULL)
    #define LIST_DEVICES  "ls -1 /dev/tty.usb* /dev/tty.wchusb* 2>/dev/null"
#else    
    #define CHECK_SERIAL() (text != NULL && 0 == strncmp(text + 18, "usb-", 4))
    #define LIST_DEVICES "ls -1 /dev/serial/by-id/* 2>/dev/null"
#endif    

// ideas: https://unix.stackexchange.com/questions/647235/debian-how-to-identify-usb-devices-with-similar-dev-tty-file
//        https://pubs.opengroup.org/onlinepubs/009696799/functions/popen.html
static void serialDeviceGuessName(char** deviceName) {
    int i;
    char text[512];
    int topTtyNum = 0;

    FILE* f = popen(LIST_DEVICES, "r");
    if (f == NULL) {
        return;
    }
    i = 1;
    while (fgets(text, 512, f) != NULL) {
        // filer out non USB devices and prioritise those with Arduino name
        if (CHECK_SERIAL()) {
            int ttyNum  = i;
            int textLen = strlen(text);
            // prefer Arduino over generic USB serial ports (does not work on OSX)
            if (textLen > 29 && 0 == strncmp(text + 18, "usb-Arduino", 11)) {
                ttyNum += 1000;
            }
            if (ttyNum > topTtyNum) {
                topTtyNum = ttyNum;
                strcpy(guessedSerialDevice, text);
                //strip the new-line trailing markers
                if (guessedSerialDevice[textLen - 1] == '\n' || guessedSerialDevice[textLen - 1] == '\r') {
                    guessedSerialDevice[textLen - 1] = 0;
                }
            }
        }
        i++;
    }
    pclose(f);

    if (topTtyNum > 0) {
        *deviceName = guessedSerialDevice;
    }
}

static inline SerialDeviceHandle serialDeviceOpen(char* deviceName) {

    SerialDeviceHandle h;
#ifdef NO_CLOSE
    if (serH != INVALID_HANDLE) {
        return serH;
    }
#endif
    
    h = open(deviceName, O_RDWR | O_NOCTTY  | O_NONBLOCK);

    if (h != INVALID_HANDLE) {
        //set the serial port parameters
        struct termios serial;

        memset(&serial, 0, sizeof(struct termios));
        cfsetispeed(&serial, B57600);
        cfsetospeed(&serial, B57600);

        serial.c_cflag |= CS8; // no parity, 1 stop bit
        serial.c_cflag |= CREAD | CLOCAL;

        if (0 != tcsetattr(h, TCSANOW, &serial)) {
            close(h);
            printf("Error: failed to set serial parameters %i, %s\n", errno, strerror(errno));
            return INVALID_HANDLE;
        }

        //ensure no leftover bytes exist on the serial line
        tcdrain(h);
        tcflush(h, TCIOFLUSH); //flush both queues
#ifdef NO_CLOSE
        serH = h;
#endif
        return h;
    } else {
        return INVALID_HANDLE;
    }
}

void serialDeviceCheckName(char* name, int maxSize) {
    //nothing to check    
}

static inline void serialDeviceClose(SerialDeviceHandle deviceHandle) {
#ifndef NO_CLOSE
    close(deviceHandle);
#endif
}

static inline int serialDeviceWrite(SerialDeviceHandle deviceHandle, char* buffer, int bytesToWrite) {
    return write(deviceHandle, buffer, bytesToWrite);
}

static inline int serialDeviceRead(SerialDeviceHandle deviceHandle, char* buffer, int bytesToRead) {
    return read(deviceHandle, buffer, bytesToRead);
}
#endif

#endif /* _SERIAL_PORT_H_ */

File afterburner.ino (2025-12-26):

                                                                      /*                                                               
                                       (banner font: aciiart.eu)
  _____________________________________________________________
 |       _    __ _            _                                \
 |      / \  / _| |_ ___  _ _| |__  _   _ _ __ ___  ___  _ _   |\
 |     / _ \| |_| '_/ _ \| '_/ '_ \| | | | '_/  _ \/ _ \| '_/  ||
 |    / ___ \  _| |_| __/| | | |_) | |_| | | | | | | __/| |    ||
 |   /_/   \_\|  \__\___||_| |____/\___,_|_| |_| |_|___||_|    ||     
 \_____________________________________________________________||
   '------------------------------------------------------------'

   Afterburner: GAL IC Programmer for Arduino by -= olin =-

   Based on ATFblast 3.1 by Bruce Abbott 
     http://www.bhabbott.net.nz/atfblast.html
   
   Based on GALBLAST by Manfred Winterhoff
     http://www.armory.com/%7Erstevew/Public/Pgmrs/GAL/_ClikMe1st.htm

   Based on GALmate by Yorck Thiele
     https://www.ythiee.com/2021/06/06/galmate-hardware/

   Supports:
   * National GAL16V8
   * Lattice GAL16V8A, GAL16V8B, GAL16V8D
   * Lattice GAL22V10B
   * Lattice GAL20V8
   * Atmel ATF16V8B, ATF16V8C, ATF22V10B, ATF22V10CQZ 

   Requires:
   * afterburner PC program to upload JED fuse map, erase, read etc.
   * simple programming circuit. See: https://github.com/ole00/afterburner

   * 2024-02-02 Fixed: Command 'B9' (Calibration Offset = 0,25V) doesn't work
                Note: Also requires elimination of a  in the PC program afterburner.c
                Added: 10.0V measurement in measureVppValues(()
                                                                       */


#define VERSION "0.6.2"

//#define DEBUG_PES
//#define DEBUG_VERIFY

//ARDUINO UNO pin mapping
//    GAL PIN NAME | ARDUINO UNO PIN NUMBER

//programing voltage control pin
#define PIN_VPP        11
#define PIN_SDOUT      12
#define PIN_STROBE     13
#define PIN_PV         9
#define PIN_SDIN       8


#define PIN_RA0         10
#define PIN_RA1         2
#define PIN_RA2         3
#define PIN_RA3         4
#define PIN_RA4         5
#define PIN_RA5         6
#define PIN_SCLK        7

// pin multiplex: ZIF_PIN <----> ARDUINO PIN or Shift register pin (0b1xxx)
#define PIN_ZIF3          2
#define PIN_ZIF4          0b1
#define PIN_ZIF5          0b1000
#define PIN_ZIF6          0b100
#define PIN_ZIF7          0b10
#define PIN_ZIF8          5
#define PIN_ZIF9          6
#define PIN_ZIF10         7
#define PIN_ZIF11         8
#define PIN_ZIF13         12
#define PIN_ZIF14         11
#define PIN_ZIF15         10
#define PIN_ZIF16         9
#define PIN_ZIF20         0b100000
#define PIN_ZIF21         0b10000
#define PIN_ZIF22         4
#define PIN_ZIF23         3
#define PIN_ZIF_GND_CTRL  13

#if CONFIG_IDF_TARGET_ESP32S2 == 1
//A0: VPP sense
//A3: DIGI_POT CS
#define A0   14
#define A1   15
#define A2   16
#define A3   17
//clk and dat is shared SPI bus
#define A4  18
#define A5  21
#endif

// AVR, or UNO R4
//A0: VPP sense
//A3: DIGI_POT CS
#define PIN_SHR_EN   A1
#define PIN_SHR_CS   A2
//clk and dat is shared SPI bus
#define PIN_SHR_CLK  A4
#define PIN_SHR_DAT  A5

#define COMMAND_NONE 0
#define COMMAND_UNKNOWN 1
#define COMMAND_IDENTIFY_PROGRAMMER '*'
#define COMMAND_HELP 'h'
#define COMMAND_UPLOAD 'u'
#define COMMAND_DEBUG 'd'
#define COMMAND_READ_PES 'p'
#define COMMAND_WRITE_PES 'P'
#define COMMAND_READ_FUSES 'r'
#define COMMAND_WRITE_FUSES 'w'
#define COMMAND_VERIFY_FUSES 'v'
#define COMMAND_ERASE_GAL 'c'
#define COMMAND_ERASE_GAL_ALL '~'
#define COMMAND_UTX '#'
#define COMMAND_ECHO 'e'
#define COMMAND_TEST_VOLTAGE 't'
#define COMMAND_SET_GAL_TYPE 'g'
#define COMMAND_ENABLE_CHECK_TYPE 'f'
#define COMMAND_DISABLE_CHECK_TYPE 'F'
#define COMMAND_ENABLE_SECURITY 's'
#define COMMAND_ENABLE_APD 'z'
#define COMMAND_DISABLE_APD 'Z'
#define COMMAND_MEASURE_VPP 'm'
#define COMMAND_MEASURE_CUSTOM 'M'
#define COMMAND_CALIBRATE_VPP 'b'
#define COMMAND_CALIBRATION_OFFSET 'B'
#define COMMAND_JTAG_PLAYER 'j'
#define COMMAND_EXERCISE 'X'
#define COMMAND_EXERCISE_SET_PINS 'x'


#define READGAL 0
#define VERIFYGAL 1
#define READPES 2
#define SCLKTEST 3
#define WRITEGAL 4
#define ERASEGAL 5
#define ERASEALL 6
#define BURNSECURITY 7
#define WRITEPES 8
#define VPPTEST 9
#define INIT 100

//check GAL type before starting an operation
#define FLAG_BIT_TYPE_CHECK (1 << 0)

// ATF16V8C flavour
#define FLAG_BIT_ATF16V8C (1 << 1)

// Keep the power-down feature enabled for ATF C GALs
#define FLAG_BIT_APD (1 << 2)

// In Exercising mode
#define FLAG_BIT_EXERCISE (1 << 3)

// contents of pes[3]
// Atmel PES is text string eg. 1B8V61F1 or 3Z01V22F1
//                                 ^           ^
#define LATTICE 0xA1
#define NATIONAL 0x8F
#define SGSTHOMSON 0x20
#define ATMEL16 'V'
#define ATMEL22 '1'
#define ATMEL750 'C'
#define ATMEL750L 'L'

typedef enum {
  UNKNOWN,
  GAL16V8,
  GAL18V10,
  GAL20V8,
  GAL20RA10,
  GAL20XV10,
  GAL22V10,
  GAL26CV12,
  GAL26V12,
  GAL6001,
  GAL6002,
  ATF16V8B,
  ATF20V8B,
  ATF22V10B,
  ATF22V10C,
  ATF750C,
  PEEL18CV8,
  LAST_GAL_TYPE //dummy
} GALTYPE;

typedef enum {
  PINOUT_UNKNOWN,
  PINOUT_16V8,
  PINOUT_18V10,
  PINOUT_20V8,
  PINOUT_22V10,
  PINOUT_600,
  PINOUT_18CV8, //PEEL18CV8
} PINOUT;

#define BIT_NONE 0
#define BIT_ZERO 1
#define BIT_ONE  2

// config bit numbers

#define CFG_BASE_16   2048
#define CFG_BASE_18   3456
#define CFG_BASE_20   2560
#define CFG_BASE_20RA 3200
#define CFG_BASE_20XV 1600
#define CFG_BASE_22   5808
#define CFG_BASE_26CV 6344
#define CFG_BASE_26V  7800
#define CFG_BASE_600  8154
#define CFG_BASE_750 14364
#define CFG_BASE_18CV8 2664

#define CFG_STROBE_ROW 0
#define CFG_SET_ROW 1
#define CFG_STROBE_ROW2 3

// Atmel power-down row
#define CFG_ROW_APD 59


// Naive detection of the board's RAM size - for support of big Fuse map:
// PIN_A11 - present on MEGA (8kB) or Leonardo (2.5kB SRAM)
//  _RENESAS_RA_ - Uno R4 (32kB)
#if defined(PIN_A11) || defined(_RENESAS_RA_)
#define RAM_BIG
#endif

//ESP32-S2
#if CONFIG_IDF_TARGET_ESP32S2 == 1
#define RAM_BIG
#endif


// common CFG fuse address map for cfg16V8 and cfg20V8
// the only difference is the starting address: 2048 for cfg16V8 and 2560 for cfg20V8
// total size: 82
static const unsigned char cfgV8[] PROGMEM =
{
      80,81,82,83,84,85,86,87,88,89,90,91,92,93,94,95,96,97,98,99,100,101,102,103,104,105,106,107,108,109,110,111,
      0,1,2,3,
      145,
      72,73,74,75,76,77,78,79,
      144,
      4,5,6,7,
      112,113,114,115,116,117,118,119,120,121,122,123,124,125,126,127,128,129,130,131,132,133,134,135,136,137,138,139,140,141,142,143,
};

// common CFG fuse address map for cfg16V8AB and cfg20V8AB
// the only difference is the starting address: 2048 for cfg16V8AB and 2560 for cfg20V8AB
// total size: 82
static const unsigned char cfgV8AB[] PROGMEM =
{
      0,1,2,3,
      145,
      72,73,74,75,
      80,81,82,83,84,85,86,87,88,89,90,91,92,93,94,95,96,97,98,99,100,101,102,103,104,105,106,107,108,109,110,111,112,113,114,115,116,117,118,119,120,121,122,123,124,125,126,127,128,129,130,131,132,133,134,135,136,137,138,139,140,141,142,143,
      76,77,78,79,
      144,
      4,5,6,7,
};

// common CFG fuse address map for cfg18V10
// starting address: 3456
// total size 20
static const unsigned char cfg18V10[] PROGMEM =
{
      1, 0, 3, 2, 5, 4, 7, 6, 9, 8, 11, 10, 13, 12, 15, 14, 17, 16, 19, 18
};

// common CFG fuse address map for cfg20RA10
// starting address: 3200
// total size 10
static const unsigned char cfgRA10[] PROGMEM =
{
      0, 1, 2, 3, 4, 5, 6, 7, 8, 9
};

// common CFG fuse address map for cfg20XV10
// starting address: 1600
// total size 31
static const unsigned char cfgXV10[] PROGMEM =
{
  30,
  28, 29,
  20, 21, 22,
  10, 11, 12, 13, 14,
  0, 1, 2, 3, 4,
  27, 26,
  23, 24, 25,
  19, 18, 17, 16, 15,
  9, 8, 7, 6, 5
};

// common CFG fuse address map for cfg22V10
// starting address: 5808
// total size 20
static const unsigned char cfgV10[] PROGMEM =
{
      1,0,3,2,5,4,7,6,9,8,11,10,13,12,15,14,17,16,19,18,
};

// common CFG fuse address map for cfg26CV12
// starting address: 6344
// total size 24
static const unsigned char cfg26CV12[] PROGMEM =
{
      1, 0, 3, 2, 5, 4, 7, 6, 9, 8, 11, 10, 13, 12, 15, 14, 17, 16, 19, 18, 21, 20, 23, 22
};

// common CFG fuse address map for cfg26V12
// starting address: 7800
// total size 48
static const unsigned char cfg26V12[] PROGMEM =
{
      36, 24, 12, 0, 37, 25, 13, 1, 38, 26, 14, 2, 39, 27, 15, 3,
      40, 28, 16, 4, 41, 29, 17, 5, 42, 30, 18, 6, 43, 31, 19, 7,
      44, 32, 20, 8, 45, 33, 21, 9, 46, 34, 22, 10, 47, 35, 23, 11
};

// common CFG fuse address map for cfg6001
// starting address: 8154
// total size 68
static const unsigned char cfg6001[] PROGMEM =
{
  67, 66,
  25, 29, 33, 37, 41, 45, 49, 53, 57, 61,
  60, 56, 52, 48, 44, 40, 36, 32, 28, 24,
  62, 63, 58, 59, 54, 55, 50, 51, 46, 47,
  42, 43, 38, 39, 34, 35, 30, 31, 26, 27,
  2, 5, 8, 11, 14, 17, 20, 23,
  0, 3, 6, 9, 12, 15, 18, 21,
  22, 19, 16, 13, 10, 7, 4, 1,
  64, 65
};

// common CFG fuse address map for cfg6002
// starting address: 8154
// total size 104
static const unsigned char cfg6002[] PROGMEM =
{
  103, 102,
  25, 29, 33, 37, 41, 45, 49, 53, 57, 61,
  60, 56, 52, 48, 44, 40, 36, 32, 28, 24,
  62, 63, 58, 59, 54, 55, 50, 51, 46, 47,
  42, 43, 38, 39, 34, 35, 30, 31, 26, 27,
  101, 100, 99, 98, 97, 96, 95, 94, 93,
  92, 91, 90, 89, 88, 87, 86, 85, 84,
  66, 67, 68, 69, 70, 71, 72, 73, 74,
  75, 76, 77, 78, 79, 80, 81, 82, 83,
  2, 5, 8, 11, 14, 17, 20, 23,
  0, 3, 6, 9, 12, 15, 18, 21,
  22, 19, 16, 13, 10, 7, 4, 1,
  64, 65
};

// TODO: handle those:
/*
30,  // 75: Security?
135, // 70: Powerdown
136, // 71: PinKeeper
137, // 72: reserved1
138, // 73: reserved2
139, // 74: reserved3
*/
static const uint8_t cfgV750[] PROGMEM = {
   0,  3,  6,  9, 12, 15, 18, 21, 24, 27, // S0
   1,  4,  7, 10, 13, 16, 19, 22, 25, 28, // S1
   2,  5,  8, 11, 14, 17, 20, 23, 26, 29, // S2
  31, 35, 39, 43, 47, 51, 55, 59, 63, 67, // S3
  32, 36, 40, 44, 48, 52, 56, 60, 64, 68, // S4
  33, 37, 41, 45, 49, 53, 57, 61, 65, 69, // S5
  34, 38, 42, 46, 50, 54, 58, 62, 66, 70  // S6
};

//   UES     user electronic signature
//   PES     programmer electronic signature (ATF = text string, others = Vendor/Vpp/timing)
//   cfg     configuration bits for OLMCs

// GAL info 
typedef struct
{
    GALTYPE type;
    unsigned char id0,id1;          /* variant 1, variant 2 (eg. 16V8=0x00, 16V8A+=0x1A)*/
    short fuses;                    /* total number of fuses              */
    char pins;                      /* number of pins on chip             */
    char rows;                      /* number of fuse rows                */
    unsigned char bits;             /* number of fuses per row            */
    char uesrow;                    /* UES row number                     */
    short uesfuse;                  /* first UES fuse number              */
    char uesbytes;                  /* number of UES bytes                */
    char eraserow;                  /* row adddeess for erase             */
    char eraseallrow;               /* row address for erase all (also PES) */
    char pesrow;                    /* row address for PES read/write     */
    char pesbytes;                  /* number of PES bytes                */
    char cfgrow;                    /* row address of config bits (ACW)   */
    unsigned short cfgbase;         /* base address of the config bit numbers */
    const unsigned char *cfg;       /* pointer to config bit numbers      */
    unsigned char cfgbits;          /* number of config bits              */
    unsigned char cfgmethod;        /* strobe or set row for reading config */
    PINOUT pinout;
} galinfo_t;

const static galinfo_t galInfoList[] PROGMEM =
{
//                           +fuses          +bits        +uesbytes   +pesrow          +cfgbase
//                           |     +pins     |  +uesrow   |  +eraserow|   +pesbytes    |           +cfg
//   +-- type   + id0 + id1  |     |   +rows |  |   +uesfuse |   +eraseallrow +cfgrow  |           |       + cfgbits          +cfgmethod      +pinout
//   |          |     |      |     |   |     |  |   |     |  |   |    |   |   |        |           |       |                  |               |
    {UNKNOWN,   0x00, 0x00,     0,  0,  0,   0,  0,    0, 0,  0,  0,  0,  8,  0,       0,        NULL    , 0                , 0             , PINOUT_UNKNOWN},
    {GAL16V8,   0x00, 0x1A,  2194, 20, 32,  64, 32, 2056, 8, 63, 62, 58,  8, 60, CFG_BASE_16  , cfgV8AB  , sizeof(cfgV8AB)  , CFG_STROBE_ROW, PINOUT_16V8   },
    {GAL18V10,  0x50, 0x51,  3540, 20, 36,  96, 44, 3476, 8, 61, 60, 58, 10, 16, CFG_BASE_18  , cfg18V10 , sizeof(cfg18V10) , CFG_SET_ROW   , PINOUT_18V10  },
    {GAL20V8,   0x20, 0x3A,  2706, 24, 40,  64, 40, 2568, 8, 63, 62, 58,  8, 60, CFG_BASE_20  , cfgV8AB  , sizeof(cfgV8AB)  , CFG_STROBE_ROW, PINOUT_20V8   },
    {GAL20RA10, 0x60, 0x61,  3274, 24, 40,  80, 40, 3210, 8, 61, 60, 58, 10, 16, CFG_BASE_20RA, cfgRA10  , sizeof(cfgRA10)  , CFG_SET_ROW   , PINOUT_22V10  },
    {GAL20XV10, 0x65, 0x66,  1671, 24, 40,  40, 44, 1631, 5, 61, 60, 58,  5, 16, CFG_BASE_20XV, cfgXV10  , sizeof(cfgXV10)  , CFG_SET_ROW   , PINOUT_22V10  },
    {GAL22V10,  0x48, 0x49,  5892, 24, 44, 132, 44, 5828, 8, 61, 60, 58, 10, 16, CFG_BASE_22  , cfgV10   , sizeof(cfgV10)   , CFG_SET_ROW   , PINOUT_22V10  },
    {GAL26CV12, 0x58, 0x59,  6432, 28, 52, 122, 52, 6368, 8, 61, 60, 58, 12, 16, CFG_BASE_26CV, cfg26CV12, sizeof(cfg26CV12), CFG_SET_ROW   , PINOUT_22V10  },
    {GAL26V12,  0x5D, 0x5D,  7912, 28, 52, 150, 52, 7848, 8, 61, 60, 58, 12, 16, CFG_BASE_26V , cfg26V12 , sizeof(cfg26V12) , CFG_SET_ROW   , PINOUT_22V10  },
    {GAL6001,   0x40, 0x41,  8294, 24, 78,  75, 97, 8222, 9, 63, 62, 96,  8,  8, CFG_BASE_600 , cfg6001  , sizeof(cfg6001)  , CFG_SET_ROW   , PINOUT_600    },
    {GAL6002,   0x44, 0x44,  8330, 24, 78,  75, 97, 8258, 9, 63, 62, 96,  8,  8, CFG_BASE_600 , cfg6002  , sizeof(cfg6002)  , CFG_SET_ROW   , PINOUT_600    },
    {ATF16V8B,  0x00, 0x00,  2194, 20, 32,  64, 32, 2056, 8, 63, 62, 58,  8, 60, CFG_BASE_16  , cfgV8AB  , sizeof(cfgV8AB)  , CFG_STROBE_ROW, PINOUT_16V8   },
    {ATF20V8B,  0x00, 0x00,  2706, 24, 40,  64, 40, 2568, 8, 63, 62, 58,  8, 60, CFG_BASE_20  , cfgV8AB  , sizeof(cfgV8AB)  , CFG_STROBE_ROW, PINOUT_20V8   },
    {ATF22V10B, 0x00, 0x00,  5892, 24, 44, 132, 44, 5828, 8, 61, 62, 58, 10, 16, CFG_BASE_22  , cfgV10   , sizeof(cfgV10)   , CFG_SET_ROW   , PINOUT_22V10  },
    {ATF22V10C, 0x00, 0x00,  5892, 24, 44, 132, 44, 5828, 8, 61, 62, 58, 10, 16, CFG_BASE_22  , cfgV10   , sizeof(cfgV10)   , CFG_SET_ROW   , PINOUT_22V10  },
    {ATF750C,   0x00, 0x00, 14499, 24, 84, 171, 84,14435, 8, 61, 60,127, 10, 16, CFG_BASE_750 , cfgV750  , sizeof(cfgV750)  , CFG_STROBE_ROW2, PINOUT_22V10 }, // TODO: not all numbers are clear
    {PEEL18CV8, 0x00, 0x00,  2696, 24, 36,  74, 0,     0, 0,  0,  0,  0,  0, 74, CFG_BASE_18CV8, NULL    , 32               , 0              , PINOUT_18CV8 },

};
galinfo_t galinfo __attribute__ ((section (".noinit"))); //preserve data between resets
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
void loop() {


    // read a command from serial terminal or COMMAND_NONE if nothing is received from serial
    char command = handleTerminalCommands();

    // any unexpected input when uploading fuse map terminates the upload process
    if (isUploading && command != COMMAND_UTX && command != COMMAND_NONE) {
      Serial.println(F("ER upload aborted"));
      isUploading = 0;
      lineIndex = 0;
    }

    // handle commands received from the serial terminal
    switch (command) {
      
      // print some help
      case COMMAND_HELP: {
        printHelp(1);
      } break;

      case COMMAND_IDENTIFY_PROGRAMMER : {
        printHelp(0);
      } break;

      // verify fuse-map bits and bits read from the GAL chip
      case COMMAND_VERIFY_FUSES: {
        if (mapUploaded) {
          if (doTypeCheck()) {
            readOrVerifyGal(1); //just verify, do not overwrite fusemap
          }
        } else {
          printNoFusesError();
        }
      } break;

      // handle upload command - start the download of fuse-map
      case COMMAND_UPLOAD: {
        short i;
        // clean fuses
        for (i = 0; i < MAXFUSES; i++) {
          fusemap[i] = 0;
        }
        sparseSetup(1);
        isUploading = 1;
        uploadError = 0;
      } break;

      // command of the upload protocol
      case COMMAND_UTX : {
        parseUploadLine();
      } break;

      // read and print the PES
      case COMMAND_READ_PES : {
        char type;
        if (gal == PEEL18CV8) {
            printUnsupportedError();
        } else {
            readPes();
            type = checkGalTypeViaPes();
            parsePes(type);
            printPes(type);
        }
      } break;

      case COMMAND_WRITE_PES : {
        char type;
        if (gal == PEEL18CV8) {
            printUnsupportedError();
        } else {
            type = checkGalTypeViaPes();
            parsePes(type);
            writePes();
        }
      } break;

      // read fuse-map from the GAL and print it in the JEDEC form
      case COMMAND_READ_FUSES : {
        if (doTypeCheck()) {
          readOrVerifyGal(0); //just read, no verification
          printJedec();
        }
      } break;

      // write current fuse-map to the GAL chip
      case COMMAND_WRITE_FUSES : {
        if (mapUploaded) {
          if (doTypeCheck()) {
            writeGal();
            //security is handled by COMMAND_ENABLE_SECURITY command
          }
        } else {
          printNoFusesError();
        }
      } break;

      // erases the fuse-map on the GAL chip
      case COMMAND_ERASE_GAL:
      case COMMAND_ERASE_GAL_ALL: {
        if (doTypeCheck()) {
#if CFG_USE_PEEL
          if (PEEL18CV8 == gal) {
            erasePEEL();
          } else
#endif /* CFG_USE_PEEL */
          {
            eraseGAL(COMMAND_ERASE_GAL_ALL == command ? 1 : 0);
          }
        }
      } break;

      // sets the security bit
      case COMMAND_ENABLE_SECURITY: {
        if (doTypeCheck()) {
          secureGAL();
        }
      } break;

      // keep atmel power-down feature enabled during write
      case COMMAND_ENABLE_APD: {
        setFlagBit(FLAG_BIT_APD, 1);
        Serial.println(F("OK APD set"));
      } break;

      case COMMAND_DISABLE_APD: {
        setFlagBit(FLAG_BIT_APD, 0);
        Serial.println(F("OK APD cleared"));
      } break;

      // toggles terminal echo
      case COMMAND_ECHO : {
        echoEnabled = 1 - echoEnabled;
      } break;

      case COMMAND_TEST_VOLTAGE : {
        testVoltage(20);
      } break;

      case COMMAND_SET_GAL_TYPE : {
        char type = line[1] - '0';
        if (type >= 1 && type < LAST_GAL_TYPE) {
          // ensure PEEL IC operations run on a new type of Aftburner PCB with a shift register IC
          if ((PEEL18CV8 == (GALTYPE) type) && (!varVppExists)) {
            printUnsupportedError();
            break;
          }
          gal = (GALTYPE) type;
          copyGalInfo();
          if (0 == flagBits & FLAG_BIT_TYPE_CHECK) { //no type check requested
            setGalDefaults();
          }
        } else {
          Serial.print(F("ER Unknown gal type "));
          Serial.println(type, DEC);
        }
      } break;
      case COMMAND_ENABLE_CHECK_TYPE: {
        setFlagBit(FLAG_BIT_TYPE_CHECK, 1);
      } break;
      case COMMAND_DISABLE_CHECK_TYPE: {
        int i = 0;
        while(i < 12){
            pes[i++] = 0;
        }
        setFlagBit(FLAG_BIT_TYPE_CHECK, 0);
      } break;

      case COMMAND_MEASURE_VPP: {
        measureVppValues();
      } break;

      case COMMAND_MEASURE_CUSTOM: {
#if CFG_USE_PEEL
        if (PEEL18CV8 == gal) {
            measureVoltagesPEEL();
        } else
#endif /* CFG_USE_PEEL */
        {
            printUnsupportedError();
        }
      } break;

      // calibration offset helps to offset the resistor tolerances in voltage dividers and also
      // small differences in analog ref which is ~3.3 V derived from LDO.
      case COMMAND_CALIBRATION_OFFSET: {
        int8_t offset = line[1] - '0';
        if (offset >=0 && offset <= 64) {
          //0:-0.32V 1:-0.31V  2: -0.30V  ... 32:0V  33:0.01V 34: 0.02V ... 64:0.32V
          calOffset = offset - 32;
          Serial.print(F("Using cal offset: "));
          Serial.println(calOffset);
        } else {
          Serial.println(F("ER: cal offset failed"));
        }
      } break;

      case COMMAND_CALIBRATE_VPP: {
        calibrateVpp();
      } break;
#if USE_JTAG_PLAYER
      case COMMAND_JTAG_PLAYER: {
        startJtagPlayer(line[1] == '1');
        //flush the serial line in case the player ended abruptly
        readGarbage();
      } break;
#endif /* USE_JTAG_PLAYER */

      case COMMAND_EXERCISE: {
        // set pulse duration
        if (line[1] == 'p') {
            // progtime serves as the pulse duration during exercise
            progtime = parse45dec(2, 0);
        } else {
            progtime = 100; // revert back to default prog time
            setFlagBit(FLAG_BIT_EXERCISE, line[1] == '1' ? 1 : 0);
        }
        lastShiftRegVal = 0;
        setupGpios(INPUT);
        pinMode(PIN_ZIF15, INPUT);
        pinMode(PIN_ZIF13, INPUT);
        Serial.println(F("OK"));
      } break;

#if CFG_USE_EXERCISER
      case COMMAND_EXERCISE_SET_PINS: {
        exerciseSetPins(line + 1); // skip the command character
      } break;
#endif /* CFG_USE_EXERCISER */
      default: {
        if (command != COMMAND_NONE) {
          Serial.print(F("ER Unknown command: "));
          Serial.println(line);
        }
      }
    }

    // display prompt character - important for the PC program to check that Arduino
    // finished the desired operation
    if (command != COMMAND_NONE) {
      Serial.println(F(">"));
    }

    // and that's it!
}

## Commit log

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2019-03-24 version 0.2
    * added support for Win32/64 builds
    * fixed Mac OSX serial connection parameters
    [serial_port.h]
2019-04-09 version 0.3
    * fixed reading of configuration bits for 22V10 chips
    * fixed reporting of errors during bitstream upload
    * added GAL type set commmand
    * added NO-CHECK of GAL type command
    * 'i' command now requires to pass the GAL type on
    command line
    * adjusted reporting of VPP to match Afterburner's
    readings
    [afterburner.ino]
2019-04-09 gerbers for PCB v.2.0
    support for 16V8 and 22V10 on the same board
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2019-04-09 Updated README.md
    * added PCB fab info
    * added troubleshoting item - arduino resets
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2019-04-13 hw 1.2 - added pull down resistor to EN pin
    This prevents accidental enablement of VPP during
    Arduino reboot. ATF chips interpreted such state
    as the Erase command and cleared the fuses.
2019-04-13 hw 2.1 - added pull down resistor to EN pin
    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
2020-05-25 ATF16V8B was used cfgV8AB in some places, cfgV8 in others. The chip would read, and write without error, but wouldn't work. Changing all instances of cfgV8 to cfgV8AB in ATF16V8B specific code seemed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
    [afterburner.ino]
2021-06-22 moved the PC app source to the src_pc directory
    This fixes an issue with Arduino IDE which opens all .c files
    (even unrelated) in the same directory when the .ino file is opened.
    Fixes compilation error described in issue #10
    [serial_port.h]
2022-03-26 Support for ATF22LV10. Fixes issue 11
    [afterburner.ino]
2022-03-30 sketch: remember the gal type between arduino resets
    [afterburner.ino]
2022-04-01 version 0.4 - baud rate changed to 57600. Please re-upload .ino sketch.
    After testing with genuine arduino uno I could not make
    it to work reliably using the original baudrate 38400 on
    Windows 7. Linux worked OK, but Windows 7 inserted extra 2
    bytes 0xFE or 0xFF at the beginnig of the serial communication
    (at least that's what arduino read from the serial line).
    Baudrate 57600 so far had no issue, another reliable option
    seem to be 9600.
    [afterburner.ino, serial_port.h]
2022-04-22 serial port: support for keeping the port always opened
    Closing serial port causes Arduino reset on Mac OSX.
    [serial_port.h]
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2022-10-31 Readme.md: ATF16V8BQL supported
    ATF16V8BQL programmed and verified at VPP 10V. The IC works in circuit as well.
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2022-12-15 Schematics: added pull up resistor R4 to SDOUT
    Some GAL IC require pull-up on SDOUT
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2023-01-07 fixed adapter PCB design for GAL20V8
    * added SMT pads for resistors
    * fixed bottom layer status
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2023-01-15 added 3D printed case files
    * use OpenScad to open the design .scad file
    * the design file contains top part, bottom part and on/off switch
    * .stl files are exported for your convenience
    * .stl files can also be exported from OpenScad.
    [aft1x.scad, aft1x_bottom_100p.stl, aft1x_switch_100p.stl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]
2023-01-24 ensure GPIOs are set to Input when not active
    This should prevent accidental damage of the GAL chip
    during insertion into the socket.
    [afterburner.ino]
2023-03-25 Added support for Power-Down pin on ATF16V8C
    The PD feature is now selectively enabled or disabled based
    on the JED contents. Also, when fuses are read the printout
    of the JED file reflects the PD fuse bit state. So, when
    the PD fuse bit is enabled then the JED file contains an extra
    fuse bit set to 1. The ATF22V10C now behaves the same way regarding
    the PD fuse bit (previously Afterburner always disabled the PD
    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
2023-04-07 Sketch: added support for new board design (v 3.0)
    New features:
    * unified socket for 20 pin and 24 devices (including GAL20V8)
    * variable VPP via digi pot
    * VPP measurement via A0 ADC (used for VPP calibration)
2023-04-07 PC app: support for new board design
    Added:
    * detection of the new board design
    * VPP measurement (use 'm' commands)
    * setting of calibration offset (use '-co' parameter)
2023-04-07 sketch: default VPP for non-Atmel chips set as 12V
    Also, the defaults are used if no PES check is requested.
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2023-04-07 removed case - needs a redesign to fit the new board
    [aft1x.scad, aft1x_bottom_100p.stl, aft1x_switch_100p.stl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]
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2023-04-07 bom.txt: added missing R2 resistor
2023-04-07 bom.txt fixed typos
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2023-05-16 sketch: fixed typo when printing GAL22V10 PES
    [afterburner.ino]
2023-05-19 Sketch: support for MCP4151-103 digital pot
    Added support and autodetection of MCP4151 digital pot.
    If MCP4151 is detected then its wiper resolution is halved
    to match the MCP4131 wiper resolution.
    MCP4151-103 is now a drop in replacement for MCP4131-103.
    [aftb_mcp4131.h, afterburner.ino]
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2023-09-17 Fix CFG and UES
    [afterburner.ino]
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2023-10-01 Fix write support for GAL6001/GAL6002
    [afterburner.ino]
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2023-10-07 Add missing case statments
    [afterburner.ino]
2023-10-10 Initial support for Arduino UNO Minima (Renesas MCU)
    This change handles EXTERNAL vs AR_EXTERNAL definitions of ADC constants
    as defined on different Arduino platforms (Atmega vs Renesas).
    Also an ADC gain error is compensated for Uno R4. The compensation
    values are work-in-progress as I only have a single Uno R4, which
    might no produce typical ADC values. That means Uno R4 needs more testing
    reports while calibrating the VPP voltages.
    [aftb_vpp.h]
2023-10-30 Fix UES bytes on verify
    [afterburner.ino]
2023-10-30 Fix 18V10 UES writing
    [afterburner.ino]
2023-11-04 sketch: added gal type value to the error message
    [afterburner.ino]
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2023-11-04 sketch: fixed compilation error after merge, removed strncmp dependency
    [afterburner.ino]
2023-11-05 Fix upload and 26v12 bits
    [afterburner.ino]
2023-11-21 Actually fix pinout in the first few rows
    [afterburner.ino]
2023-11-21 Fix incorrect fuse uploading
2023-11-21 PCB design and gerbers: added adapter for GAL26V12
    The adapter is based on RomBor's 26V12 adapter for GALmate.
2024-01-28 mcp4131: fixed reading pot value from mcp4151
    Discovered and fixed by Hubert H. Thanks!
    See issue #48
    [aftb_mcp4131.h]
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2024-02-04 Fixed B9 command bug
    Fixed B9 command bug
    Fixed a typo
    [afterburner.ino]
2024-02-04 Minor changes in aftb_vpp.h
    Added a dummy conversation after setting the analog reference
    Print out pot type (4131/4151) if VPP_VERBOSE is set
2024-02-04 Fixed B9 command bug
    Fixed: Command 'B9' (Calibration Offset = 0,25V) doesn't work
    Note: Also requires elimination of a bug in the PC program afterburner.ino
    Added: Sending B4, if b /wo -co is executed
2024-02-05 Sketch: adjust VPP for all GALs
    Previously all GALs had their VPP (programming voltage) reduced by 2V.
    That was based on old Afterburner design which did not have variable VPP
    control. It was trivial to adjust and experiment with VPP by turning the POT.
    The software for the new design uses the VPP information encoded in PES
    to set the VPP voltage (except Atmel GALs where the VPP value was hardcoded
    to be effectively 10V) programmatically. The reduction of VPP by 2V on
    the new design works, but is just on the very edge of correct functionality.
    For example undervolting the 10V VPP to 9.87V made the Atmel chip programming
    unreliable (many verification errors). This change reduces the voltage
    b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
    [afterburner.ino]
2024-02-16 sketch: small fixes to setVpp() function
    - ATF22V10C uses lower VPP when reading PES
    - PES reading VPP for ATF was raised from 10V to 10.5V
    - out-of-band VPP was set to actual 12V (previously 10V by mistake)
    [afterburner.ino]
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2024-02-16 sparse fusemap: use 32 bit fuse blocks
    Previously 16 bit fuse blocks were used and block types were stored in 1 bit.
    That did not allow to compact fusemaps where all bits were 1 - which is
    typically after the fuses are erased. So fuses of an erased chip would
    not fit into the sparse memory array. The solution was to extend the fuse
    block type storage from 1 bit to 2 bits and use that extra space to mark
    blocks as sparse when all bits in the block are 1's. Such block is now
    block type 3. To keep the fuseType array the same size as it was (128
    bytes) the size of the block was extended from 16 bits to 32 bits.
    The block type is now:
    0 - all bits in the fuse block are 0, no block data in the fu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
    [aftb_sparse.h, afterburner.ino]
2024-02-16 sparse fusemap: added support for compacting
    Compacting searches for fuse blocks where all 32 bits are set
    to 1. If such block is found then it is removed from the
    fuse array (reducing its top position) and then the fuse type
    of such block is changed to 3.
    Note that the fuse bit is never changed from 1 to 0, therefore
    there is no need to cover these cases in the code (ie. converting
    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
2024-02-16 PC app: increase maximum wait time for operations
    This fixes reading erased ATF750C when using sparse fusemap.
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2024-03-17 improve calibration offset resolution and range
    range: -0.32V to +0.32V
    steps: by 0.01V
2024-03-17 pc app: calibration takes longer time, wait longer
    This is because the voltage settle time delay was increased
    and also now 255 taps are scanned.
2024-03-17 sketch: improved calibration, mcp4151 uses full tap scale
    This change stores the digi pot indices in the scale 1-255
    (previously 1 -128) so the stored values for calibration
    are no longer valid after this change is uploaded to Arduino.
    Please re-run the full calibration on your Afterburner!
    [aftb_mcp4131.h, aftb_vpp.h]
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2024-03-18 README.md updated info about tap indices during calibration
    The latest calibration indices are 2x higher than in previous version.
2024-03-19 PC app: fix serial port read buffer overflow
    Overflow happened when verbose printouts were enabled
    in the Arduino sketch.
2024-03-19 Sketch: reduced duration on VPP ramp-up
    The VPP ramp-up was too long after the change of the calibration
    scale in recent commits.
    [aftb_vpp.h]
2024-03-22 sketch: setPinMux: unset internal pull-up on DOUT when inactive
    See issue #61
    [afterburner.ino]
2024-03-23 PC app: fix progress bar compatibility
    The proress bar cusros hiding/revealing sequence was not
    compatible with some Windows versions / shells.
    This fix removes the escaped sequences and ensures the progress
    bar is fully printed at the end of each iteration, which prevents
    the visual artefacts caused by the jumping cursor.
2024-03-23 PC App: guesses the serial port device name
    When the serial device name is not passed with paramerer -d
    then the PC app will try to find an existing serial device.
    * On Windows: selects the COM device with the highest number.
    * On Linux: selects the serial usb device in any order, but
    priority is given to devices with Arduino name.
    * ON MAC OS: selects the last /dev/tty.* or /dev/tty/wchusb*
    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
2024-04-12 PC app: print file size of JED or XSVF in verbose mode
2024-04-12 PC app: play JTAG file: improved progress bar updates
    When the chunk sizes were not power of 2 the progress bar
    updates were irregular. This change ensures that any
    upload progress is regularly updated."
2024-04-12 jtag player: reduce serial buffer size to 62 bytes
    Values bigger than 63 bytes seem to cause issue on AVR MCUs.
    [jtag_xsvf_player.h]
2024-04-12 PCB: updated ATF150X adapter
    Previously the TDO pull-up was not properly connected
    to VCC. The Rev.2 adapter can still be used, either
    without the pull-up or with a small mod-wire to
    connect the pull-up with the VCC."
2024-04-20 xsvf: added support for ATF150XASV (3.3V)
    The IDCODE check mask was updated to support:
    ATF1502ASL: 0150203F or 0150303F
    ATF1502ASV: 0151203F or 0151303F
    ATF1504ASL: 0150403F or 0150503F
    ATF1504ASV: 0151403F or 0151503F
    The ID codes were found on https://bsdl.info
2024-04-20 jtag: fuseconv.py: added support for ATF150XASV (3.3V)
    The converted code ID check will match either AS or ASL or ASV
    flavours of the ATF150X ICs.
2024-04-20 PC app: jtag: better handling of new line characters
    Previously the new line characters were expected to be
    part of the feed request message. This is not so on
    ESP32 based Arduino library implementation. The new
    line characters arrive later on separately after a small
    pause This code change fixes 'corrupted feed request'
    warning messages on such Arduino platforms.
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2024-04-24 jtag: fix compilation warning
    [jtag_xsvf_player.h]
2024-04-24 jtag: added debugging pp symbol to ignore failed matches
    This can help printing data register when a mismatch
    occurs.
    [jtag_xsvf_player.h]
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2024-04-26 new PCB design v. 3.2
    * Optional voltage booster on the board which can replace
    the mt3608 module. If mt3608 module is used the area on
    the board under the module is left unsoldered.
    * Optional SPI RAM for future use to support bigger GALs/CPLDs
    on the UNO board. Not currently used by any GAL.
    * Support for 3.3V Arduinos by splitting the 5V power rail and
    IOREF power rail. Very old Arduino UNOs R2 without IOREF
    header pin can use a solder bridge JP1 (marked as Vx on the
    bottom of the board) to join the 5V rail and IOREF power rail.
    * HW support for internal AREF which is used to measure VPP.
    There is an extra footprint on the bottom of the board
    to solder another attenuation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
2024-09-30 PC App: fixed logical operator when printing big ram info
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2025-05-23 fixed Erase All (including PES) on GAL22V10
    Tested on GAL22V10D and GAL22V10B.
    [afterburner.ino]
2025-05-23 fixed PES write for GAL22V10 - fix submitted by @ceteras
    See issue #71
    Verified on GAL22V10D and GAL22V10B.
    [afterburner.ino]
2025-06-21 fixed PES write for GAL26V12 and GAL26CV12 - fixed by @ceteras
    [afterburner.ino]
2025-07-13 PC App: improved Afterburner detection after plug-in and reprogramming
    Previously, the first operation after the Arduino was reprogrammed
    or plugged-in silently failed on Linux. This change fixes the issue.
    Afterburner is recognised and operation is performed, although the operation
    takes few more seconds than it normally would.
2025-07-13 fixed PES write for GAL20RA10
    The switch/case was replaced by if/else as it reduces the code
    size by 78 bytes when compiled for Arduino UNO.
    [afterburner.ino]
2025-07-14 sparse fusemap: fixed infinite loop caused by comparison of different signedness
    Previously the comparison of signed variable 'i' and unsigned
    variable 'dataPos' caused infinite loop when 'dataPos' was 0.
    [aftb_sparse.h]
2025-07-15 fixed ATF750C fusemap for macrocels Q0 to Q4
    The fusemap for certain macrocels in ATF750C is not mapped
    sequentially. This caused designs that used those macrocels
    malfunctioning when programmed by Afterburner.
    Michael D. (the original author of ATF750C support code)
    had the mapping fix in his fork in commit 9ba72bb21d which
    I overlooked. Mea culpa.
    An ATF750C device was tested with a design exercising
    2 flip-flops, each clocked by independent clock pin and
    the example now works OK.
    [afterburner.ino]
2025-09-07 Added enclosure/case model in OpenScad format and STL files for 3D prints.
    3 files are required to complete the enclosure:
    top, bottom and switch button
    There are 2 variants of the enclosure exported into STL files:
    1) UNO R3 with USB-B connector.
    2) UNO R4 with USB-C connector.
    Both options might work with some UNO clones.
    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
    [aft3x.scad, aft3x_bottom_usbb.stl, aft3x_bottom_usbc.stl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]
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2025-10-19 PEEL: added support for measuring adapter voltages
    The function helps to verify the PEEL adapter
    works correctly by measuring voltages produced
    by the toggling of adapter's MOSFETs.
    MOSFETs are delicate to hand-solder as they
    can be damaged by high soldering temperature.
    Measuring adapter's voltages ensures the MOSFETs
    work as intended.
    [aftb_peel.h, afterburner.ino]
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2025-11-02 added PEEL18CV8 adapter image
    Both TH and SMT builds are shown. Note that the TH build
    uses 4 x 100 Ohm (0.25W) resistor to form a 1W 100 Ohm resistor.
    The SMT build uses 2 x 200 Ohm (0.5W) resistor to do the same.
    The TH build has also all N-MOSFETs soldered in reverse compared
    to guides on silk screen. This is because the N-MOSFETS supplied
    by a local seller had the Source/Drain pins swapped compared to
    BS170 MOSFET datasheet.
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2025-12-05 Adapter Exerciser: added design files
    [bom.csv]
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2025-12-06 exerciser: use INPUT_PULLUP fo High impedance state
    The adapter revision 2 no longer uses external pull-up
    resistors to indicate Z state, therefore the internal
    pull-ups are used.
    [aftb_exercise.h]
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
